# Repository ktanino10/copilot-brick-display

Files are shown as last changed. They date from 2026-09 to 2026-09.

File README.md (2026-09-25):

# Copilot Brick Display — public template

**[3案を回して見る・ダウンロード](https://ktanino10.github.io/copilot-brick-display/?rev=5.0-legible-plaques)**
 · **[作り方](docs/build.ja.md)** · **[Fork → Issue → AI → PRで文字を変える](docs/customize.ja.md)**

**個人向けB（本人公開許可済み）：**
[説明・作り方](https://ktanino10.github.io/copilot-brick-gift-b/) ／
[3D工程](https://ktanino10.github.io/copilot-brick-gift-b/guide/index.html) ／
[写真記録](https://ktanino10.github.io/copilot-brick-gift-b/docs/BUILD-LOG.html)。
別サイトへの案内です。この汎用版の `USER` 表記・匿名化写真・印刷データはそのままです。

**別PCで印刷する方へ：[色別ファイルの選び方と、黒→白の手動色替え](https://ktanino10.github.io/copilot-brick-display/guide.html?guide=separate-color-2026-09-19#print-another-pc)**
— A/B/Cを1案だけ選び、最初は試験片から。銘板・右ロゴの白い部分は一体レリーフで、途中の色替えが必要です。

**印刷した部品がどこに入るか分からない方へ：[ファイル → slot → 組立場所の対話3Dガイド](https://ktanino10.github.io/copilot-brick-display/assembly-guide/index.html)**
— 印刷順と組立順は違います。Bの最初は **`B-black-02.3mf` のslot 3 → `B-001`**。
[3D仕分け図・最初の台座アニメと使い方](docs/assembly.ja.md) ／ [Bのオフライン版](site/assembly-guide/B-offline.zip)。

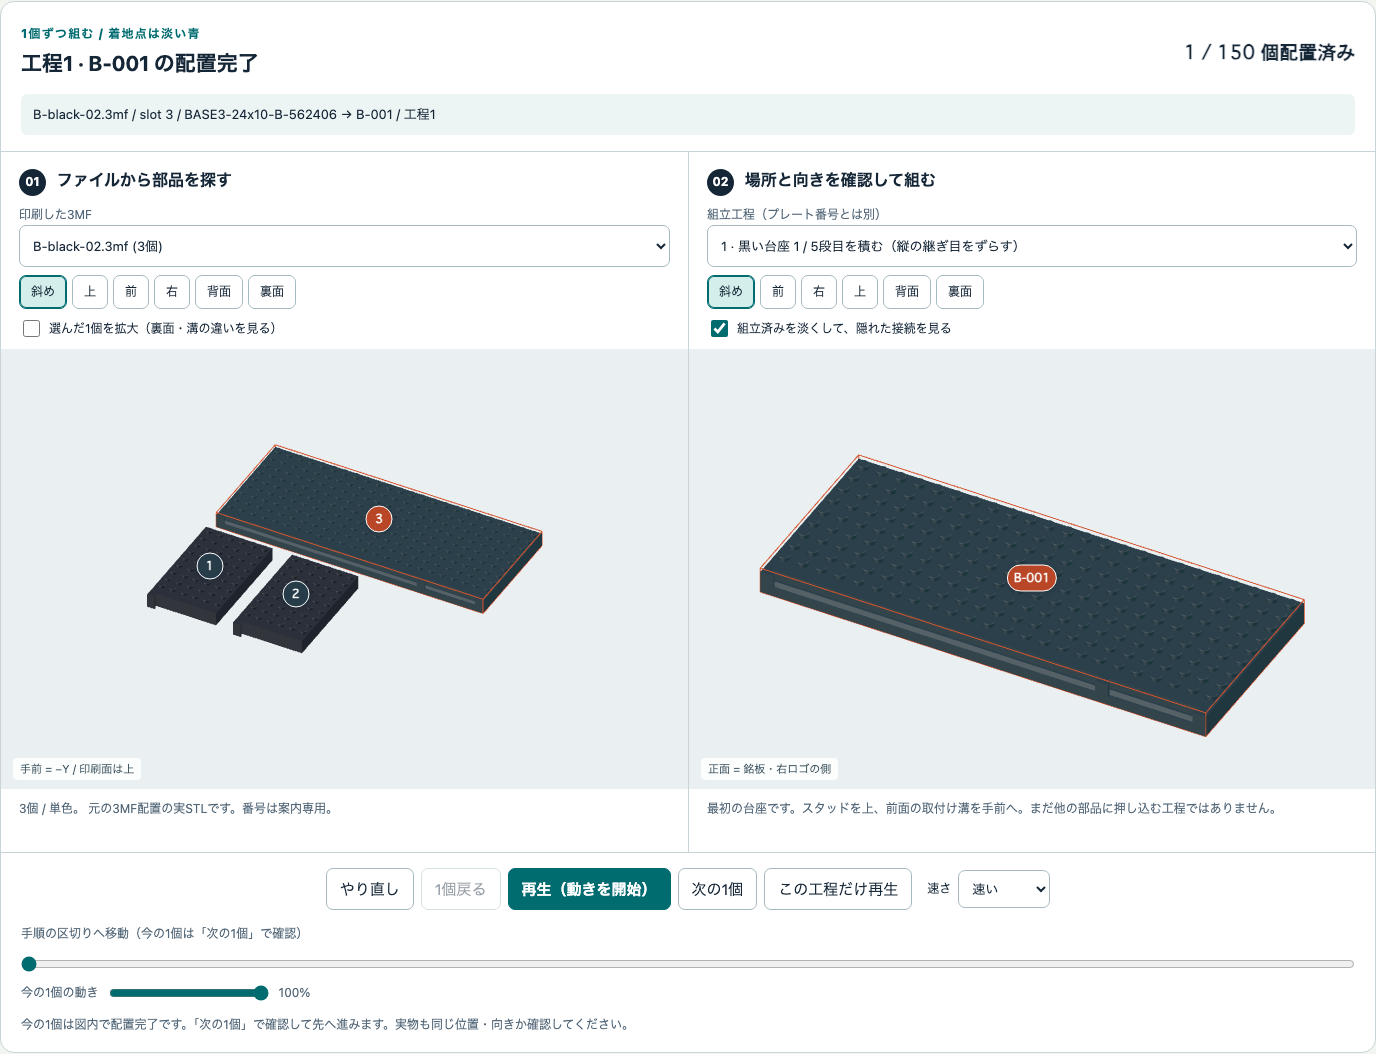
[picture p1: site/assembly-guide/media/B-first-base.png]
Bの印刷プレート内slot 3と最初の組立B-001を結ぶ実STL表示


**[実物の制作記録：個人向けBが完成しました（2026-09-25）](docs/build-log.ja.md#build-2026-09-25)**

本人の「これで完成ですね」という報告と、ゴーグル上枠・紫頭頂まで揃った完成写真を追加しました。
[9/23の台座](docs/build-log.ja.md#build-2026-09-23)・[9/24の顔下部](docs/build-log.ja.md#build-2026-09-24)からの記録も残しています。
写真の紫・黄は実制作例の配色です。設計配色は変えず、測定・版照合の範囲は制作ログに分けて記載しています。
[企画 → 設計 → 3Dプリント → 超音波洗浄 → アッセンブリーの制作フロー](docs/build-log.ja.md#flow-planning)と、
[印刷・超音波洗浄の2本の動画をページ内で見る](https://ktanino10.github.io/copilot-brick-display/build-log.html#printing-video)導線も用意しました（YouTube欄はオンライン限定）。

公開リビジョンは **`5.0-legible-plaques`**。黒い台座5段、大きい2行、正面右のロゴ、
無接着で交換できる前面部品を持つ非公式の卓上オブジェです。
公開の銘板は実際のCAD形状として次の仮表示を使います。実在の個人プロフィールではありません。

> Same icon, New adventures<br>
> github.com/USER

**[文字を印刷しやすくした改訂内容・実CAD比較](docs/lettering.ja.md)**：
2行目を全案10 mm、白文字を1.2 mm高へ。孔・開口・字間を広げ、背面の取付けと本体68種類は維持しました。
`USER`は実プロフィールへのリンクではない短い仮表記です。まず[文字の小試験片](site/downloads/lettering-coupons.zip)を選んだ案で印刷してください。

個人値はgitignore対象のローカルJSONへ分離できます。公開してよい値を使うforkでは、
Issue・PR・native・画像・動画・Actions artifact・Pagesにも表示されることを確認して、
明示的な公開承認モードを選びます。secretへ入れるだけでは生成物も秘密になる、とは扱いません。

## 同じ8 mmピッチ、3つの配置

| 案 | 完成寸法 W×D×H / mm | 組込部品数 | 特徴 |
| --- | --- | ---: | --- |
| A MINI RELIEF | 143.8 × 64.2 × 187.4 | 91 | 浅い顔、14段＋黒台座5段 |
| B DESK CLASSIC | 191.8 × 80.2 × 238.6 | 150 | 標準型、19段＋黒台座5段 |
| C DISPLAY SCULPT | 239.8 × 112.2 × 286.6 | 228 | 厚い側面、24段＋黒台座5段、最下段2分割 |

寸法は台座と最上部スタッド込み、部品数は銘板・ロゴ・3個のキーパー込み、試験片は別です。
文字以外の68種類のSTL、各案の配置・幅・高さ・接続寸法を維持しています。文字が0.4 mm厚くなった分だけ完成奥行きが増えています。
完成Cが256 mmより高くても、分割した各印刷部品はP1Sの公称造形体積内に収まります。
STLの一律拡大・縮小はしません。AMS・電子部品・接着剤・追加購入金具は不要です。

| 案 | FreeCAD | STEP | 印刷セット | 寸法・組立図 | Blender | 実組立動画 |
| --- | --- | --- | --- | --- | --- | --- |
| A | [FCStd](site/downloads/A/A.FCStd) | [STEP](site/downloads/A/A.step) | [ZIP](site/downloads/A/print-kit.zip) | [PDF](site/downloads/A/drawings.pdf) | [blend](site/downloads/A/A.blend) | [MP4](site/media/A-assembly.mp4) |
| B | [FCStd](site/downloads/B/B.FCStd) | [STEP](site/downloads/B/B.step) | [ZIP](site/downloads/B/print-kit.zip) | [PDF](site/downloads/B/drawings.pdf) | [blend](site/downloads/B/B.blend) | [MP4](site/media/B-assembly.mp4) |
| C | [FCStd](site/downloads/C/C.FCStd) | [STEP](site/downloads/C/C.step) | [ZIP](site/downloads/C/print-kit.zip) | [PDF](site/downloads/C/drawings.pdf) | [blend](site/downloads/C/C.blend) | [MP4](site/media/C-assembly.mp4) |

文字とロゴは独立した実レリーフです。黒から白へ、銘板は2.4 mm、ロゴは2.8 mm層後に手動色替えします。
キーパーを上へ6 mm、手前へ32 mm以上外して脇に置き、そのモジュールを45 mm以上上抜きして交換します。
3D分解100%は下側を下へ、上側を上へ広げ、段間は18.2 mm以上。表示用移動で、物理シミュレーションではありません。

## 作る前に

- [7個だけ、段階を分けて試す](docs/trial.ja.md) — 別試験の「扱いにくい・穴が塞がる」という失敗観察を反映。形状を変えず代表部品を少量選択。
- [初心者向けの作り方](docs/build.ja.md) — 条件照合、レイヤープレビュー、男女coupon、仕分け、組立・交換・停止条件。
- [設計の根拠](docs/design.md)／[再生成](docs/rebuild.md)／[公開・privateの文字変更](docs/customize.ja.md)。
- [公開テンプレートの検査記録](site/downloads/validation.json) — native、mesh、描画、配布物とprivate出力経路の検査を区別。

**実物の嵌合・keeper保持・PLA強度・耐久性・転倒は未試験です。**
個人向けBの[制作過程と完成報告](docs/build-log.ja.md#build-2026-09-25)は写真付きで記録し、測定による物理試験とは区別しています。
0.4 mm本体／0.2 mm文字は未実機検証のbaselineです。まず試験片を刷り、閉塞・つかみにくさ・着座不良があれば全数印刷を止めます。
無理押し・打撃・穴を一個ずつ削ることを完成キットの前提にしません。成人向けの屋内装飾品で、玩具安全認証はありません。

## プライバシーと権利

個人向けの旧配布と関連する到達可能な公開履歴を清掃し、元データはprivateに保管しています。
未選択の個別バリエーションは公開配布していません。
**GitHub側の旧SHAオブジェクトや外部キャッシュまで完全消去できたとは主張しません。**
[清掃範囲・残存限界・再混入防止](docs/privacy.md)を参照してください。

GitHub・LEGO・Bambu Labの公認商品ではありません。包括ライセンスは未設定です。
フォント・Three.js等の[noticeと権利条件](docs/licensing.md)を確認してください。

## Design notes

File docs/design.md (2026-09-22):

# Revision 3 / Five-course base and independent front modules

Current normal-model revision: **`5.0-legible-plaques`**.

**Manufacturing guidance update `trial-2026-09-19`: no geometry change.**
A [separate public 4 mm trial report](https://github.com/ktanino10/octoprints-brick-kit-downloads/blob/be956ae14d2aac1601a4a2a87f2e49675a36979e/feedback/2026-09-19/README.md)
describes handling difficulty and plastic-obstructed holes. Its actual sliced input/settings and
root cause were not established. This is failure evidence for another design, not a physical
pass for A/B/C or a reason to import its clearance values, media, geometry or license.
Our normal 8 mm stud/tube blocks, shallow keeper sockets and reserved-front-row base/keyway
parts still need layer-preview and real handling checks.
[The staged seven-piece selection](trial.ja.md) adds only unchanged current STL and small BOMs,
reuses existing fit coupons, and stops bulk printing on obstruction, poor grip or failed seating.
The existing 0.4/0.2 mm recommendations remain untested baselines.

The five-course layout is retained, but public message geometry now uses explicit placeholders.
No historical personal preview is republished as evidence for the generic text.
The non-text shape and placement contract is recorded in
[public-template-invariants.json](../design/public-template-invariants.json).
It is not a physical fit, strength or production qualification.

## One geometric source

`design/parameters.json` and `scripts/design.py` define pitch, courses, unique part IDs,
colors/finishes, quantities, placements and numbered steps. `design/catalog.json` is generated
and populated with actual FreeCAD measurements. `scripts/freecad_geometry.py` owns the unchanged
brick family; `scripts/front_nameplate.py` owns the new front interfaces and reliefs.

Actual FreeCAD BREP → FCStd / STEP / mm STL → the same meshes in Blender and the WebGL viewer.
TechDraw projections and planar sections are used for manufacturing drawings. Numbered plan
views are explicitly placement diagrams from the same catalogue. No raster-only or texture-only
lettering/logo substitutes for the delivered solid geometry.

Unchanged face/crest parts keep their original STL hashes and move only **+38.4 mm in Z**.
The source/cache recipes and B preview parts are reused instead of recalculating unchanged solids.
The five-course base is visible throughout the assembly sequence, so affected scenes, drawings
and movie frames are genuinely regenerated from the revised placements.

The unselected individual variant is preserved privately and is not distributed or regenerated.
Normal A/B/C use **`BASE-FRONT-NP3`**. Private historical interfaces and personal inputs are not
fetched from withdrawn revisions to rebuild this public template.

## Nominal references versus design choices

The LEGO-filed patent [WO2019106129A1](https://patents.google.com/patent/WO2019106129A1/en)
describes an approximate 32×16×9.6 mm four-by-two brick and approximate 4.8 mm knobs.
It does not specify this project's FDM tolerances. Museum and community references in
[sources.json](../design/sources.json) support the 8 mm grid / 3.2 mm plate convention
but disagree about some measured stud dimensions.

Our adjustable candidates remain: 1.8 mm stud height, 0.2 mm total body gap, default female
radial clearance +0.04 mm, usual roof 1.6 mm, thin-plate roof 1.0 mm, internal tube bore
3.2 mm and roof ribs 1.2 mm. Internal bores are not a claimed commercial accessory interface.

| Feature | Constraint / default |
| --- | --- |
| Body sides | `0.1 .. 8*n−0.1`; stud centers `4+8*i` |
| Inside-wall coordinate | `4−2.4−c = 1.56 mm`; physical outer wall 1.46 mm |
| Multi-row tube outside radius | `8/sqrt(2)−2.4−c = 3.216854 mm` |
| One-row post radius | `4−2.4−c = 1.56 mm` |
| Tube radial wall | 1.616854 mm |
| Grid ribs | 1.2 mm at nominal row/column boundaries; reference stud clearance ≥1.0 mm |
| Orthogonal roof span | ≤6.8 mm between ribs; tube bores 3.2 mm |
| Thin plate headroom | `3.2−1.0−1.8 = 0.4 mm` |

An ideal reference stud has nominal positive clearance at the default setting. This does not
prove frictional clutch. Independent male-diameter and female-clearance coupons must be printed
and tested with actual commercial and printed mates. PLA is not ABS; do not force, lever or hammer.

## Real five-course bases

| Model | Actual W×D×H, mm | Installed parts | Base blocks / courses | Unchanged face courses |
| --- | --- | --- | --- | --- |
| A | 143.8 × 64.2 × 187.4 | 91 | 15 / 5 | 14 |
| B | 191.8 × 80.2 × 238.6 | 150 | 19 / 5 | 19 |
| C | 239.8 × 112.2 × 286.6 | 228 | 24 / 5 | 24 |

The base body is **48 mm = 5×9.6 mm**, with independent, printable, separable blocks—not one
large solid box with drawn seams. Upper courses alternate six-stud runs and half-offset
three/six-stud runs. C retains two 15×14-stud bottom halves; subsequent courses span their seam.
Each block spans its designed depth, so front and rear are not unrelated thin skins.

The first front 8 mm row is deliberately reserved for the two vertical channels:
its top studs are removed and its underside is reinforced rather than a commercial socket.
Rows starting at Y=12 mm keep the fixed grid. The lowest face parts start at Z=48 mm behind
the front interfaces. Neither the face nor the block pitch is scaled.

C's assembled height exceeding the printer's 256 mm nominal volume is not a printing violation:
only individual parts are printed. The largest B footprint plus 6 mm external brim is
203.8×91.8 mm; each C bottom half plus brim is 131.8×123.8 mm. Actual plate exclusions,
toolpaths, warping and first layers still require a slicer and real print check.

## Two-line message and right-hand logo

The exact text is:

> Same icon, New adventures<br>
> github.com/USER

There is no handle line on the normal models. The standalone raised cyan sign and its old dock
are removed from A/B/C. The current message and logo are black-backed front inserts with white
relief, entirely inside the five-course base at **Z=4..44 mm**.

| Model | Message backing W×H | Main / URL actual cap height | Logo disc / backing width |
| --- | --- | --- | --- |
| A | 102×40 mm | 10 / 10 mm | 28 / 32 mm |
| B | 142×40 mm | 12 / 10 mm | 36 / 40 mm |
| C | 182×40 mm | 14.5 / 10 mm | 40 / 48 mm |

Barlow Condensed Bold is used for the main line, preserving its X scale and declared ink height;
Black is enlarged uniformly to10mm for the shorter URL placeholder. Existing kerning is preserved
when adequate, otherwise additional spacing is inserted. Inner counters and the e's right opening
are enlarged without inflating the entire outline. `USER` is an explicit placeholder, not a profile link.
In B the actual ink widths are132.1301 and77.4228mm within134mm; the carrier remains142×40mm.
See [the measured typography change](lettering.ja.md) and `validation/lettering.json` for
central-band counter chords, actual BRep gaps, approximate open-pocket escape diameters,
straight positive strokes and persistent material-neck indicators. A uses explicitly lower
main-line gap/counter targets to fit without thinning or shortening its text.
These are not physical-print measurements or guarantees for every mathematical curve terminal.

The mark is vectorized from the user-provided black-circle/white silhouette image. Only the
derived normalized outline coordinates and solid relief are published, not the input raster
or its private path. A black carrier supports the black circular pad and all white relief,
including the tail and ears. This is an unofficial personal model, not an endorsed product.

Print both modules rear-face-down. The message carrier is 2.4 mm thick with 1.2 mm raised text.
The logo adds a 0.4 mm black disc before its 0.8 mm white relief. Manual black-to-white changes
occur after **2.4 mm** for text and **2.8 mm** for the logo. These are separate print plates;
do not mix other black blocks into a plate that will change to white. AMS is not required.
The extra0.4mm of text projects forward toY=-0.30, increasing only the assembled depth by0.4mm.
The original68 non-text masters, carrier geometry, installation poses, width and height are unchanged.

## Positive geometry and removal

Each module has a wider rear face and a front face narrowed by 2 mm per X side.
The default receiver side allowance is 0.2 mm; small C15/C20/C25 receiver coupons are provided.
The back-to-front transition is 2.4 mm deep, with a 0.8 mm initial flat back and 1.2 mm vertical
edge relief. The printable widening slope is no steeper than 45° to vertical.

The matching dovetail channels run vertically through the five aligned courses. Shaped bottom
seats stop downward motion. Their side geometry blocks frontward and lateral pulling;
**two message keepers and one separate logo keeper** block upward escape. Keepers engage the
second stud row. Their physical clutch is a calibration requirement, not an assumed certified force.

For replacement, lift the relevant keeper(s) approximately 6 mm, move them at least 32 mm forward and set them aside,
then slide that module straight up at least 45 mm before taking it forward. The other front
module can remain installed. Face parts are behind this path, with nominal Y clearance.
Never lift the entire object by a module, keeper, head or goggles.

Digital checks test final solids, blocked translations, released vertical samples, and the
staged viewer route. They do not prove arbitrary forced motion, elastic deformation, wear,
human grip strength, clutch force or printed durability.

## Strong vertical exploded view

0% is exactly the completed catalogue pose. The initial slider phases first lift the keepers,
move them forward, then lift and move both front modules clear. The forward distance is computed
as at least the keeper's 16 mm nominal depth plus the module's 14 mm forward travel plus a 2 mm
display clearance: 32 mm. The requested minimum `keeper_forward_mm` cannot override that safety envelope. The remaining range separates
courses around a central reference: lower courses move down and upper courses move up.

At 100%, each neighboring body/base course receives 20 mm relative display displacement.
The resulting clear gap, including 1.8 mm studs, is at least **18.2 mm**. All five base courses
participate. Small front modules are displayed below the base only after the safe initial
clearance route. This is explanatory movement, not an instruction to pull the whole model apart
simultaneously or a physical simulation.

Cached local bounds are rotated once and translated per update; no full-vertex scan or new
geometry is created every frame. Camera target, orthographic frustum and clipping use visible
exploded bounds while preserving the current view direction. Actual desktop/mobile 0/50/100%
screenshots, gap checks, return-to-zero, selection and assembly-control checks are release gates.

## Review and physical boundary

One mechanical owner integrates the change; the same separate mechanical reviewer reviews a
fixed changed snapshot and its final presentations. Native reopen, STEP/STL consistency,
watertight meshes, contact/retention geometry, body hashes, BOM/steps, actual Blender scenes,
video decode and public download hashes are recorded separately.

The material centroid is a uniform solid-CAD proxy, not sliced mass or a measured tipping load.
The increased height requires a fresh real-world stability check on a low, flat, safe surface.
Physical fit, printed-thread or stud wear, PLA strength, clutch, heat resistance, print time/mass,
tip resistance and toy safety remain **unverified**. Print the calibration pieces first.

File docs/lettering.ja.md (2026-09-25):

# 銘板の印刷しやすさ — 5.0改訂と小試験片

**公開版の2行は `Same icon, New adventures` / `github.com/USER` です。**
`USER`は短い仮表記であり、実在の人やプロフィールへのリンクではありません。
長い仮文字列を無理に細く収めるのでなく、短い公開例にすることをユーザーが選択しました。
個人向け入力の文言をこの仮表記へ変更する仕組みではありません。

0.2 mmノズルでの試作から「文字が小さい・孔や字間が狭い」というフィードバックを受けた設計候補です。
**この改訂を実機印刷して合格した証拠はまだありません。**
09/23には個人向けBで本人の改善感と台座・前面部品の写真報告が届き、[制作記録](build-log.ja.md)へ追加しました。
09/24の[顔下部を積む途中写真](build-log.ja.md#build-2026-09-24)に続き、09/25は[個人向けBの完成報告と全体写真](build-log.ja.md#build-2026-09-25)を追記しました。写真の実制作色は設計配色と区別しています。
現物に使ったファイル・設定の版は未照合なので、この公開版の実物合格とは扱いません。
糸引きや上面の荒れの原因を写真だけで温度・flow等へ断定していません。
未加工の原写真は載せず、許可された制作記録用の識別情報除去済み画像だけを別ページで示します。

## 変えたもの・変えないもの

主文はBarlow Condensed **Bold**、下段は**Black**です。主文の文字高はA10 / B12 / C14.5 mmを維持し、
URLは全案10 mmへ均等拡大しました。元のkerningを保ち、不足する字間だけを追加します。
閉じた孔の内側と`e`の右出口を広げ、白い文字の高さを0.8→**1.2 mm**にしました。
全行の横圧縮、文字の切捨て、3行化はしていません。

黒い支持体は**2.4 mmのまま**、銘板全厚は**3.6 mm**。各案の裏面・キー溝取付け・顔・台座・右ロゴ・68非文字STLは不変更です。
文字が0.4 mm前へ出た分、完成奥行きはA64.2 / B80.2 / C112.2 mmになりました。
幅・高さ・全配置・組込個数91 / 150 / 228は維持しています。右ロゴの白レリーフは0.8 mmのままです。

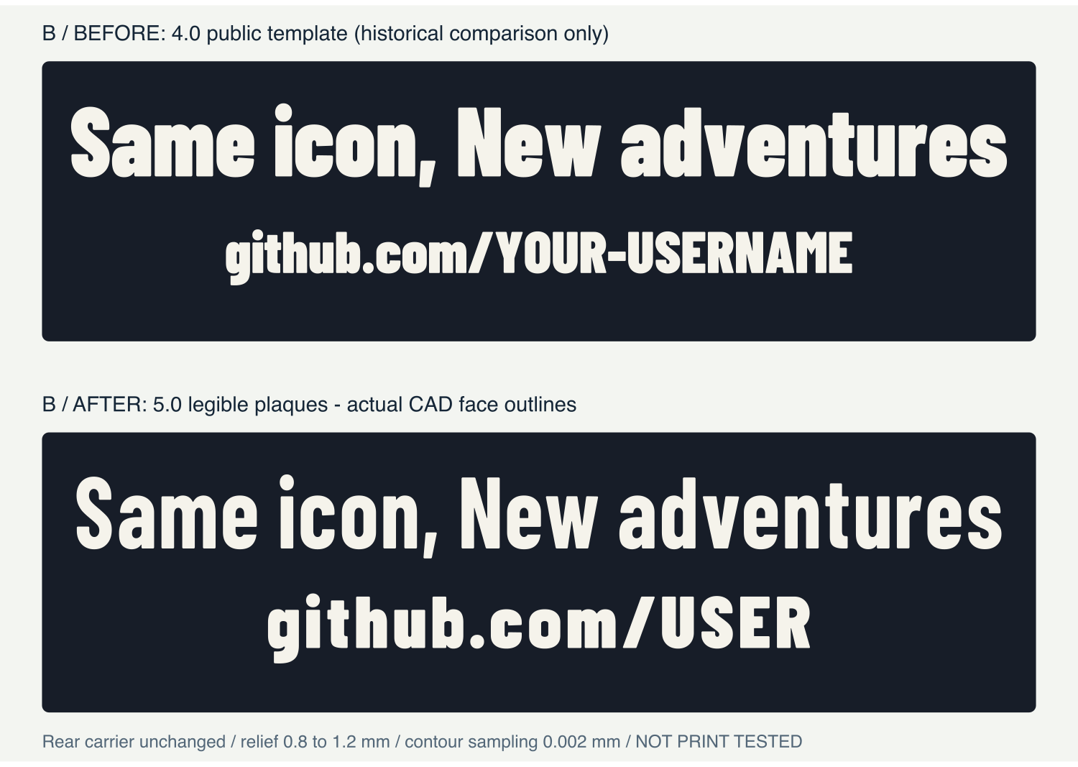
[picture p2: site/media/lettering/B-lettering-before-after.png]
Bの旧4.0と新5.0の実CAD比較。旧データは比較用で、現在の印刷用ではありません


上図は保存済みCADの実面輪郭から作成しています。旧4.0の長い仮表示は**歴史的な比較用**で、印刷用データではありません。
元の旧版はGitの版履歴で区別し、現在のダウンロードには新旧の銘板を混在させません。

## 文字列ごとの実測

| 案・行 | 実文字高 | 実インク幅 / 上限 | 最小字間 | 平行な正の直線幅 | 持続的な材料neck指標 |
| --- | ---: | ---: | ---: | ---: | ---: |
| A 主文 | 10 mm | 93.638 / 94 mm | 0.796 mm | 1.196 mm | 0.85 mm |
| B 主文 | 12 mm | 132.130 / 134 mm | 1.048 mm | 1.261 mm | 1.09 mm |
| C 主文 | 14.5 mm | 167.331 / 174 mm | 1.048 mm | 1.524 mm | 1.34 mm |
| 全案 URL | 10 mm | 77.423 / 各案上限 | 1.048 mm | 1.689 mm | 1.17 mm |

Aの主文は狭い102 mm支持体に収めるため、孔の中央帯目標0.90 mm、`e`出口0.95 mm、字間0.80 mmを明示的に使用します。
B/C主文と全案のURLは孔1.02 mm、`e`出口1.10 mm、字間1.05 mmの目標です。
**A主文を全字1 mm以上と称していません。** 小型の幅を守った選択で、Aの文字試験片を別に確認します。

測定定義はそれぞれ別です。

- **閉counter**：孔の高さ・幅の中央25–75%帯に、それぞれ101本置いた横・縦chordの最小値。
  最大内接円の直径とは異なり、鋭い三角孔の全先端幅を保証しません。
- **c/eの開口**：0.01 mm格子で内側から外へ抜ける経路を測る近似。誤差は約±0.03 mm。
- **字間**：最終BRepの隣接する字形間の実距離。0.002 mm輪郭samplingによる計画値とは最大0.006 mm差を許容し、表は実値です。
- **正の材料**：平行直線の幅と、侵食した時に0.05 mm²以上の2領域へ分裂する最初の幅（半径0.005 mm刻み）を別々に報告。
  全ての曲線先端やスライサーの線幅を保証する値ではありません。

孔を広げても材料が細くなる文字は停止対象です。長い別handleや大文字を入れても、上の結果を引き継げるとは限りません。
生成器は文字列・幅・字間・正の材料を再検査し、未成立を無音で縮小・修復しません。
機械可読の測定は[lettering.json](../site/downloads/lettering.json)で確認できます。

## 本体銘板より先に、選んだ案の文字だけ試す

**[文字試験片ZIP](../site/downloads/lettering-coupons.zip)** を展開し、
選んだA/B/Cに対応する **`GLYPH-A` / `GLYPH-B` / `GLYPH-C` を1個だけ**使います。
STLと3MFは代替ファイルです。同時に読み込まないでください。
上段`aeod`、下段`gbo./R`を、実銘板の字形から**拡大縮小なし**で取り出し、同じ字間目標で並べ直しています。
大きな台座全体を印刷せず、孔・`e`・dot/slash・下段の大小文字を先に確認できます。
この平らな試験片には取付け機構はなく、完成BOMや150個の組立には入りません。

1. 3MFは形状・配置だけの **NOT_SLICED**。実P1S・実際の装着ノズル・PLA・プレートを選びます。mm・100%・平らな黒支持体を下。
2. 実レイヤープレビューで、孔が埋まらないか、細線のpath欠落、隣字間の橋、dot/slashの形を確認します。
3. 黒支持体2.4 mmが終わり、**最初の白い経路を出す前**へPauseを追加します。初層・可変層高で層番号が変わるので固定番号は指定しません。
   白は1.2 mm。標準P1Sの交換・排出・再開操作に従い、未検証G-codeは使いません。
4. 冷めたら孔・出口・字間が開いているか、欠け・白化・反り・糸・上面荒れを確認し、ノギスとスライス画像・条件を記録します。
5. 閉塞、線の脱落、割れがあれば銘板の全数印刷を停止。0.2 mmで解決済みとはみなしません。
   原因不明のまま穴径・XY補正・flow・温度を一括変更せず、現物と経路を照合して一条件ずつ見直します。

実設定入りBambu Studioプロジェクトは未受領です。必要な診断情報は**実際に使った設定入り`.3mf`**であり、
個人情報を含むなら公開IssueやPagesへ置かず、非公開で扱ってください。
文字試験片が成功しても、既存FIT/NP3-FIT、keeper保持、完成品の強度・転倒は別の未検証事項です。

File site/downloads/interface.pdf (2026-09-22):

BRICK PORTRAIT / PUBLIC TEMPLATE / 5-COURSE BASE / DIGITAL PROTOTYPE

# INTERFACE / SECTION & CLEARANCE

Project design candidates, NOT a proprietary tolerance standard. Geometry from FreeCAD planar sections.

SECTION: Y = 4.00 / TWO 2x2 BRICKS

JOINT SECTION: Z = 10.50

Actual wall, tube, rib + mating stud outlines

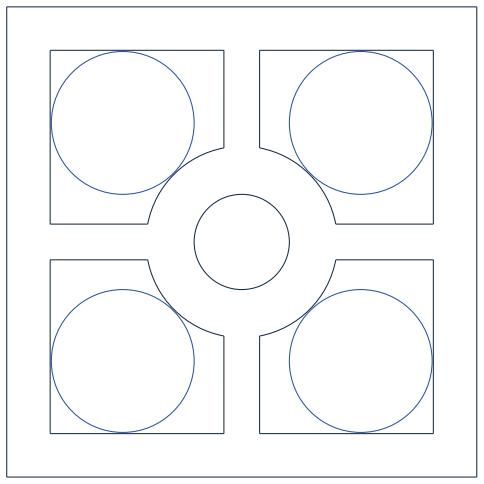
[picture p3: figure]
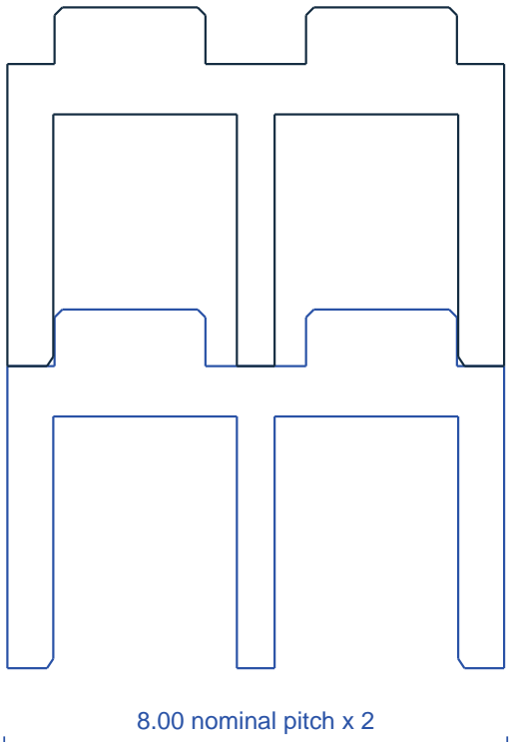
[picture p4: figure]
8.00 nominal pitch x 2

Blue: lower brick / black: upper socket

Reference stud dia 4.80; candidate height 1.80 Radial clearance c=+0.04 (default; untested)

Inside wall offset 1.56 / wall thickness 1.46

Tube OD 6.433708 / ID 3.20; grid rib 1.20

Tip lead-in 0.25 / female lead-in 0.20 x 0.30

Roof 1.60; thin plate roof 1.00

Thin plate / keeper: nominal headroom 0.40

No forced fit. Tune male and female separately.

UNITS mm | Fixed 8 mm pitch | Physical fit / strength / stability NOT tested | Do not scale STL. Calibrate male + female coupons first.

BRICK PORTRAIT / PUBLIC TEMPLATE / 5-COURSE BASE / DIGITAL PROTOTYPE

# NP3 / BASE-FRONT CAPTURE & REMOVAL

Actual BREP sections; precise dimensions apply to the nominal model, not guaranteed printed fit.

B / HORIZONTAL SECTION Z=24 / FRONT 8mm BAND

B message: 142.00

B logo carrier: 40.00

VERTICAL SECTION X=40

48.00

Blue: installed modules; black: actual receiver / keepers

Carrier thickness2.40 / rear flat0.80 / edge relief1.20

Rear width -> front width: 2.00 inset on each X side

Default side clearance0.20; coupon candidates0.15/0.20/0.25

Text frontY=-0.30 / logo frontY=0.10; +0.40mm depth

Both front modules fit in Z=4.00..44.00, inside48mm base

3 separate up-stops: text2 / logo1; stud-grid mounting

Remove: up-stops up6, forward>=32; module up45

Thread / glue / magnet / purchased fastener not required

Physical clutch, retention, flatness and stability NOT tested

UNITS mm | Fixed 8 mm pitch | Physical fit / strength / stability NOT tested | Do not scale STL. Calibrate male + female coupons first.

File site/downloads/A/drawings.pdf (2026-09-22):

### BRICK PORTRAIT / PUBLIC TEMPLATE / 5-COURSE BASE / DIGITAL PROTOTYPE

# A / MINI RELIEF

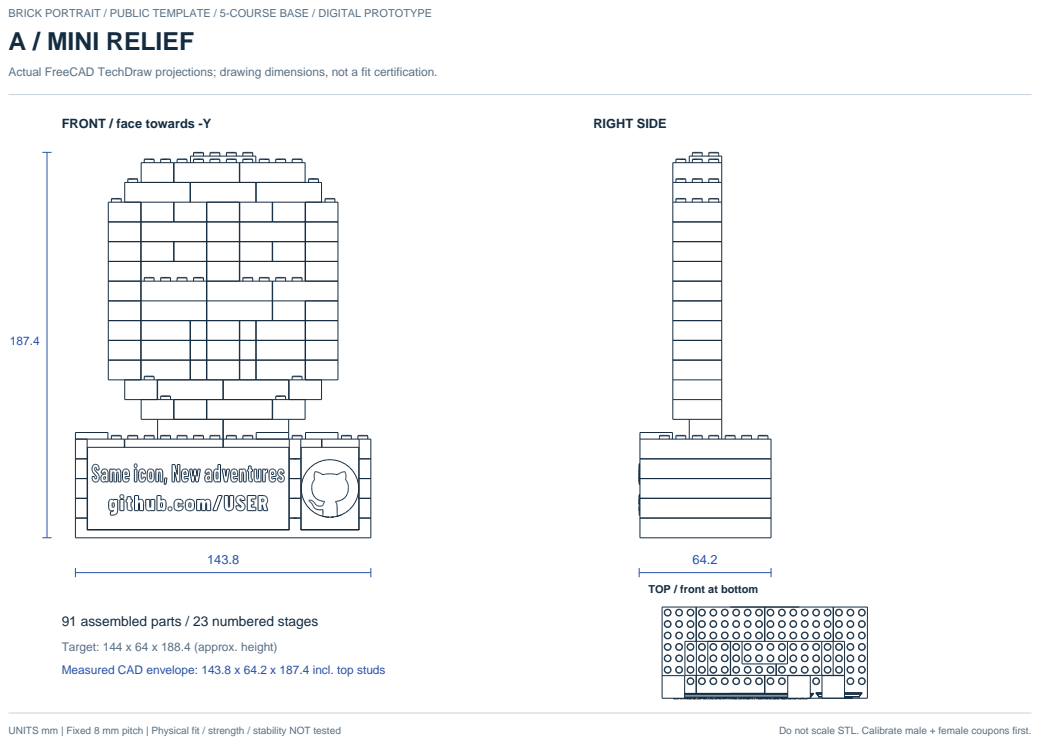
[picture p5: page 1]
RIGHT SIDE; UNITS mm | Fixed 8 mm pitch | Physical fit / strength / stability NOT tested; Do not scale STL. Calibrate male + female coupons first.

Actual FreeCAD TechDraw projections; drawing dimensions, not a fit certification.

FRONT / face towards -Y

TOP / front at bottom

91 assembled parts / 23 numbered stages

Target: 144 x 64 x 188.4 (approx. height)
Measured CAD envelope: 143.8 x 64.2 x 187.4 incl. top studs

# A / EXPLODED ASSEMBLY

CAD-derived exploded view; displacement is illustrative, dimensions are not changed.

# EXPLODED FRONT

Actual solids, displaced only for this view.

Exact WebGL 100% offsets, centered up/down.

Do not measure assembly height here.

Use overview for final outside dimensions.

Insert parts downward in numbered order.

Front modules release before spreading.

Stud engagement != verified physical clutch.

## TEXT / flat printing view

## RIGHT LOGO / supported relief

# INTERFACE / SECTION & CLEARANCE

Project design candidates, NOT a proprietary tolerance standard. Geometry from FreeCAD planar sections.

## SECTION: Y = 4.00 / TWO 2x2 BRICKS

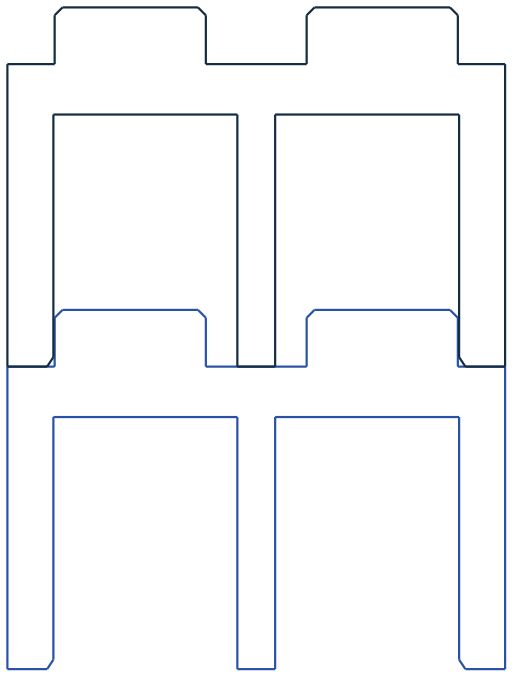
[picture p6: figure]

## 8.00 nominal pitch x 2

## JOINT SECTION: Z = 10.50

### Actual wall, tube, rib + mating stud outlines


### Blue: lower brick / black: upper socket

### Reference stud dia 4.80; candidate height 1.80

### Radial clearance c=+0.04 (default; untested)

### Inside wall offset 1.56 / wall thickness 1.46

### Tube OD 6.433708 / ID 3.20; grid rib 1.20

### Tip lead-in 0.25 / female lead-in 0.20 x 0.30

### Roof 1.60; thin plate roof 1.00

### Thin plate / keeper: nominal headroom 0.40

No forced fit. Tune male and female separately.

# NP3 / BASE-FRONT CAPTURE & REMOVAL

Actual BREP sections; precise dimensions apply to the nominal model, not guaranteed printed fit.

## B / HORIZONTAL SECTION Z=24 / FRONT 8mm BAND

## B message: 142.00

## B logo carrier: 40.00

## VERTICAL SECTION X=40

48.00

## Blue: installed modules; black: actual receiver / keepers

## Carrier thickness2.40 / rear flat0.80 / edge relief1.20

## Rear width -> front width: 2.00 inset on each X side

## Default side clearance0.20; coupon candidates0.15/0.20/0.25

## Text frontY=-0.30 / logo frontY=0.10; +0.40mm depth

## Both front modules fit in Z=4.00..44.00, inside48mm base

## 3 separate up-stops: text2 / logo1; stud-grid mounting

## Remove: up-stops up6, forward>=32; module up45

## Thread / glue / magnet / purchased fastener not required

## Physical clutch, retention, flatness and stability NOT tested

# A / COLOR BOM / 1

One STL geometry may be printed in several colors. Use the quantities for this model only.

PART ID | COLOR | QTY | PRINT FILE
BASE3-03x08-T-48de52 | black | 2 | parts/BASE3-03x08-T-48de52.stl
BASE3-03x08-T-80e081 | black | 2 | parts/BASE3-03x08-T-80e081.stl
BASE3-06x08-T-7532db | black | 2 | parts/BASE3-06x08-T-7532db.stl
BASE3-06x08-T-7f51dc | black | 2 | parts/BASE3-06x08-T-7f51dc.stl
BASE3-06x08-T-9cb610 | black | 4 | parts/BASE3-06x08-T-9cb610.stl
BASE3-06x08-T-b8aa05 | black | 2 | parts/BASE3-06x08-T-b8aa05.stl
BASE3-18x08-B-a4853c | black | 1 | parts/BASE3-18x08-B-a4853c.stl
BR-01x02-H096 | green | 6 | parts/BR-01x02-H096.stl
BR-02x02-H096 | black | 13 | parts/BR-02x02-H096.stl
BR-02x03-H096 | cyan | 14 | parts/BR-02x03-H096.stl
BR-02x03-H096 | magenta | 12 | parts/BR-02x03-H096.stl
BR-03x02-H096 | black | 6 | parts/BR-03x02-H096.stl
BR-04x02-H032 | magenta | 1 | parts/BR-04x02-H032.stl
BR-04x02-H096 | black | 9 | parts/BR-04x02-H096.stl
BR-04x02-H096 | magenta | 2 | parts/BR-04x02-H096.stl
BR-04x03-H096 | cyan | 8 | parts/BR-04x03-H096.stl
NP3-KEEPER | black | 3 | parts/NP3-KEEPER.stl
NP3-LOGO-A | black | 1 | parts/NP3-LOGO-A.stl
NP3-TEXT-A | black | 1 | parts/NP3-TEXT-A.stl

TEXT: black -> white at 2.4mm; LOGO: black -> white at 2.8mm. Separate plates.

Assembly: 91 pieces, including 2 front modules + 3 keepers. Coupons separate.

# A / STEP 01 OF 23

Placement diagram from canonical part bounds. IDs match native CAD, BOM, viewer and animation.

## PLAN VIEW / front at bottom / NEW parts in color

001

## nominal 144 / grid 8.00

## FRONT (-Y) / new parts enter from above (+Z)

# ADD 1 PART(S)

### A-001 BLACK

BASE3-18x08-B-a4853c @ 0,0,0

# A / STEP 02 OF 23

Placement diagram from canonical part bounds. IDs match native CAD, BOM, viewer and animation.

## PLAN VIEW / front at bottom / NEW parts in color

002 | 003 | 004

## nominal 144 / grid 8.00

## FRONT (-Y) / new parts enter from above (+Z)

# ADD 3 PART(S)

### A-002 BLACK

BASE3-06x08-T-b8aa05 @ 0,0,9.6

### A-003 BLACK

BASE3-06x08-T-9cb610 @ 48,0,9.6

### A-004 BLACK

BASE3-06x08-T-7f51dc @ 96,0,9.6

# A / STEP 03 OF 23

Placement diagram from canonical part bounds. IDs match native CAD, BOM, viewer and animation.

## PLAN VIEW / front at bottom / NEW parts in color

005 | 006 | 007 | 008

## nominal 144 / grid 8.00

## FRONT (-Y) / new parts enter from above (+Z)

# ADD 4 PART(S)

### A-005 BLACK

BASE3-03x08-T-48de52 @ 0,0,19.2

### A-006 BLACK

BASE3-06x08-T-9cb610 @ 24,0,19.2

### A-007 BLACK

BASE3-06x08-T-7532db @ 72,0,19.2

### A-008 BLACK

BASE3-03x08-T-80e081 @ 120,0,19.2

# A / STEP 04 OF 23

Placement diagram from canonical part bounds. IDs match native CAD, BOM, viewer and animation.

## PLAN VIEW / front at bottom / NEW parts in color

009 | 010 | 011

## nominal 144 / grid 8.00

## FRONT (-Y) / new parts enter from above (+Z)

# ADD 3 PART(S)

### A-009 BLACK

BASE3-06x08-T-b8aa05 @ 0,0,28.8

### A-010 BLACK

BASE3-06x08-T-9cb610 @ 48,0,28.8

### A-011 BLACK

BASE3-06x08-T-7f51dc @ 96,0,28.8

# A / STEP 05 OF 23

Placement diagram from canonical part bounds. IDs match native CAD, BOM, viewer and animation.

## PLAN VIEW / front at bottom / NEW parts in color

012 | 013 | 014 | 015

## nominal 144 / grid 8.00

## FRONT (-Y) / new parts enter from above (+Z)

# ADD 4 PART(S)

### A-012 BLACK

BASE3-03x08-T-48de52 @ 0,0,38.4

### A-013 BLACK

BASE3-06x08-T-9cb610 @ 24,0,38.4

### A-014 BLACK

BASE3-06x08-T-7532db @ 72,0,38.4

### A-015 BLACK

BASE3-03x08-T-80e081 @ 120,0,38.4

# A / STEP 06 OF 23

Placement diagram from canonical part bounds. IDs match native CAD, BOM, viewer and animation.

## PLAN VIEW / front at bottom / NEW parts in color

016 017

## nominal 144 / grid 8.00

## FRONT (-Y) / new parts enter from above (+Z)

# ADD 2 PART(S)

### A-016 BLACK

NP3-TEXT-A @ 4,3.3,4

### A-017 BLACK

NP3-LOGO-A @ 108,3.7,4

# A / STEP 07 OF 23

Placement diagram from canonical part bounds. IDs match native CAD, BOM, viewer and animation.

## PLAN VIEW / front at bottom / NEW parts in color

018 | 019 | 020

## nominal 144 / grid 8.00

## FRONT (-Y) / new parts enter from above (+Z)

# ADD 3 PART(S)

### A-018 BLACK

NP3-KEEPER @ 0,0,48

### A-019 BLACK

NP3-KEEPER @ 88,0,48

### A-020 BLACK

NP3-KEEPER @ 112,0,48

# A / STEP 08 OF 23

Placement diagram from canonical part bounds. IDs match native CAD, BOM, viewer and animation.

## PLAN VIEW / front at bottom / NEW parts in color

021 022

## nominal 144 / grid 8.00

## FRONT (-Y) / new parts enter from above (+Z)

# ADD 2 PART(S)

### A-021 MAGENTA

BR-04x02-H096 @ 40,24,48

### A-022 MAGENTA

BR-04x02-H096 @ 72,24,48

# A / STEP 09 OF 23

Placement diagram from canonical part bounds. IDs match native CAD, BOM, viewer and animation.

## PLAN VIEW / front at bottom / NEW parts in color

023 | 026

024 025

## nominal 144 / grid 8.00

## FRONT (-Y) / new parts enter from above (+Z)

# ADD 4 PART(S)

### A-023 MAGENTA

BR-02x03-H096 @ 32,16,57.6

### A-024 BLACK

BR-02x02-H096 @ 48,24,57.6

### A-025 BLACK

BR-04x02-H096 @ 64,24,57.6

### A-026 MAGENTA

BR-02x03-H096 @ 96,16,57.6

# A / STEP 10 OF 23

Placement diagram from canonical part bounds. IDs match native CAD, BOM, viewer and animation.

## PLAN VIEW / front at bottom / NEW parts in color

027 | 030

028 029

## nominal 144 / grid 8.00

## FRONT (-Y) / new parts enter from above (+Z)

# ADD 4 PART(S)

### A-027 MAGENTA

BR-02x03-H096 @ 24,16,67.2

### A-028 BLACK

BR-04x02-H096 @ 40,24,67.2

### A-029 BLACK

BR-04x02-H096 @ 72,24,67.2

### A-030 MAGENTA

BR-02x03-H096 @ 104,16,67.2

# A / STEP 11 OF 23

Placement diagram from canonical part bounds. IDs match native CAD, BOM, viewer and animation.

## PLAN VIEW / front at bottom / NEW parts in color

031 | 037
032 | 033 | 034 | 035 | 036

## nominal 144 / grid 8.00

## FRONT (-Y) / new parts enter from above (+Z)

# ADD 7 PART(S)

### A-031 MAGENTA

BR-02x03-H096 @ 16,16,76.8

### A-032 BLACK

BR-03x02-H096 @ 32,24,76.8

### A-033 GREEN

BR-01x02-H096 @ 56,24,76.8

### A-034 BLACK

BR-02x02-H096 @ 64,24,76.8

### A-035 GREEN

BR-01x02-H096 @ 80,24,76.8

### A-036 BLACK

BR-03x02-H096 @ 88,24,76.8

### A-037 MAGENTA

BR-02x03-H096 @ 112,16,76.8

# A / STEP 12 OF 23

Placement diagram from canonical part bounds. IDs match native CAD, BOM, viewer and animation.

## PLAN VIEW / front at bottom / NEW parts in color

038 | 044
039 | 040 | 041 | 042 | 043

## nominal 144 / grid 8.00

## FRONT (-Y) / new parts enter from above (+Z)

# ADD 7 PART(S)

### A-038 MAGENTA

BR-02x03-H096 @ 16,16,86.4

### A-039 BLACK

BR-03x02-H096 @ 32,24,86.4

### A-040 GREEN

BR-01x02-H096 @ 56,24,86.4

### A-041 BLACK

BR-02x02-H096 @ 64,24,86.4

### A-042 GREEN

BR-01x02-H096 @ 80,24,86.4

### A-043 BLACK

BR-03x02-H096 @ 88,24,86.4

### A-044 MAGENTA

BR-02x03-H096 @ 112,16,86.4

# A / STEP 13 OF 23

Placement diagram from canonical part bounds. IDs match native CAD, BOM, viewer and animation.

## PLAN VIEW / front at bottom / NEW parts in color

045 | 051
046 | 047 | 048 | 049 | 050

## nominal 144 / grid 8.00

## FRONT (-Y) / new parts enter from above (+Z)

# ADD 7 PART(S)

### A-045 MAGENTA

BR-02x03-H096 @ 16,16,96

### A-046 BLACK

BR-03x02-H096 @ 32,24,96

### A-047 GREEN

BR-01x02-H096 @ 56,24,96

### A-048 BLACK

BR-02x02-H096 @ 64,24,96

### A-049 GREEN

BR-01x02-H096 @ 80,24,96

### A-050 BLACK

BR-03x02-H096 @ 88,24,96

### A-051 MAGENTA

BR-02x03-H096 @ 112,16,96

# A / STEP 14 OF 23

Placement diagram from canonical part bounds. IDs match native CAD, BOM, viewer and animation.

## PLAN VIEW / front at bottom / NEW parts in color

052 | 056
053 | 054 | 055

## nominal 144 / grid 8.00

## FRONT (-Y) / new parts enter from above (+Z)

# ADD 5 PART(S)

### A-052 MAGENTA

BR-02x03-H096 @ 16,16,105.6

### A-053 BLACK

BR-04x02-H096 @ 32,24,105.6

### A-054 BLACK

BR-04x02-H096 @ 64,24,105.6

### A-055 BLACK

BR-02x02-H096 @ 96,24,105.6

### A-056 MAGENTA

BR-02x03-H096 @ 112,16,105.6

# A / STEP 15 OF 23

Placement diagram from canonical part bounds. IDs match native CAD, BOM, viewer and animation.

## PLAN VIEW / front at bottom / NEW parts in color

057 | 058 | 059 | 060

## nominal 144 / grid 8.00

## FRONT (-Y) / new parts enter from above (+Z)

# ADD 4 PART(S)

### A-057 CYAN

BR-02x03-H096 @ 16,16,115.2

### A-058 CYAN

BR-04x03-H096 @ 32,16,115.2

### A-059 CYAN

BR-04x03-H096 @ 64,16,115.2

### A-060 CYAN

BR-04x03-H096 @ 96,16,115.2

# A / STEP 16 OF 23

Placement diagram from canonical part bounds. IDs match native CAD, BOM, viewer and animation.

## PLAN VIEW / front at bottom / NEW parts in color

061 | 063 | 065
062 | 064

## nominal 144 / grid 8.00

## FRONT (-Y) / new parts enter from above (+Z)

# ADD 5 PART(S)

### A-061 CYAN

BR-02x03-H096 @ 16,16,124.8

### A-062 BLACK

BR-04x02-H096 @ 32,24,124.8

### A-063 CYAN

BR-02x03-H096 @ 64,16,124.8

### A-064 BLACK

BR-04x02-H096 @ 80,24,124.8

### A-065 CYAN

BR-02x03-H096 @ 112,16,124.8

# A / STEP 17 OF 23

Placement diagram from canonical part bounds. IDs match native CAD, BOM, viewer and animation.

## PLAN VIEW / front at bottom / NEW parts in color

066 | 069 | 072
067 068 | 070 071

## nominal 144 / grid 8.00

## FRONT (-Y) / new parts enter from above (+Z)

# ADD 7 PART(S)

### A-066 CYAN

BR-02x03-H096 @ 16,16,134.4

### A-067 BLACK

BR-02x02-H096 @ 32,24,134.4

### A-068 BLACK

BR-02x02-H096 @ 48,24,134.4

### A-069 CYAN

BR-02x03-H096 @ 64,16,134.4

### A-070 BLACK

BR-02x02-H096 @ 80,24,134.4

### A-071 BLACK

BR-02x02-H096 @ 96,24,134.4

### A-072 CYAN

BR-02x03-H096 @ 112,16,134.4

# A / STEP 18 OF 23

Placement diagram from canonical part bounds. IDs match native CAD, BOM, viewer and animation.

## PLAN VIEW / front at bottom / NEW parts in color

073 | 075 | 077
074 | 076

## nominal 144 / grid 8.00

## FRONT (-Y) / new parts enter from above (+Z)

# ADD 5 PART(S)

### A-073 CYAN

BR-02x03-H096 @ 16,16,144

### A-074 BLACK

BR-04x02-H096 @ 32,24,144

### A-075 CYAN

BR-02x03-H096 @ 64,16,144

### A-076 BLACK

BR-04x02-H096 @ 80,24,144

### A-077 CYAN

BR-02x03-H096 @ 112,16,144

# A / STEP 19 OF 23

Placement diagram from canonical part bounds. IDs match native CAD, BOM, viewer and animation.

## PLAN VIEW / front at bottom / NEW parts in color

078 | 081 | 084
079 080 | 082 083

## nominal 144 / grid 8.00

## FRONT (-Y) / new parts enter from above (+Z)

# ADD 7 PART(S)

### A-078 CYAN

BR-02x03-H096 @ 16,16,153.6

### A-079 BLACK

BR-02x02-H096 @ 32,24,153.6

### A-080 BLACK

BR-02x02-H096 @ 48,24,153.6

### A-081 CYAN

BR-02x03-H096 @ 64,16,153.6

### A-082 BLACK

BR-02x02-H096 @ 80,24,153.6

### A-083 BLACK

BR-02x02-H096 @ 96,24,153.6

### A-084 CYAN

BR-02x03-H096 @ 112,16,153.6

# A / STEP 20 OF 23

Placement diagram from canonical part bounds. IDs match native CAD, BOM, viewer and animation.

## PLAN VIEW / front at bottom / NEW parts in color

085 | 086 | 087

## nominal 144 / grid 8.00

## FRONT (-Y) / new parts enter from above (+Z)

# ADD 3 PART(S)

### A-085 CYAN

BR-04x03-H096 @ 24,16,163.2

### A-086 CYAN

BR-04x03-H096 @ 56,16,163.2

### A-087 CYAN

BR-04x03-H096 @ 88,16,163.2

# A / STEP 21 OF 23

Placement diagram from canonical part bounds. IDs match native CAD, BOM, viewer and animation.

## PLAN VIEW / front at bottom / NEW parts in color

088 | 089 | 090

## nominal 144 / grid 8.00

## FRONT (-Y) / new parts enter from above (+Z)

# ADD 3 PART(S)

### A-088 CYAN

BR-02x03-H096 @ 32,16,172.8

### A-089 CYAN

BR-04x03-H096 @ 48,16,172.8

### A-090 CYAN

BR-04x03-H096 @ 80,16,172.8

# A / STEP 22 OF 23

Placement diagram from canonical part bounds. IDs match native CAD, BOM, viewer and animation.

## PLAN VIEW / front at bottom / NEW parts in color

091

## nominal 144 / grid 8.00

## FRONT (-Y) / new parts enter from above (+Z)

# ADD 1 PART(S)

### A-091 MAGENTA

BR-04x02-H032 @ 56,24,182.4

# A / STEP 23 OF 23

Placement diagram from canonical part bounds. IDs match native CAD, BOM, viewer and animation.

## PLAN VIEW / front at bottom / NEW parts in color

## nominal 144 / grid 8.00

## FRONT (-Y) / new parts enter from above (+Z)

# ADD 0 PART(S)

# BASE3-03x08-T-48de52

Three orthographic views + underside from the actual solid. Exterior heights include studs / text.

## FRONT

23.80

11.40

## SIDE

63.80

TOP / PRINT ORIENTATION | BOTTOM / REAL CAVITIES

Kind: front_base

STL: BASE3-03x08-T-48de52.stl

STL units: mm / scale 100%

Grid: 3 x 8 @ 8.00

Body height: 9.60

Stud: dia 4.80 x 1.80 high

Tip lead-in: 0.25 high / radial

Female radial c: +0.04

Outer wall: 1.46

Tube bore: 3.20 (not accessory fit)

Roof ribs: 1.20; bridge gap <=6.80

Front row reserved (no stud/socket)

NP3 dovetail side allowance: 0.20

See front-interface.svg for sections

# BASE3-03x08-T-80e081

Three orthographic views + underside from the actual solid. Exterior heights include studs / text.

## FRONT

23.80

11.40

## SIDE

63.80

TOP / PRINT ORIENTATION | BOTTOM / REAL CAVITIES

Kind: front_base

STL: BASE3-03x08-T-80e081.stl

STL units: mm / scale 100%

Grid: 3 x 8 @ 8.00

Body height: 9.60

Stud: dia 4.80 x 1.80 high

Tip lead-in: 0.25 high / radial

Female radial c: +0.04

Outer wall: 1.46

Tube bore: 3.20 (not accessory fit)

Roof ribs: 1.20; bridge gap <=6.80

Front row reserved (no stud/socket)

NP3 dovetail side allowance: 0.20

See front-interface.svg for sections

# BASE3-06x08-T-7532db

Three orthographic views + underside from the actual solid. Exterior heights include studs / text.

## FRONT

47.80

11.40

## SIDE

63.80

TOP / PRINT ORIENTATION | BOTTOM / REAL CAVITIES

Kind: front_base

STL: BASE3-06x08-T-7532db.stl

STL units: mm / scale 100%

Grid: 6 x 8 @ 8.00

Body height: 9.60

Stud: dia 4.80 x 1.80 high

Tip lead-in: 0.25 high / radial

Female radial c: +0.04

Outer wall: 1.46

Tube bore: 3.20 (not accessory fit)

Roof ribs: 1.20; bridge gap <=6.80

Front row reserved (no stud/socket)

NP3 dovetail side allowance: 0.20

See front-interface.svg for sections

# BASE3-06x08-T-7f51dc

Three orthographic views + underside from the actual solid. Exterior heights include studs / text.

## FRONT

47.80

11.40

## SIDE

63.80

TOP / PRINT ORIENTATION | BOTTOM / REAL CAVITIES

Kind: front_base

STL: BASE3-06x08-T-7f51dc.stl

STL units: mm / scale 100%

Grid: 6 x 8 @ 8.00

Body height: 9.60

Stud: dia 4.80 x 1.80 high

Tip lead-in: 0.25 high / radial

Female radial c: +0.04

Outer wall: 1.46

Tube bore: 3.20 (not accessory fit)

Roof ribs: 1.20; bridge gap <=6.80

Front row reserved (no stud/socket)

NP3 dovetail side allowance: 0.20

See front-interface.svg for sections

# BASE3-06x08-T-9cb610

Three orthographic views + underside from the actual solid. Exterior heights include studs / text.

## FRONT

47.80

11.40

## SIDE

60.40

TOP / PRINT ORIENTATION | BOTTOM / REAL CAVITIES

Kind: front_base

STL: BASE3-06x08-T-9cb610.stl

STL units: mm / scale 100%

Grid: 6 x 8 @ 8.00

Body height: 9.60

Stud: dia 4.80 x 1.80 high

Tip lead-in: 0.25 high / radial

Female radial c: +0.04

Outer wall: 1.46

Tube bore: 3.20 (not accessory fit)

Roof ribs: 1.20; bridge gap <=6.80

Front row reserved (no stud/socket)

NP3 dovetail side allowance: 0.20

See front-interface.svg for sections

# BASE3-06x08-T-b8aa05

Three orthographic views + underside from the actual solid. Exterior heights include studs / text.

## FRONT

47.80

11.40

## SIDE

63.80

TOP / PRINT ORIENTATION | BOTTOM / REAL CAVITIES

Kind: front_base

STL: BASE3-06x08-T-b8aa05.stl

STL units: mm / scale 100%

Grid: 6 x 8 @ 8.00

Body height: 9.60

Stud: dia 4.80 x 1.80 high

Tip lead-in: 0.25 high / radial

Female radial c: +0.04

Outer wall: 1.46

Tube bore: 3.20 (not accessory fit)

Roof ribs: 1.20; bridge gap <=6.80

Front row reserved (no stud/socket)

NP3 dovetail side allowance: 0.20

See front-interface.svg for sections

# BASE3-18x08-B-a4853c

Three orthographic views + underside from the actual solid. Exterior heights include studs / text.

## FRONT

143.80

11.40

## SIDE

63.80

TOP / PRINT ORIENTATION | BOTTOM / REAL CAVITIES

Kind: front_base

STL: BASE3-18x08-B-a4853c.stl

STL units: mm / scale 100%

Grid: 18 x 8 @ 8.00

Body height: 9.60

Stud: dia 4.80 x 1.80 high

Tip lead-in: 0.25 high / radial

Female radial c: +0.04

Outer wall: 1.46

Tube bore: 3.20 (not accessory fit)

Roof ribs: 1.20; bridge gap <=6.80

Front row reserved (no stud/socket)

NP3 dovetail side allowance: 0.20

See front-interface.svg for sections

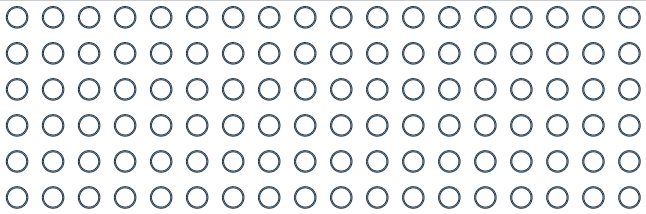
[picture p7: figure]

# BR-01x02-H096

Three orthographic views + underside from the actual solid. Exterior heights include studs / text.

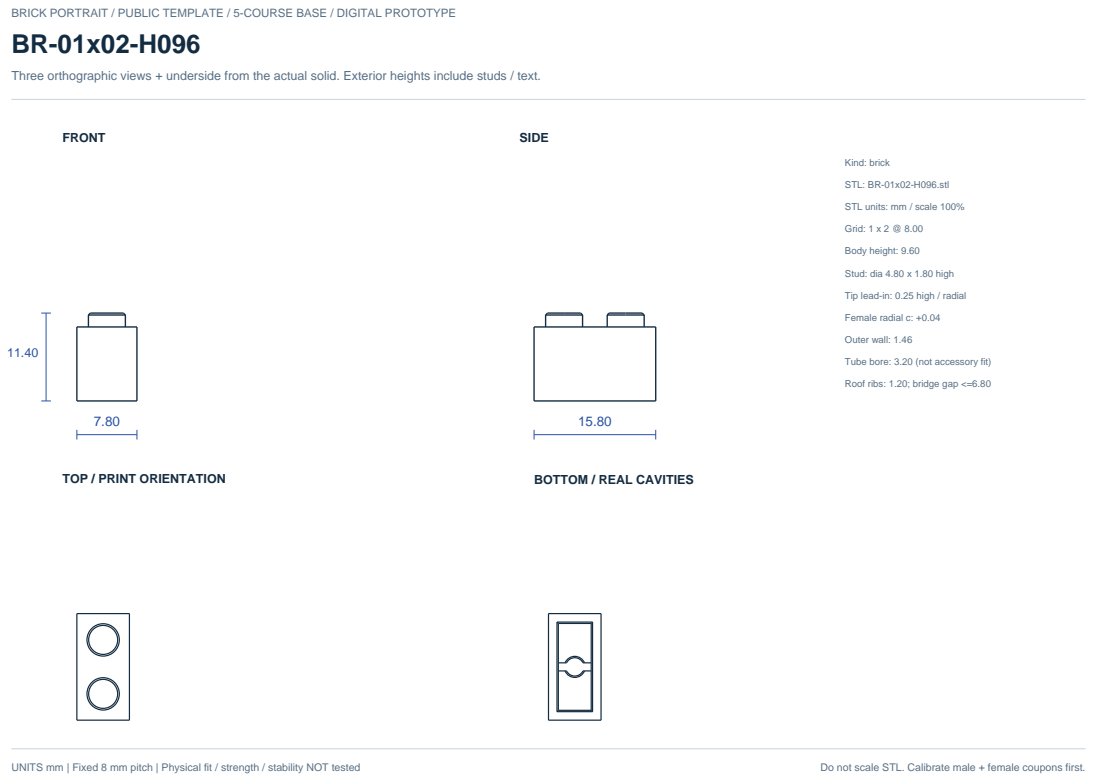
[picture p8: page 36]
FRONT; SIDE; TOP / PRINT ORIENTATION; BOTTOM / REAL CAVITIES; Kind: brick; Grid: 1 x 2 @ 8.00; Body height: 9.60; Female radial c: +0.04; Outer wall: 1.46

STL: BR-01x02-H096.stl

STL units: mm / scale 100%

Stud: dia 4.80 x 1.80 high

Tip lead-in: 0.25 high / radial

Tube bore: 3.20 (not accessory fit)

Roof ribs: 1.20; bridge gap <=6.80

# BR-02x02-H096

Three orthographic views + underside from the actual solid. Exterior heights include studs / text.

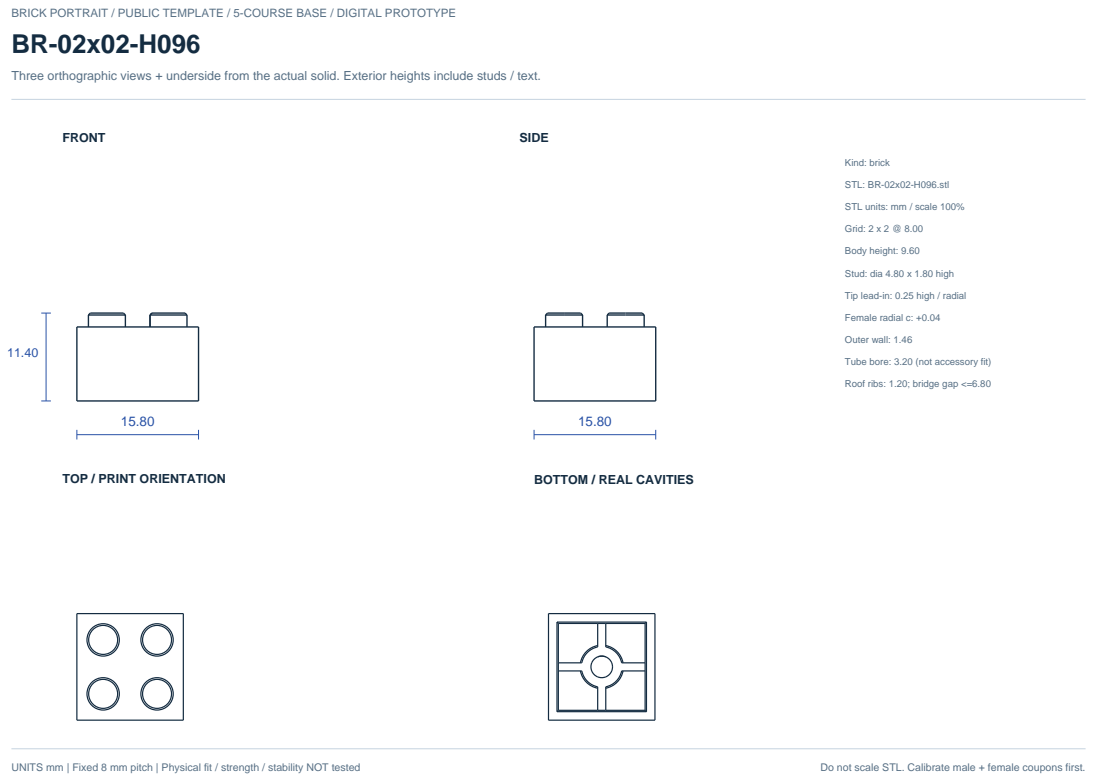
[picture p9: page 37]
FRONT; SIDE; TOP / PRINT ORIENTATION; BOTTOM / REAL CAVITIES; Kind: brick; Grid: 2 x 2 @ 8.00; Body height: 9.60; Female radial c: +0.04; Outer wall: 1.46

STL: BR-02x02-H096.stl

STL units: mm / scale 100%

Stud: dia 4.80 x 1.80 high

Tip lead-in: 0.25 high / radial

Tube bore: 3.20 (not accessory fit)

Roof ribs: 1.20; bridge gap <=6.80

# BR-02x03-H096

Three orthographic views + underside from the actual solid. Exterior heights include studs / text.

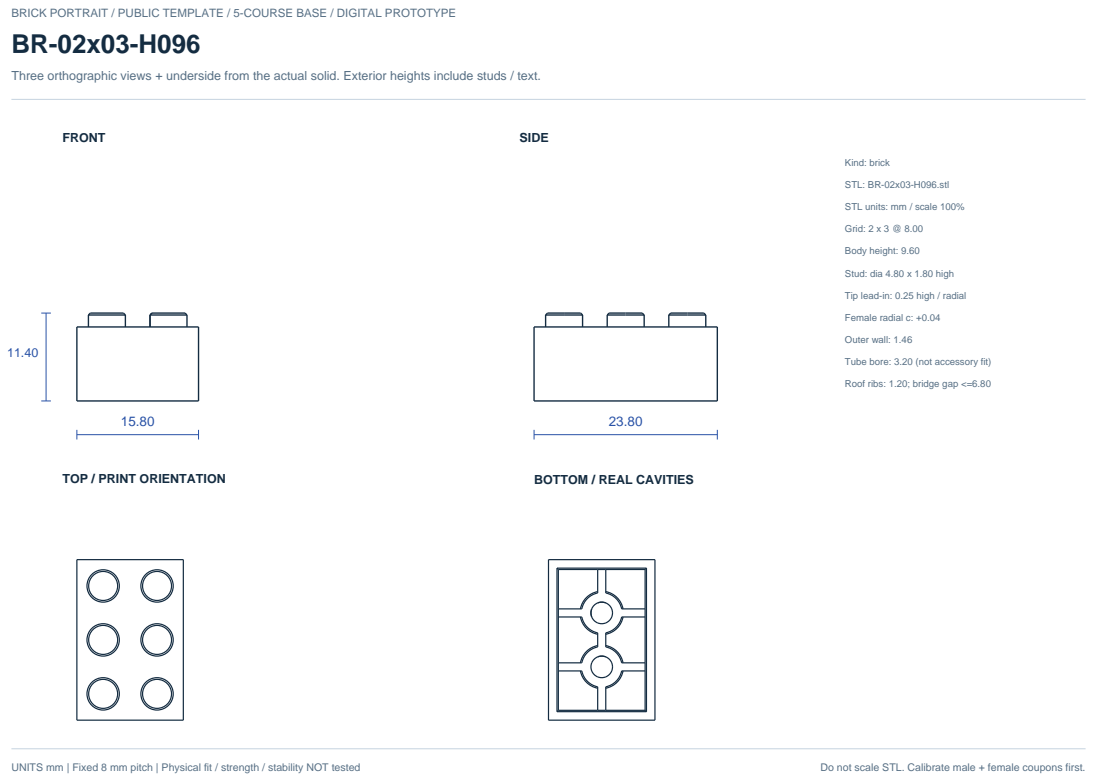
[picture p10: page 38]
FRONT; SIDE; TOP / PRINT ORIENTATION; BOTTOM / REAL CAVITIES; Kind: brick; Grid: 2 x 3 @ 8.00; Body height: 9.60; Female radial c: +0.04; Outer wall: 1.46

STL: BR-02x03-H096.stl

STL units: mm / scale 100%

Stud: dia 4.80 x 1.80 high

Tip lead-in: 0.25 high / radial

Tube bore: 3.20 (not accessory fit)

Roof ribs: 1.20; bridge gap <=6.80

# BR-03x02-H096

Three orthographic views + underside from the actual solid. Exterior heights include studs / text.

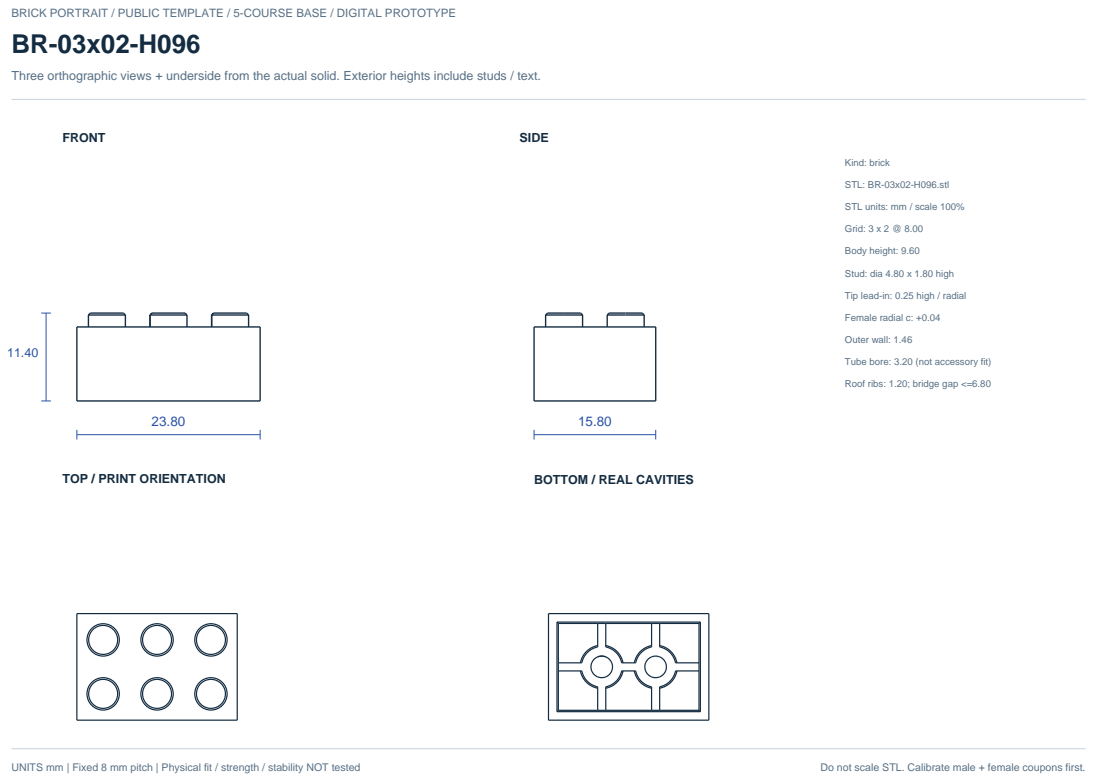
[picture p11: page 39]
FRONT; SIDE; TOP / PRINT ORIENTATION; BOTTOM / REAL CAVITIES; Kind: brick; Grid: 3 x 2 @ 8.00; Body height: 9.60; Female radial c: +0.04; Outer wall: 1.46

STL: BR-03x02-H096.stl

STL units: mm / scale 100%

Stud: dia 4.80 x 1.80 high

Tip lead-in: 0.25 high / radial

Tube bore: 3.20 (not accessory fit)

Roof ribs: 1.20; bridge gap <=6.80

# BR-04x02-H032

Three orthographic views + underside from the actual solid. Exterior heights include studs / text.

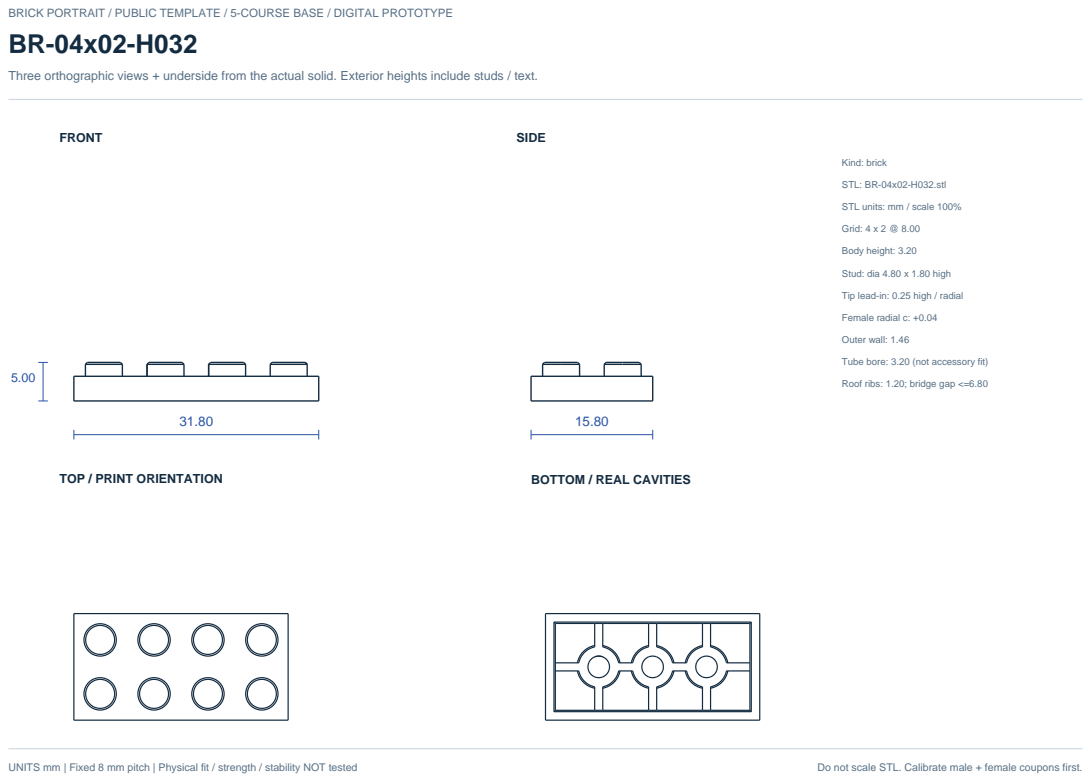
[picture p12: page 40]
FRONT; SIDE; TOP / PRINT ORIENTATION; BOTTOM / REAL CAVITIES; Kind: brick; Grid: 4 x 2 @ 8.00; Body height: 3.20; Female radial c: +0.04; Outer wall: 1.46

STL: BR-04x02-H032.stl

STL units: mm / scale 100%

Stud: dia 4.80 x 1.80 high

Tip lead-in: 0.25 high / radial

Tube bore: 3.20 (not accessory fit)

Roof ribs: 1.20; bridge gap <=6.80

# BR-04x02-H096

Three orthographic views + underside from the actual solid. Exterior heights include studs / text.

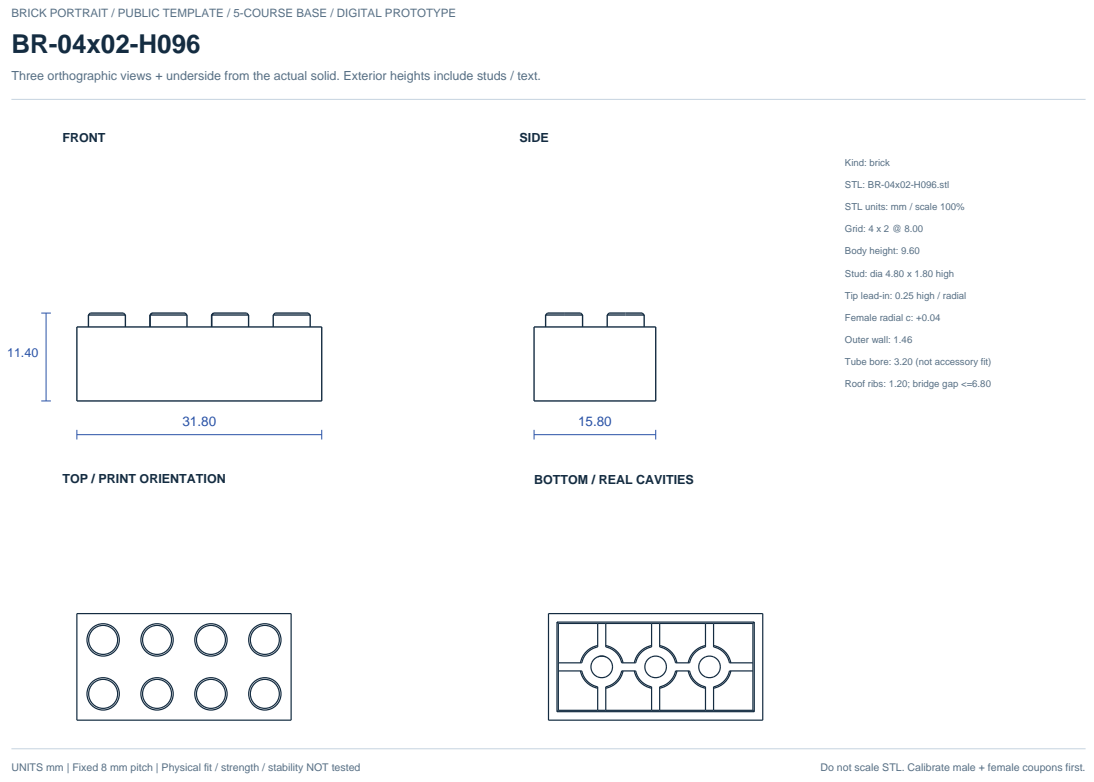
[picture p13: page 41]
FRONT; SIDE; TOP / PRINT ORIENTATION; BOTTOM / REAL CAVITIES; Kind: brick; Grid: 4 x 2 @ 8.00; Body height: 9.60; Female radial c: +0.04; Outer wall: 1.46

STL: BR-04x02-H096.stl

STL units: mm / scale 100%

Stud: dia 4.80 x 1.80 high

Tip lead-in: 0.25 high / radial

Tube bore: 3.20 (not accessory fit)

Roof ribs: 1.20; bridge gap <=6.80

# BR-04x03-H096

Three orthographic views + underside from the actual solid. Exterior heights include studs / text.

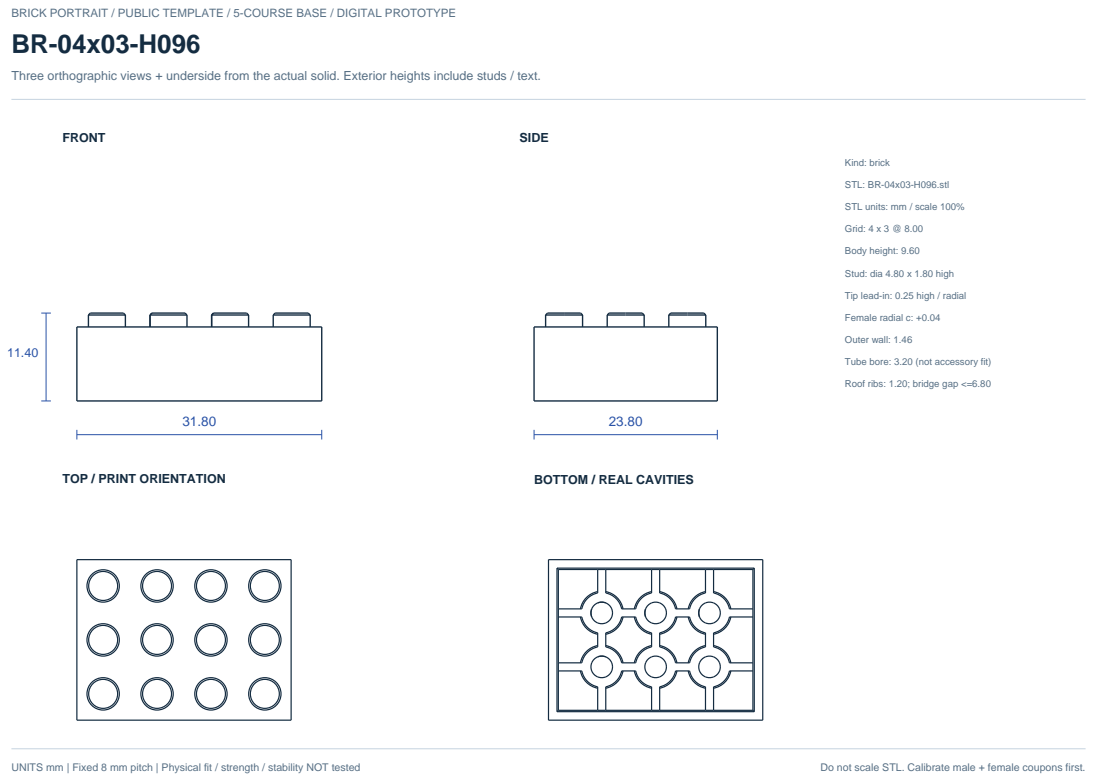
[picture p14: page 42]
FRONT; SIDE; TOP / PRINT ORIENTATION; BOTTOM / REAL CAVITIES; Kind: brick; Grid: 4 x 3 @ 8.00; Body height: 9.60; Female radial c: +0.04; Outer wall: 1.46

STL: BR-04x03-H096.stl

STL units: mm / scale 100%

Stud: dia 4.80 x 1.80 high

Tip lead-in: 0.25 high / radial

Tube bore: 3.20 (not accessory fit)

Roof ribs: 1.20; bridge gap <=6.80

# NP3-KEEPER

Three orthographic views + underside from the actual solid. Exterior heights include studs / text.

## FRONT

15.80

3.20

## SIDE

15.80

TOP / PRINT ORIENTATION | BOTTOM / REAL CAVITIES

Kind: front_keeper

STL: NP3-KEEPER.stl

STL units: mm / scale 100%

Grid: 2 x 1 @ 8.00

Body height: 3.20

Female radial c: +0.04

Outer wall: 1.46

Tube bore: 3.20 (not accessory fit)

Roof ribs: 1.20; bridge gap <=6.80

Socket row at local Y=12.00

Flat front stop covers module top

Lift 6mm, then forward >=32mm and aside

# NP3-LOGO-A

Three orthographic views + underside from the actual solid. Exterior heights include studs / text.

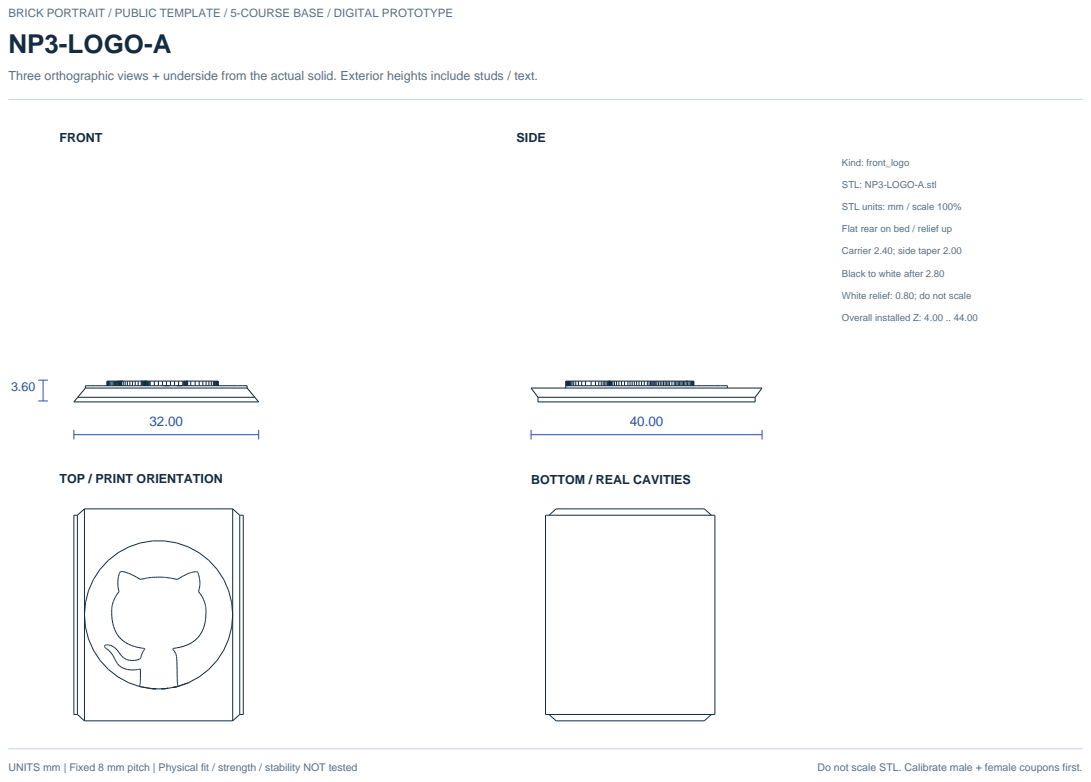
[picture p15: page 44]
FRONT; SIDE; TOP / PRINT ORIENTATION; BOTTOM / REAL CAVITIES; Kind: front_logo; Overall installed Z: 4.00 .. 44.00

STL: NP3-LOGO-A.stl

STL units: mm / scale 100%

Flat rear on bed / relief up

Carrier 2.40; side taper 2.00

Black to white after 2.80

White relief: 0.80; do not scale

# NP3-TEXT-A

Three orthographic views + underside from the actual solid. Exterior heights include studs / text.

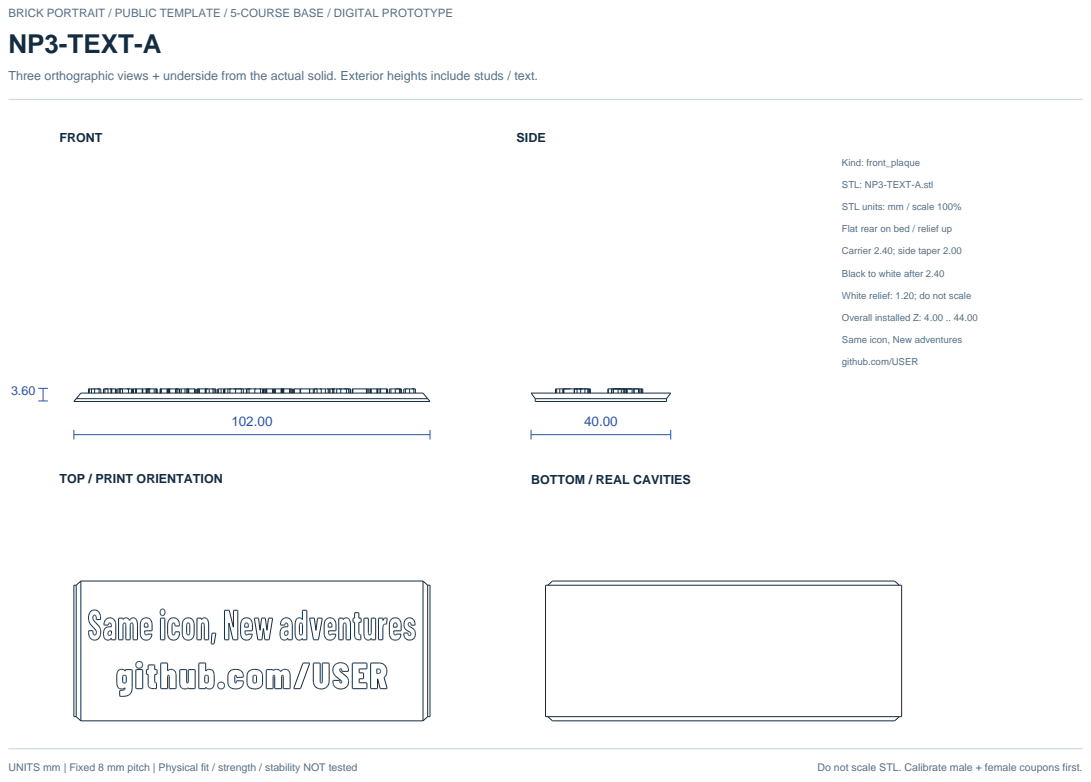
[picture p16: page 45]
FRONT; SIDE; TOP / PRINT ORIENTATION; BOTTOM / REAL CAVITIES; Kind: front_plaque; Overall installed Z: 4.00 .. 44.00

STL: NP3-TEXT-A.stl

STL units: mm / scale 100%

Flat rear on bed / relief up

Carrier 2.40; side taper 2.00

Black to white after 2.40

White relief: 1.20; do not scale

Same icon, New adventures

github.com/USER

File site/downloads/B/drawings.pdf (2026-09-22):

### BRICK PORTRAIT / PUBLIC TEMPLATE / 5-COURSE BASE / DIGITAL PROTOTYPE

# B / DESK CLASSIC

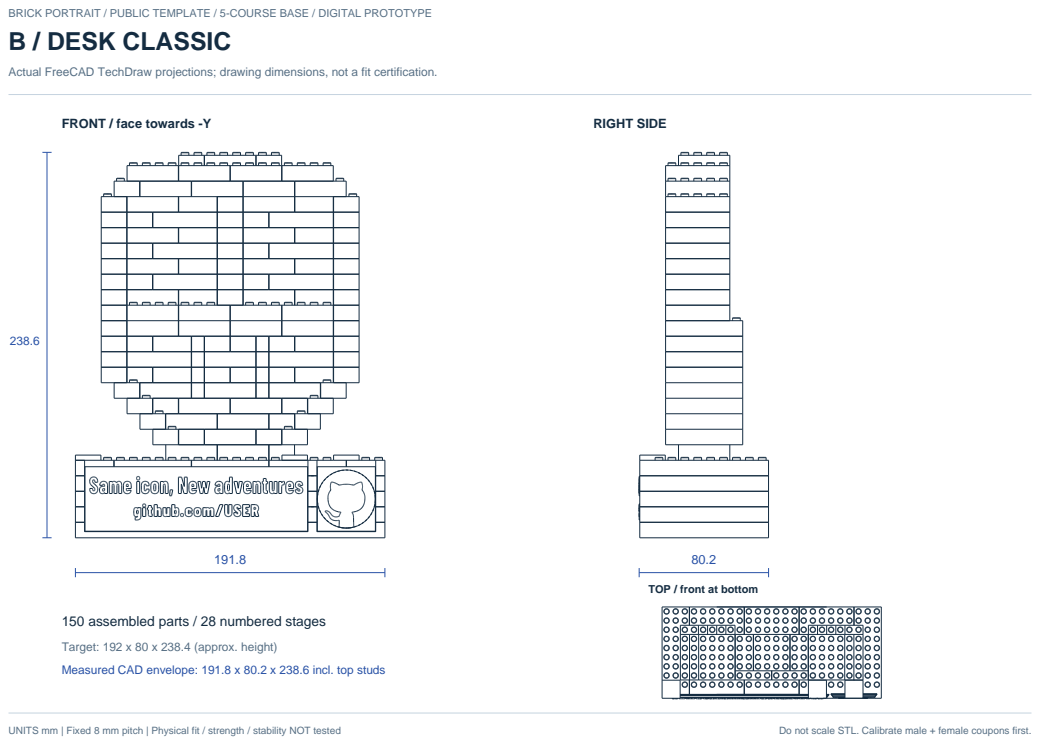
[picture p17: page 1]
RIGHT SIDE; UNITS mm | Fixed 8 mm pitch | Physical fit / strength / stability NOT tested; Do not scale STL. Calibrate male + female coupons first.

Actual FreeCAD TechDraw projections; drawing dimensions, not a fit certification.

FRONT / face towards -Y

TOP / front at bottom

150 assembled parts / 28 numbered stages

Target: 192 x 80 x 238.4 (approx. height)
Measured CAD envelope: 191.8 x 80.2 x 238.6 incl. top studs

# B / EXPLODED ASSEMBLY

CAD-derived exploded view; displacement is illustrative, dimensions are not changed.

# EXPLODED FRONT

Actual solids, displaced only for this view.

Exact WebGL 100% offsets, centered up/down.

Do not measure assembly height here.

Use overview for final outside dimensions.

Insert parts downward in numbered order.

Front modules release before spreading.

Stud engagement != verified physical clutch.

## TEXT / flat printing view

## RIGHT LOGO / supported relief

# INTERFACE / SECTION & CLEARANCE

Project design candidates, NOT a proprietary tolerance standard. Geometry from FreeCAD planar sections.

## SECTION: Y = 4.00 / TWO 2x2 BRICKS


## 8.00 nominal pitch x 2

## JOINT SECTION: Z = 10.50

### Actual wall, tube, rib + mating stud outlines


### Blue: lower brick / black: upper socket

### Reference stud dia 4.80; candidate height 1.80

### Radial clearance c=+0.04 (default; untested)

### Inside wall offset 1.56 / wall thickness 1.46

### Tube OD 6.433708 / ID 3.20; grid rib 1.20

### Tip lead-in 0.25 / female lead-in 0.20 x 0.30

### Roof 1.60; thin plate roof 1.00

### Thin plate / keeper: nominal headroom 0.40

No forced fit. Tune male and female separately.

# NP3 / BASE-FRONT CAPTURE & REMOVAL

Actual BREP sections; precise dimensions apply to the nominal model, not guaranteed printed fit.

## B / HORIZONTAL SECTION Z=24 / FRONT 8mm BAND

## B message: 142.00

## B logo carrier: 40.00

## VERTICAL SECTION X=40

48.00

## Blue: installed modules; black: actual receiver / keepers

## Carrier thickness2.40 / rear flat0.80 / edge relief1.20

## Rear width -> front width: 2.00 inset on each X side

## Default side clearance0.20; coupon candidates0.15/0.20/0.25

## Text frontY=-0.30 / logo frontY=0.10; +0.40mm depth

## Both front modules fit in Z=4.00..44.00, inside48mm base

## 3 separate up-stops: text2 / logo1; stud-grid mounting

## Remove: up-stops up6, forward>=32; module up45

## Thread / glue / magnet / purchased fastener not required

## Physical clutch, retention, flatness and stability NOT tested

# B / COLOR BOM / 1

One STL geometry may be printed in several colors. Use the quantities for this model only.

PART ID | COLOR | QTY | PRINT FILE
BASE3-03x10-T-aa77a9 | black | 2 | parts/BASE3-03x10-T-aa77a9.stl
BASE3-03x10-T-d79875 | black | 2 | parts/BASE3-03x10-T-d79875.stl
BASE3-06x10-T-3f87ac | black | 2 | parts/BASE3-06x10-T-3f87ac.stl
BASE3-06x10-T-6159e6 | black | 2 | parts/BASE3-06x10-T-6159e6.stl
BASE3-06x10-T-6e100f | black | 2 | parts/BASE3-06x10-T-6e100f.stl
BASE3-06x10-T-838259 | black | 6 | parts/BASE3-06x10-T-838259.stl
BASE3-06x10-T-e1945a | black | 2 | parts/BASE3-06x10-T-e1945a.stl
BASE3-24x10-B-562406 | black | 1 | parts/BASE3-24x10-B-562406.stl
BR-01x04-H096 | green | 8 | parts/BR-01x04-H096.stl
BR-02x04-H064 | magenta | 2 | parts/BR-02x04-H064.stl
BR-02x04-H096 | black | 19 | parts/BR-02x04-H096.stl
BR-02x04-H096 | magenta | 1 | parts/BR-02x04-H096.stl
BR-02x05-H096 | cyan | 24 | parts/BR-02x05-H096.stl
BR-02x06-H096 | magenta | 16 | parts/BR-02x06-H096.stl
BR-03x04-H096 | black | 12 | parts/BR-03x04-H096.stl
BR-04x04-H064 | magenta | 1 | parts/BR-04x04-H064.stl
BR-04x04-H096 | black | 21 | parts/BR-04x04-H096.stl
BR-04x04-H096 | magenta | 2 | parts/BR-04x04-H096.stl
BR-04x05-H096 | cyan | 12 | parts/BR-04x05-H096.stl
BR-05x04-H096 | black | 8 | parts/BR-05x04-H096.stl
NP3-KEEPER | black | 3 | parts/NP3-KEEPER.stl
NP3-LOGO-B | black | 1 | parts/NP3-LOGO-B.stl
NP3-TEXT-B | black | 1 | parts/NP3-TEXT-B.stl

TEXT: black -> white at 2.4mm; LOGO: black -> white at 2.8mm. Separate plates.

Assembly: 150 pieces, including 2 front modules + 3 keepers. Coupons separate.

# B / STEP 01 OF 28

Placement diagram from canonical part bounds. IDs match native CAD, BOM, viewer and animation.

## PLAN VIEW / front at bottom / NEW parts in color

001

## nominal 192 / grid 8.00

## FRONT (-Y) / new parts enter from above (+Z)

# ADD 1 PART(S)

### B-001 BLACK

BASE3-24x10-B-562406 @ 0,0,0

# B / STEP 02 OF 28

Placement diagram from canonical part bounds. IDs match native CAD, BOM, viewer and animation.

## PLAN VIEW / front at bottom / NEW parts in color

002 | 003 | 004 | 005

## nominal 192 / grid 8.00

## FRONT (-Y) / new parts enter from above (+Z)

# ADD 4 PART(S)

### B-002 BLACK

BASE3-06x10-T-e1945a @ 0,0,9.6

### B-003 BLACK

BASE3-06x10-T-838259 @ 48,0,9.6

### B-004 BLACK

BASE3-06x10-T-3f87ac @ 96,0,9.6

### B-005 BLACK

BASE3-06x10-T-6e100f @ 144,0,9.6

# B / STEP 03 OF 28

Placement diagram from canonical part bounds. IDs match native CAD, BOM, viewer and animation.

## PLAN VIEW / front at bottom / NEW parts in color

006 | 007 | 008 | 009 | 010

## nominal 192 / grid 8.00

## FRONT (-Y) / new parts enter from above (+Z)

# ADD 5 PART(S)

### B-006 BLACK

BASE3-03x10-T-aa77a9 @ 0,0,19.2

### B-007 BLACK

BASE3-06x10-T-838259 @ 24,0,19.2

### B-008 BLACK

BASE3-06x10-T-838259 @ 72,0,19.2

### B-009 BLACK

BASE3-06x10-T-6159e6 @ 120,0,19.2

### B-010 BLACK

BASE3-03x10-T-d79875 @ 168,0,19.2

# B / STEP 04 OF 28

Placement diagram from canonical part bounds. IDs match native CAD, BOM, viewer and animation.

## PLAN VIEW / front at bottom / NEW parts in color

011 | 012 | 013 | 014

## nominal 192 / grid 8.00

## FRONT (-Y) / new parts enter from above (+Z)

# ADD 4 PART(S)

### B-011 BLACK

BASE3-06x10-T-e1945a @ 0,0,28.8

### B-012 BLACK

BASE3-06x10-T-838259 @ 48,0,28.8

### B-013 BLACK

BASE3-06x10-T-3f87ac @ 96,0,28.8

### B-014 BLACK

BASE3-06x10-T-6e100f @ 144,0,28.8

# B / STEP 05 OF 28

Placement diagram from canonical part bounds. IDs match native CAD, BOM, viewer and animation.

## PLAN VIEW / front at bottom / NEW parts in color

015 | 016 | 017 | 018 | 019

## nominal 192 / grid 8.00

## FRONT (-Y) / new parts enter from above (+Z)

# ADD 5 PART(S)

### B-015 BLACK

BASE3-03x10-T-aa77a9 @ 0,0,38.4

### B-016 BLACK

BASE3-06x10-T-838259 @ 24,0,38.4

### B-017 BLACK

BASE3-06x10-T-838259 @ 72,0,38.4

### B-018 BLACK

BASE3-06x10-T-6159e6 @ 120,0,38.4

### B-019 BLACK

BASE3-03x10-T-d79875 @ 168,0,38.4

# B / STEP 06 OF 28

Placement diagram from canonical part bounds. IDs match native CAD, BOM, viewer and animation.

## PLAN VIEW / front at bottom / NEW parts in color

020 021

## nominal 192 / grid 8.00

## FRONT (-Y) / new parts enter from above (+Z)

# ADD 2 PART(S)

### B-020 BLACK

NP3-TEXT-B @ 4,3.3,4

### B-021 BLACK

NP3-LOGO-B @ 148,3.7,4

# B / STEP 07 OF 28

Placement diagram from canonical part bounds. IDs match native CAD, BOM, viewer and animation.

## PLAN VIEW / front at bottom / NEW parts in color

022 | 023 | 024

## nominal 192 / grid 8.00

## FRONT (-Y) / new parts enter from above (+Z)

# ADD 3 PART(S)

### B-022 BLACK

NP3-KEEPER @ 0,0,48

### B-023 BLACK

NP3-KEEPER @ 128,0,48

### B-024 BLACK

NP3-KEEPER @ 160,0,48

# B / STEP 08 OF 28

Placement diagram from canonical part bounds. IDs match native CAD, BOM, viewer and animation.

## PLAN VIEW / front at bottom / NEW parts in color

025 | 026 | 027

## nominal 192 / grid 8.00

## FRONT (-Y) / new parts enter from above (+Z)

# ADD 3 PART(S)

### B-025 MAGENTA

BR-04x04-H096 @ 56,24,48

### B-026 MAGENTA

BR-04x04-H096 @ 88,24,48

### B-027 MAGENTA

BR-02x04-H096 @ 120,24,48

# B / STEP 09 OF 28

Placement diagram from canonical part bounds. IDs match native CAD, BOM, viewer and animation.

## PLAN VIEW / front at bottom / NEW parts in color

028 | 029 | 030 | 031 | 032

## nominal 192 / grid 8.00

## FRONT (-Y) / new parts enter from above (+Z)

# ADD 5 PART(S)

### B-028 MAGENTA

BR-02x06-H096 @ 48,16,57.6

### B-029 BLACK

BR-02x04-H096 @ 64,24,57.6

### B-030 BLACK

BR-04x04-H096 @ 80,24,57.6

### B-031 BLACK

BR-02x04-H096 @ 112,24,57.6

### B-032 MAGENTA

BR-02x06-H096 @ 128,16,57.6

# B / STEP 10 OF 28

Placement diagram from canonical part bounds. IDs match native CAD, BOM, viewer and animation.

## PLAN VIEW / front at bottom / NEW parts in color

033 | 034 | 035 | 036 | 037

## nominal 192 / grid 8.00

## FRONT (-Y) / new parts enter from above (+Z)

# ADD 5 PART(S)

### B-033 MAGENTA

BR-02x06-H096 @ 40,16,67.2

### B-034 BLACK

BR-04x04-H096 @ 56,24,67.2

### B-035 BLACK

BR-04x04-H096 @ 88,24,67.2

### B-036 BLACK

BR-02x04-H096 @ 120,24,67.2

### B-037 MAGENTA

BR-02x06-H096 @ 136,16,67.2

# B / STEP 11 OF 28

Placement diagram from canonical part bounds. IDs match native CAD, BOM, viewer and animation.

## PLAN VIEW / front at bottom / NEW parts in color

038 | 039 | 040 | 041 | 042 | 043

## nominal 192 / grid 8.00

## FRONT (-Y) / new parts enter from above (+Z)

# ADD 6 PART(S)

### B-038 MAGENTA

BR-02x06-H096 @ 32,16,76.8

### B-039 BLACK

BR-02x04-H096 @ 48,24,76.8

### B-040 BLACK

BR-04x04-H096 @ 64,24,76.8

### B-041 BLACK

BR-04x04-H096 @ 96,24,76.8

### B-042 BLACK

BR-02x04-H096 @ 128,24,76.8

### B-043 MAGENTA

BR-02x06-H096 @ 144,16,76.8

# B / STEP 12 OF 28

Placement diagram from canonical part bounds. IDs match native CAD, BOM, viewer and animation.

## PLAN VIEW / front at bottom / NEW parts in color

044 | 045 | 046 | 047 | 048 | 049 | 050

## nominal 192 / grid 8.00

## FRONT (-Y) / new parts enter from above (+Z)

# ADD 7 PART(S)

### B-044 MAGENTA

BR-02x06-H096 @ 24,16,86.4

### B-045 BLACK

BR-04x04-H096 @ 40,24,86.4

### B-046 GREEN

BR-01x04-H096 @ 72,24,86.4

### B-047 BLACK

BR-04x04-H096 @ 80,24,86.4

### B-048 GREEN

BR-01x04-H096 @ 112,24,86.4

### B-049 BLACK

BR-04x04-H096 @ 120,24,86.4

### B-050 MAGENTA

BR-02x06-H096 @ 152,16,86.4

# B / STEP 13 OF 28

Placement diagram from canonical part bounds. IDs match native CAD, BOM, viewer and animation.

## PLAN VIEW / front at bottom / NEW parts in color

051 | 052 | 053 | 054 | 055 | 056 | 057 | 058 | 059 | 060

## nominal 192 / grid 8.00

## FRONT (-Y) / new parts enter from above (+Z)

# ADD 10 PART(S)

### B-051 MAGENTA

BR-02x06-H096 @ 16,16,96

### B-052 BLACK

BR-02x04-H096 @ 32,24,96

### B-053 BLACK

BR-03x04-H096 @ 48,24,96

### B-054 GREEN

BR-01x04-H096 @ 72,24,96

### B-055 BLACK

BR-02x04-H096 @ 80,24,96

### B-056 BLACK

BR-02x04-H096 @ 96,24,96

### B-057 GREEN

BR-01x04-H096 @ 112,24,96

### B-058 BLACK

BR-02x04-H096 @ 120,24,96

### B-059 BLACK

BR-03x04-H096 @ 136,24,96

### B-060 MAGENTA

BR-02x06-H096 @ 160,16,96

# B / STEP 14 OF 28

Placement diagram from canonical part bounds. IDs match native CAD, BOM, viewer and animation.

## PLAN VIEW / front at bottom / NEW parts in color

061 | 062 | 063 | 064 | 065 | 066 | 067

## nominal 192 / grid 8.00

## FRONT (-Y) / new parts enter from above (+Z)

# ADD 7 PART(S)

### B-061 MAGENTA

BR-02x06-H096 @ 16,16,105.6

### B-062 BLACK

BR-05x04-H096 @ 32,24,105.6

### B-063 GREEN

BR-01x04-H096 @ 72,24,105.6

### B-064 BLACK

BR-04x04-H096 @ 80,24,105.6

### B-065 GREEN

BR-01x04-H096 @ 112,24,105.6

### B-066 BLACK

BR-05x04-H096 @ 120,24,105.6

### B-067 MAGENTA

BR-02x06-H096 @ 160,16,105.6

# B / STEP 15 OF 28

Placement diagram from canonical part bounds. IDs match native CAD, BOM, viewer and animation.

## PLAN VIEW / front at bottom / NEW parts in color

068 | 069 | 070 | 071 | 072 | 073 | 074 | 075 | 076 | 077

## nominal 192 / grid 8.00

## FRONT (-Y) / new parts enter from above (+Z)

# ADD 10 PART(S)

### B-068 MAGENTA

BR-02x06-H096 @ 16,16,115.2

### B-069 BLACK

BR-02x04-H096 @ 32,24,115.2

### B-070 BLACK

BR-03x04-H096 @ 48,24,115.2

### B-071 GREEN

BR-01x04-H096 @ 72,24,115.2

### B-072 BLACK

BR-02x04-H096 @ 80,24,115.2

### B-073 BLACK

BR-02x04-H096 @ 96,24,115.2

### B-074 GREEN

BR-01x04-H096 @ 112,24,115.2

### B-075 BLACK

BR-02x04-H096 @ 120,24,115.2

### B-076 BLACK

BR-03x04-H096 @ 136,24,115.2

### B-077 MAGENTA

BR-02x06-H096 @ 160,16,115.2

# B / STEP 16 OF 28

Placement diagram from canonical part bounds. IDs match native CAD, BOM, viewer and animation.

## PLAN VIEW / front at bottom / NEW parts in color

078 | 079 | 080 | 081 | 082 | 083

## nominal 192 / grid 8.00

## FRONT (-Y) / new parts enter from above (+Z)

# ADD 6 PART(S)

### B-078 MAGENTA

BR-02x06-H096 @ 16,16,124.8

### B-079 BLACK

BR-04x04-H096 @ 32,24,124.8

### B-080 BLACK

BR-04x04-H096 @ 64,24,124.8

### B-081 BLACK

BR-04x04-H096 @ 96,24,124.8

### B-082 BLACK

BR-04x04-H096 @ 128,24,124.8

### B-083 MAGENTA

BR-02x06-H096 @ 160,16,124.8

# B / STEP 17 OF 28

Placement diagram from canonical part bounds. IDs match native CAD, BOM, viewer and animation.

## PLAN VIEW / front at bottom / NEW parts in color

084 | 085 | 086 | 087 | 088 | 089

## nominal 192 / grid 8.00

## FRONT (-Y) / new parts enter from above (+Z)

# ADD 6 PART(S)

### B-084 CYAN

BR-02x05-H096 @ 16,16,134.4

### B-085 CYAN

BR-04x05-H096 @ 32,16,134.4

### B-086 CYAN

BR-04x05-H096 @ 64,16,134.4

### B-087 CYAN

BR-04x05-H096 @ 96,16,134.4

### B-088 CYAN

BR-04x05-H096 @ 128,16,134.4

### B-089 CYAN

BR-02x05-H096 @ 160,16,134.4

# B / STEP 18 OF 28

Placement diagram from canonical part bounds. IDs match native CAD, BOM, viewer and animation.

## PLAN VIEW / front at bottom / NEW parts in color

090 | 093 | 096
091 092 | 094 095

## nominal 192 / grid 8.00

## FRONT (-Y) / new parts enter from above (+Z)

# ADD 7 PART(S)

### B-090 CYAN

BR-02x05-H096 @ 16,16,144

### B-091 BLACK

BR-04x04-H096 @ 32,24,144

### B-092 BLACK

BR-03x04-H096 @ 64,24,144

### B-093 CYAN

BR-02x05-H096 @ 88,16,144

### B-094 BLACK

BR-04x04-H096 @ 104,24,144

### B-095 BLACK

BR-03x04-H096 @ 136,24,144

### B-096 CYAN

BR-02x05-H096 @ 160,16,144

# B / STEP 19 OF 28

Placement diagram from canonical part bounds. IDs match native CAD, BOM, viewer and animation.

## PLAN VIEW / front at bottom / NEW parts in color

097 | 100 | 103
098 099 | 101 102

## nominal 192 / grid 8.00

## FRONT (-Y) / new parts enter from above (+Z)

# ADD 7 PART(S)

### B-097 CYAN

BR-02x05-H096 @ 16,16,153.6

### B-098 BLACK

BR-02x04-H096 @ 32,24,153.6

### B-099 BLACK

BR-05x04-H096 @ 48,24,153.6

### B-100 CYAN

BR-02x05-H096 @ 88,16,153.6

### B-101 BLACK

BR-02x04-H096 @ 104,24,153.6

### B-102 BLACK

BR-05x04-H096 @ 120,24,153.6

### B-103 CYAN

BR-02x05-H096 @ 160,16,153.6

# B / STEP 20 OF 28

Placement diagram from canonical part bounds. IDs match native CAD, BOM, viewer and animation.

## PLAN VIEW / front at bottom / NEW parts in color

104 | 107 | 110
105 106 | 108 109

## nominal 192 / grid 8.00

## FRONT (-Y) / new parts enter from above (+Z)

# ADD 7 PART(S)

### B-104 CYAN

BR-02x05-H096 @ 16,16,163.2

### B-105 BLACK

BR-04x04-H096 @ 32,24,163.2

### B-106 BLACK

BR-03x04-H096 @ 64,24,163.2

### B-107 CYAN

BR-02x05-H096 @ 88,16,163.2

### B-108 BLACK

BR-04x04-H096 @ 104,24,163.2

### B-109 BLACK

BR-03x04-H096 @ 136,24,163.2

### B-110 CYAN

BR-02x05-H096 @ 160,16,163.2

# B / STEP 21 OF 28

Placement diagram from canonical part bounds. IDs match native CAD, BOM, viewer and animation.

## PLAN VIEW / front at bottom / NEW parts in color

111 | 114 | 117
112 113 | 115 116

## nominal 192 / grid 8.00

## FRONT (-Y) / new parts enter from above (+Z)

# ADD 7 PART(S)

### B-111 CYAN

BR-02x05-H096 @ 16,16,172.8

### B-112 BLACK

BR-02x04-H096 @ 32,24,172.8

### B-113 BLACK

BR-05x04-H096 @ 48,24,172.8

### B-114 CYAN

BR-02x05-H096 @ 88,16,172.8

### B-115 BLACK

BR-02x04-H096 @ 104,24,172.8

### B-116 BLACK

BR-05x04-H096 @ 120,24,172.8

### B-117 CYAN

BR-02x05-H096 @ 160,16,172.8

# B / STEP 22 OF 28

Placement diagram from canonical part bounds. IDs match native CAD, BOM, viewer and animation.

## PLAN VIEW / front at bottom / NEW parts in color

118 | 121 | 124
119 120 | 122 123

## nominal 192 / grid 8.00

## FRONT (-Y) / new parts enter from above (+Z)

# ADD 7 PART(S)

### B-118 CYAN

BR-02x05-H096 @ 16,16,182.4

### B-119 BLACK

BR-04x04-H096 @ 32,24,182.4

### B-120 BLACK

BR-03x04-H096 @ 64,24,182.4

### B-121 CYAN

BR-02x05-H096 @ 88,16,182.4

### B-122 BLACK

BR-04x04-H096 @ 104,24,182.4

### B-123 BLACK

BR-03x04-H096 @ 136,24,182.4

### B-124 CYAN

BR-02x05-H096 @ 160,16,182.4

# B / STEP 23 OF 28

Placement diagram from canonical part bounds. IDs match native CAD, BOM, viewer and animation.

## PLAN VIEW / front at bottom / NEW parts in color

125 | 128 | 131
126 127 | 129 130

## nominal 192 / grid 8.00

## FRONT (-Y) / new parts enter from above (+Z)

# ADD 7 PART(S)

### B-125 CYAN

BR-02x05-H096 @ 16,16,192

### B-126 BLACK

BR-02x04-H096 @ 32,24,192

### B-127 BLACK

BR-05x04-H096 @ 48,24,192

### B-128 CYAN

BR-02x05-H096 @ 88,16,192

### B-129 BLACK

BR-02x04-H096 @ 104,24,192

### B-130 BLACK

BR-05x04-H096 @ 120,24,192

### B-131 CYAN

BR-02x05-H096 @ 160,16,192

# B / STEP 24 OF 28

Placement diagram from canonical part bounds. IDs match native CAD, BOM, viewer and animation.

## PLAN VIEW / front at bottom / NEW parts in color

132 | 135 | 138
133 134 | 136 137

## nominal 192 / grid 8.00

## FRONT (-Y) / new parts enter from above (+Z)

# ADD 7 PART(S)

### B-132 CYAN

BR-02x05-H096 @ 16,16,201.6

### B-133 BLACK

BR-04x04-H096 @ 32,24,201.6

### B-134 BLACK

BR-03x04-H096 @ 64,24,201.6

### B-135 CYAN

BR-02x05-H096 @ 88,16,201.6

### B-136 BLACK

BR-04x04-H096 @ 104,24,201.6

### B-137 BLACK

BR-03x04-H096 @ 136,24,201.6

### B-138 CYAN

BR-02x05-H096 @ 160,16,201.6

# B / STEP 25 OF 28

Placement diagram from canonical part bounds. IDs match native CAD, BOM, viewer and animation.

## PLAN VIEW / front at bottom / NEW parts in color

139 | 140 | 141 | 142 | 143

## nominal 192 / grid 8.00

## FRONT (-Y) / new parts enter from above (+Z)

# ADD 5 PART(S)

### B-139 CYAN

BR-02x05-H096 @ 24,16,211.2

### B-140 CYAN

BR-04x05-H096 @ 40,16,211.2

### B-141 CYAN

BR-04x05-H096 @ 72,16,211.2

### B-142 CYAN

BR-04x05-H096 @ 104,16,211.2

### B-143 CYAN

BR-04x05-H096 @ 136,16,211.2

# B / STEP 26 OF 28

Placement diagram from canonical part bounds. IDs match native CAD, BOM, viewer and animation.

## PLAN VIEW / front at bottom / NEW parts in color

144 | 145 | 146 | 147

## nominal 192 / grid 8.00

## FRONT (-Y) / new parts enter from above (+Z)

# ADD 4 PART(S)

### B-144 CYAN

BR-04x05-H096 @ 32,16,220.8

### B-145 CYAN

BR-04x05-H096 @ 64,16,220.8

### B-146 CYAN

BR-04x05-H096 @ 96,16,220.8

### B-147 CYAN

BR-04x05-H096 @ 128,16,220.8

# B / STEP 27 OF 28

Placement diagram from canonical part bounds. IDs match native CAD, BOM, viewer and animation.

## PLAN VIEW / front at bottom / NEW parts in color

148 | 149 | 150

## nominal 192 / grid 8.00

## FRONT (-Y) / new parts enter from above (+Z)

# ADD 3 PART(S)

### B-148 MAGENTA

BR-02x04-H064 @ 64,24,230.4

### B-149 MAGENTA

BR-04x04-H064 @ 80,24,230.4

### B-150 MAGENTA

BR-02x04-H064 @ 112,24,230.4

# B / STEP 28 OF 28

Placement diagram from canonical part bounds. IDs match native CAD, BOM, viewer and animation.

## PLAN VIEW / front at bottom / NEW parts in color

## nominal 192 / grid 8.00

## FRONT (-Y) / new parts enter from above (+Z)

# ADD 0 PART(S)

# BASE3-03x10-T-aa77a9

Three orthographic views + underside from the actual solid. Exterior heights include studs / text.

## FRONT

23.80

11.40

## SIDE

79.80

TOP / PRINT ORIENTATION | BOTTOM / REAL CAVITIES

Kind: front_base

STL: BASE3-03x10-T-aa77a9.stl

STL units: mm / scale 100%

Grid: 3 x 10 @ 8.00

Body height: 9.60

Stud: dia 4.80 x 1.80 high

Tip lead-in: 0.25 high / radial

Female radial c: +0.04

Outer wall: 1.46

Tube bore: 3.20 (not accessory fit)

Roof ribs: 1.20; bridge gap <=6.80

Front row reserved (no stud/socket)

NP3 dovetail side allowance: 0.20

See front-interface.svg for sections

# BASE3-03x10-T-d79875

Three orthographic views + underside from the actual solid. Exterior heights include studs / text.

## FRONT

23.80

11.40

## SIDE

79.80

TOP / PRINT ORIENTATION | BOTTOM / REAL CAVITIES

Kind: front_base

STL: BASE3-03x10-T-d79875.stl

STL units: mm / scale 100%

Grid: 3 x 10 @ 8.00

Body height: 9.60

Stud: dia 4.80 x 1.80 high

Tip lead-in: 0.25 high / radial

Female radial c: +0.04

Outer wall: 1.46

Tube bore: 3.20 (not accessory fit)

Roof ribs: 1.20; bridge gap <=6.80

Front row reserved (no stud/socket)

NP3 dovetail side allowance: 0.20

See front-interface.svg for sections

# BASE3-06x10-T-3f87ac

Three orthographic views + underside from the actual solid. Exterior heights include studs / text.

## FRONT

47.80

11.40

## SIDE

76.40

TOP / PRINT ORIENTATION | BOTTOM / REAL CAVITIES

Kind: front_base

STL: BASE3-06x10-T-3f87ac.stl

STL units: mm / scale 100%

Grid: 6 x 10 @ 8.00

Body height: 9.60

Stud: dia 4.80 x 1.80 high

Tip lead-in: 0.25 high / radial

Female radial c: +0.04

Outer wall: 1.46

Tube bore: 3.20 (not accessory fit)

Roof ribs: 1.20; bridge gap <=6.80

Front row reserved (no stud/socket)

NP3 dovetail side allowance: 0.20

See front-interface.svg for sections

# BASE3-06x10-T-6159e6

Three orthographic views + underside from the actual solid. Exterior heights include studs / text.

## FRONT

47.80

11.40

## SIDE

79.80

TOP / PRINT ORIENTATION | BOTTOM / REAL CAVITIES

Kind: front_base

STL: BASE3-06x10-T-6159e6.stl

STL units: mm / scale 100%

Grid: 6 x 10 @ 8.00

Body height: 9.60

Stud: dia 4.80 x 1.80 high

Tip lead-in: 0.25 high / radial

Female radial c: +0.04

Outer wall: 1.46

Tube bore: 3.20 (not accessory fit)

Roof ribs: 1.20; bridge gap <=6.80

Front row reserved (no stud/socket)

NP3 dovetail side allowance: 0.20

See front-interface.svg for sections

# BASE3-06x10-T-6e100f

Three orthographic views + underside from the actual solid. Exterior heights include studs / text.

## FRONT

47.80

11.40

## SIDE

79.80

TOP / PRINT ORIENTATION | BOTTOM / REAL CAVITIES

Kind: front_base

STL: BASE3-06x10-T-6e100f.stl

STL units: mm / scale 100%

Grid: 6 x 10 @ 8.00

Body height: 9.60

Stud: dia 4.80 x 1.80 high

Tip lead-in: 0.25 high / radial

Female radial c: +0.04

Outer wall: 1.46

Tube bore: 3.20 (not accessory fit)

Roof ribs: 1.20; bridge gap <=6.80

Front row reserved (no stud/socket)

NP3 dovetail side allowance: 0.20

See front-interface.svg for sections

# BASE3-06x10-T-838259

Three orthographic views + underside from the actual solid. Exterior heights include studs / text.

## FRONT

47.80

11.40

## SIDE

76.40

TOP / PRINT ORIENTATION | BOTTOM / REAL CAVITIES

Kind: front_base

STL: BASE3-06x10-T-838259.stl

STL units: mm / scale 100%

Grid: 6 x 10 @ 8.00

Body height: 9.60

Stud: dia 4.80 x 1.80 high

Tip lead-in: 0.25 high / radial

Female radial c: +0.04

Outer wall: 1.46

Tube bore: 3.20 (not accessory fit)

Roof ribs: 1.20; bridge gap <=6.80

Front row reserved (no stud/socket)

NP3 dovetail side allowance: 0.20

See front-interface.svg for sections

# BASE3-06x10-T-e1945a

Three orthographic views + underside from the actual solid. Exterior heights include studs / text.

## FRONT

47.80

11.40

## SIDE

79.80

TOP / PRINT ORIENTATION | BOTTOM / REAL CAVITIES

Kind: front_base

STL: BASE3-06x10-T-e1945a.stl

STL units: mm / scale 100%

Grid: 6 x 10 @ 8.00

Body height: 9.60

Stud: dia 4.80 x 1.80 high

Tip lead-in: 0.25 high / radial

Female radial c: +0.04

Outer wall: 1.46

Tube bore: 3.20 (not accessory fit)

Roof ribs: 1.20; bridge gap <=6.80

Front row reserved (no stud/socket)

NP3 dovetail side allowance: 0.20

See front-interface.svg for sections

# BASE3-24x10-B-562406

Three orthographic views + underside from the actual solid. Exterior heights include studs / text.

## FRONT

191.80

11.40

## SIDE

79.80

TOP / PRINT ORIENTATION | BOTTOM / REAL CAVITIES

Kind: front_base

STL: BASE3-24x10-B-562406.stl

STL units: mm / scale 100%

Grid: 24 x 10 @ 8.00

Body height: 9.60

Stud: dia 4.80 x 1.80 high

Tip lead-in: 0.25 high / radial

Female radial c: +0.04

Outer wall: 1.46

Tube bore: 3.20 (not accessory fit)

Roof ribs: 1.20; bridge gap <=6.80

Front row reserved (no stud/socket)

NP3 dovetail side allowance: 0.20

See front-interface.svg for sections

# BR-01x04-H096

Three orthographic views + underside from the actual solid. Exterior heights include studs / text.

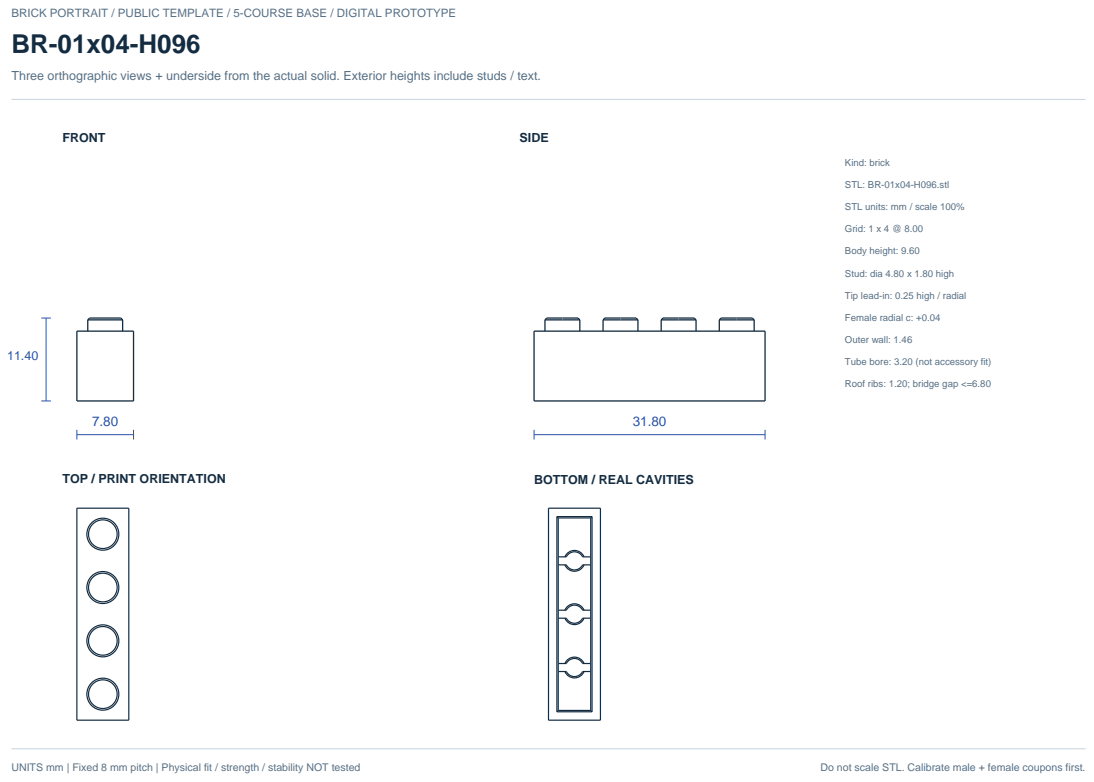
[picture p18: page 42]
FRONT; SIDE; TOP / PRINT ORIENTATION; BOTTOM / REAL CAVITIES; Kind: brick; Grid: 1 x 4 @ 8.00; Body height: 9.60; Female radial c: +0.04; Outer wall: 1.46

STL: BR-01x04-H096.stl

STL units: mm / scale 100%

Stud: dia 4.80 x 1.80 high

Tip lead-in: 0.25 high / radial

Tube bore: 3.20 (not accessory fit)

Roof ribs: 1.20; bridge gap <=6.80

# BR-02x04-H064

Three orthographic views + underside from the actual solid. Exterior heights include studs / text.

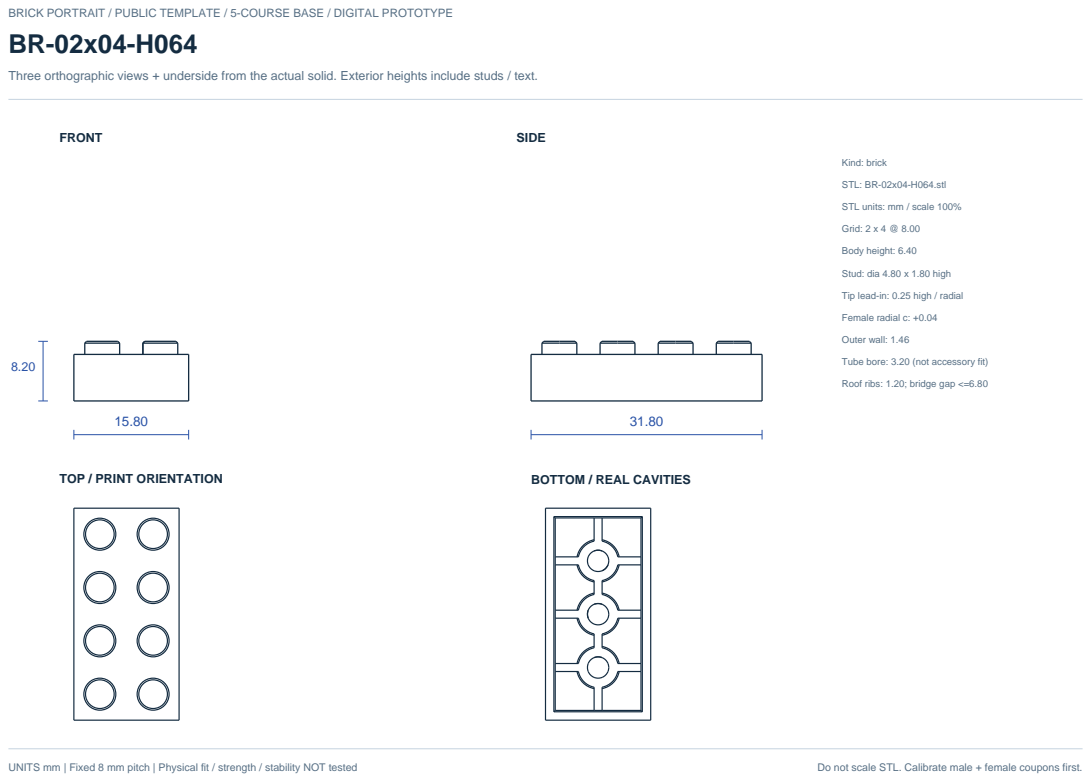
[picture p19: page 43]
FRONT; SIDE; TOP / PRINT ORIENTATION; BOTTOM / REAL CAVITIES; Kind: brick; Grid: 2 x 4 @ 8.00; Body height: 6.40; Female radial c: +0.04; Outer wall: 1.46

STL: BR-02x04-H064.stl

STL units: mm / scale 100%

Stud: dia 4.80 x 1.80 high

Tip lead-in: 0.25 high / radial

Tube bore: 3.20 (not accessory fit)

Roof ribs: 1.20; bridge gap <=6.80

# BR-02x04-H096

Three orthographic views + underside from the actual solid. Exterior heights include studs / text.

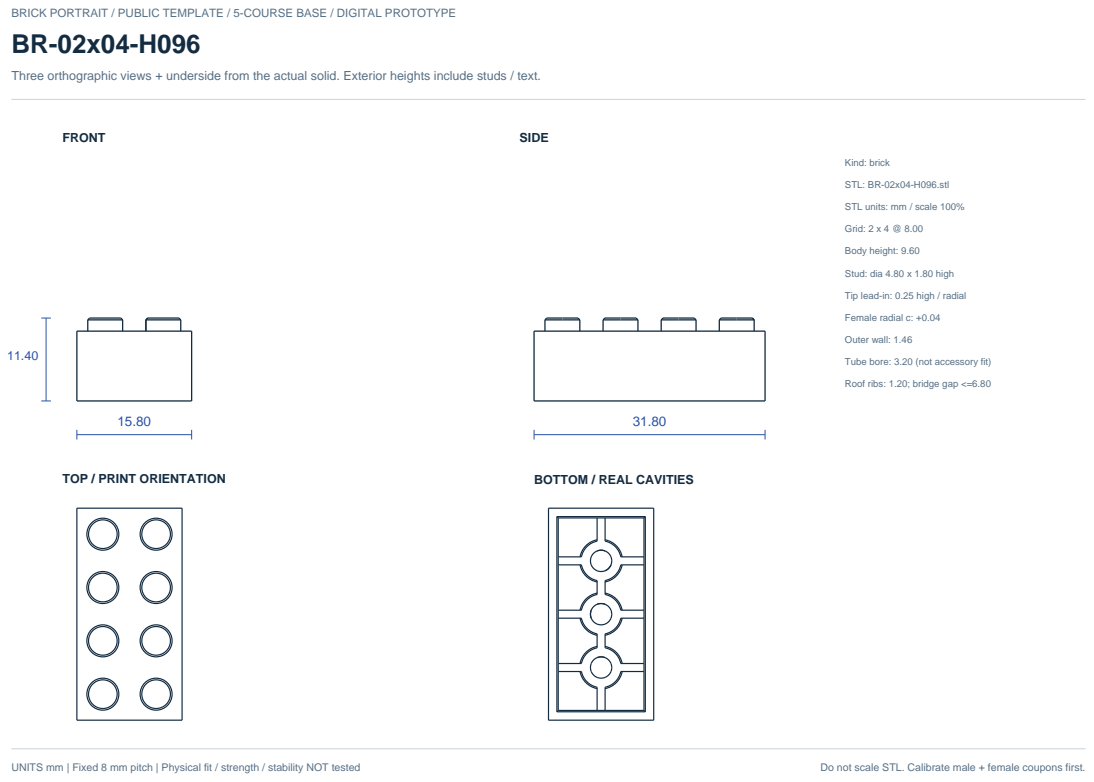
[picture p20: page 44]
FRONT; SIDE; TOP / PRINT ORIENTATION; BOTTOM / REAL CAVITIES; Kind: brick; Grid: 2 x 4 @ 8.00; Body height: 9.60; Female radial c: +0.04; Outer wall: 1.46

STL: BR-02x04-H096.stl

STL units: mm / scale 100%

Stud: dia 4.80 x 1.80 high

Tip lead-in: 0.25 high / radial

Tube bore: 3.20 (not accessory fit)

Roof ribs: 1.20; bridge gap <=6.80

# BR-02x05-H096

Three orthographic views + underside from the actual solid. Exterior heights include studs / text.

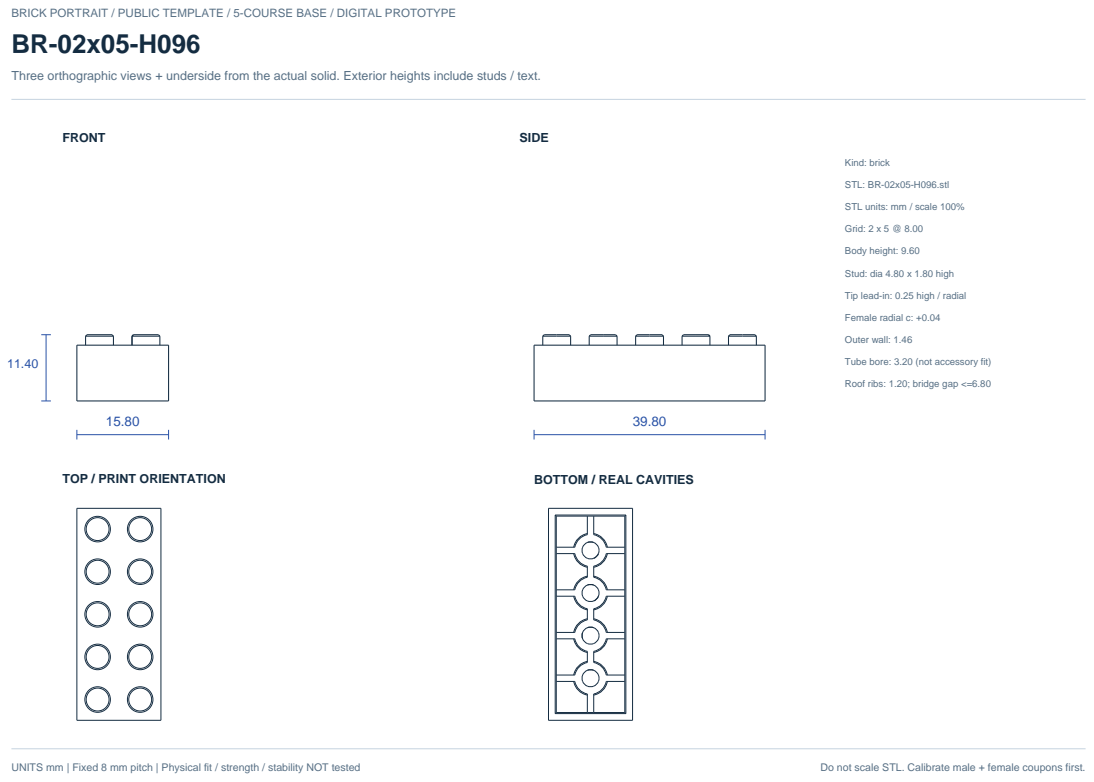
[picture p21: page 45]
FRONT; SIDE; TOP / PRINT ORIENTATION; BOTTOM / REAL CAVITIES; Kind: brick; Grid: 2 x 5 @ 8.00; Body height: 9.60; Female radial c: +0.04; Outer wall: 1.46

STL: BR-02x05-H096.stl

STL units: mm / scale 100%

Stud: dia 4.80 x 1.80 high

Tip lead-in: 0.25 high / radial

Tube bore: 3.20 (not accessory fit)

Roof ribs: 1.20; bridge gap <=6.80

# BR-02x06-H096

Three orthographic views + underside from the actual solid. Exterior heights include studs / text.

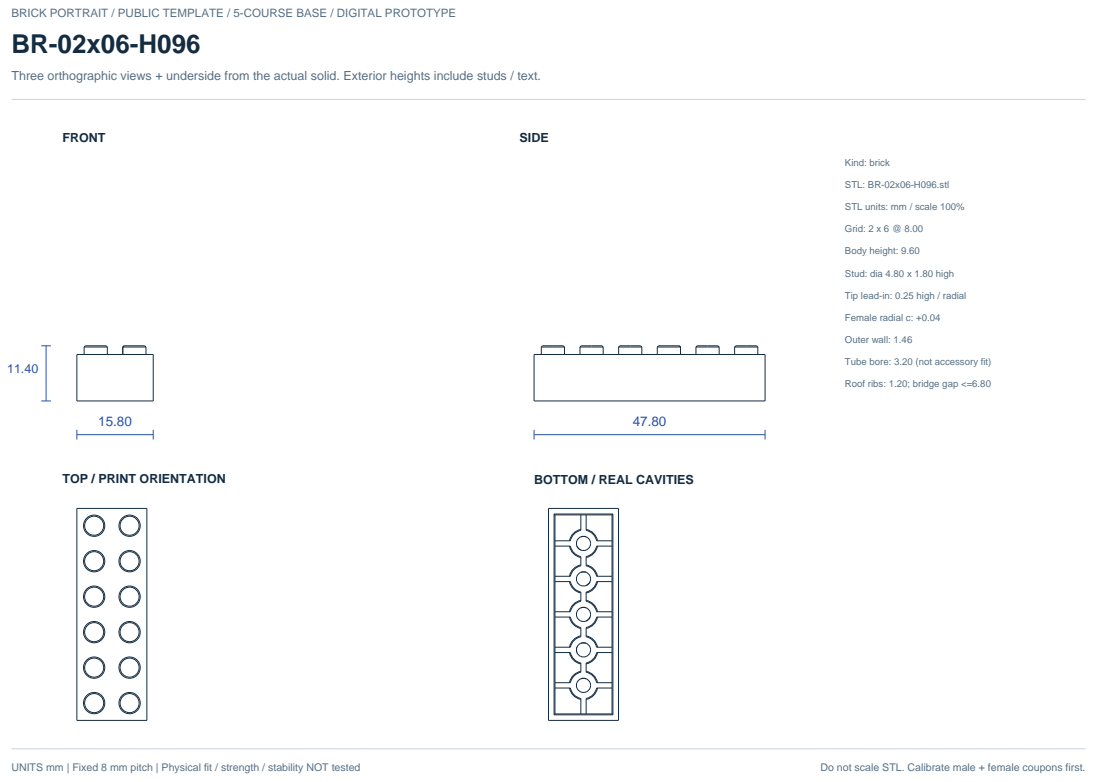
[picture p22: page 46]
FRONT; SIDE; TOP / PRINT ORIENTATION; BOTTOM / REAL CAVITIES; Kind: brick; Grid: 2 x 6 @ 8.00; Body height: 9.60; Female radial c: +0.04; Outer wall: 1.46

STL: BR-02x06-H096.stl

STL units: mm / scale 100%

Stud: dia 4.80 x 1.80 high

Tip lead-in: 0.25 high / radial

Tube bore: 3.20 (not accessory fit)

Roof ribs: 1.20; bridge gap <=6.80

# BR-03x04-H096

Three orthographic views + underside from the actual solid. Exterior heights include studs / text.

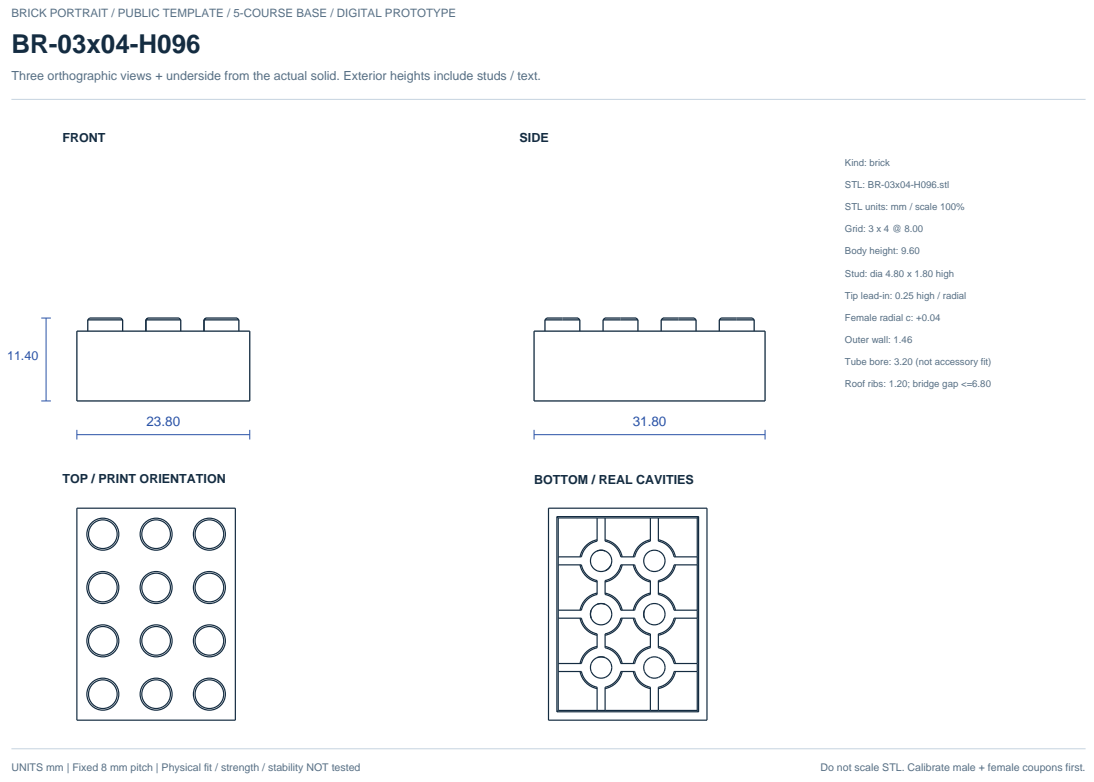
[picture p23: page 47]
FRONT; SIDE; TOP / PRINT ORIENTATION; BOTTOM / REAL CAVITIES; Kind: brick; Grid: 3 x 4 @ 8.00; Body height: 9.60; Female radial c: +0.04; Outer wall: 1.46

STL: BR-03x04-H096.stl

STL units: mm / scale 100%

Stud: dia 4.80 x 1.80 high

Tip lead-in: 0.25 high / radial

Tube bore: 3.20 (not accessory fit)

Roof ribs: 1.20; bridge gap <=6.80

# BR-04x04-H064

Three orthographic views + underside from the actual solid. Exterior heights include studs / text.

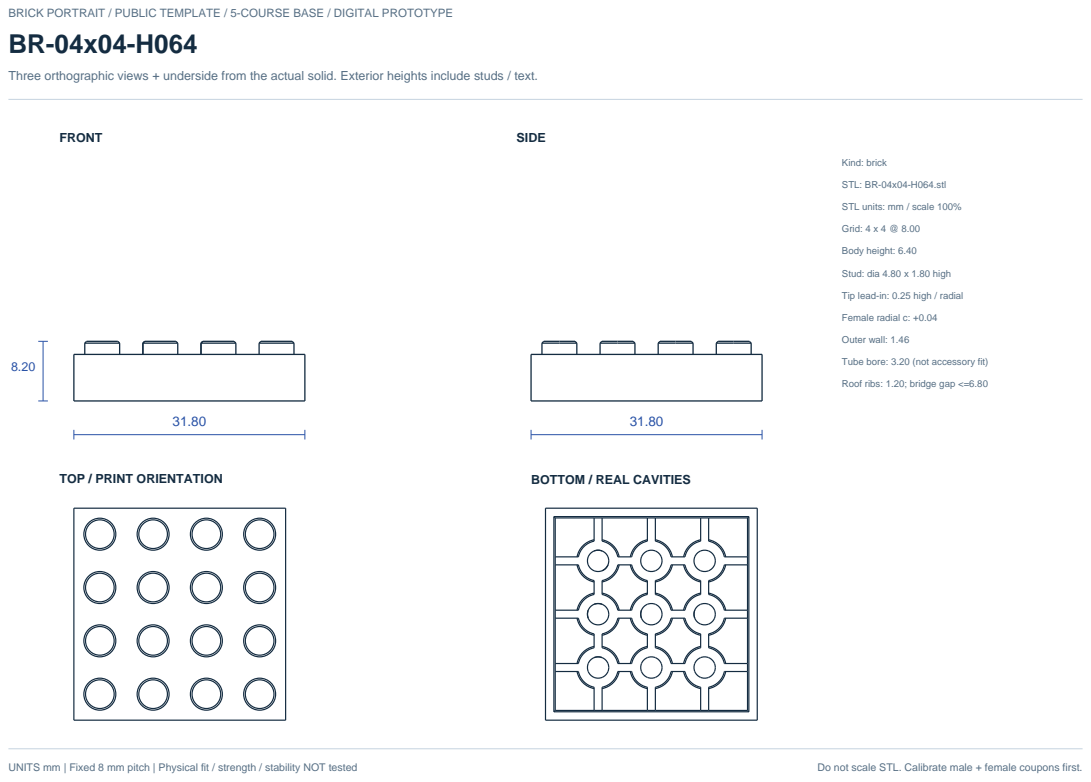
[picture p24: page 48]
FRONT; SIDE; TOP / PRINT ORIENTATION; BOTTOM / REAL CAVITIES; Kind: brick; Grid: 4 x 4 @ 8.00; Body height: 6.40; Female radial c: +0.04; Outer wall: 1.46

STL: BR-04x04-H064.stl

STL units: mm / scale 100%

Stud: dia 4.80 x 1.80 high

Tip lead-in: 0.25 high / radial

Tube bore: 3.20 (not accessory fit)

Roof ribs: 1.20; bridge gap <=6.80

# BR-04x04-H096

Three orthographic views + underside from the actual solid. Exterior heights include studs / text.

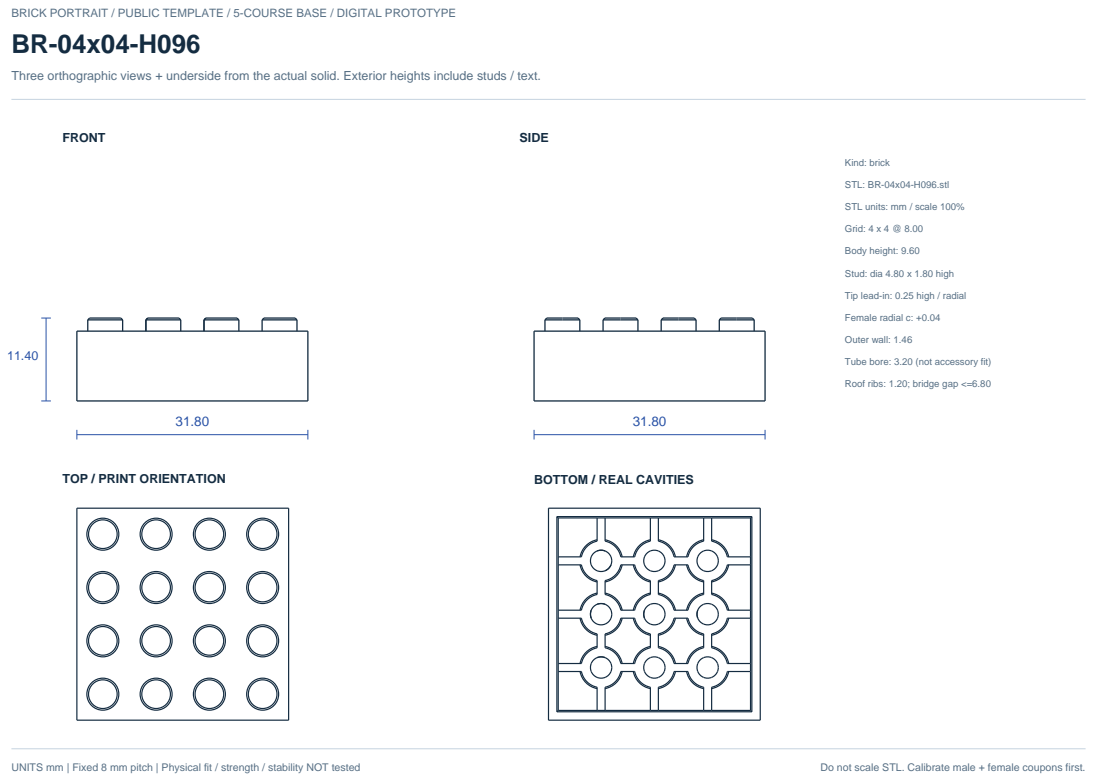
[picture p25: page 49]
FRONT; SIDE; TOP / PRINT ORIENTATION; BOTTOM / REAL CAVITIES; Kind: brick; Grid: 4 x 4 @ 8.00; Body height: 9.60; Female radial c: +0.04; Outer wall: 1.46

STL: BR-04x04-H096.stl

STL units: mm / scale 100%

Stud: dia 4.80 x 1.80 high

Tip lead-in: 0.25 high / radial

Tube bore: 3.20 (not accessory fit)

Roof ribs: 1.20; bridge gap <=6.80

# BR-04x05-H096

Three orthographic views + underside from the actual solid. Exterior heights include studs / text.

FRONT; SIDE; TOP / PRINT ORIENTATION; BOTTOM / REAL CAVITIES; Kind: brick; Grid: 4 x 5 @ 8.00; Body height: 9.60; Female radial c: +0.04; Outer wall: 1.46

STL: BR-04x05-H096.stl

STL units: mm / scale 100%

Stud: dia 4.80 x 1.80 high

Tip lead-in: 0.25 high / radial

Tube bore: 3.20 (not accessory fit)

Roof ribs: 1.20; bridge gap <=6.80

# BR-05x04-H096

Three orthographic views + underside from the actual solid. Exterior heights include studs / text.

FRONT; SIDE; TOP / PRINT ORIENTATION; BOTTOM / REAL CAVITIES; Kind: brick; Grid: 5 x 4 @ 8.00; Body height: 9.60; Female radial c: +0.04; Outer wall: 1.46

STL: BR-05x04-H096.stl

STL units: mm / scale 100%

Stud: dia 4.80 x 1.80 high

Tip lead-in: 0.25 high / radial

Tube bore: 3.20 (not accessory fit)

Roof ribs: 1.20; bridge gap <=6.80

# NP3-KEEPER

Three orthographic views + underside from the actual solid. Exterior heights include studs / text.

## FRONT

15.80

3.20

## SIDE

15.80

TOP / PRINT ORIENTATION | BOTTOM / REAL CAVITIES

Kind: front_keeper

STL: NP3-KEEPER.stl

STL units: mm / scale 100%

Grid: 2 x 1 @ 8.00

Body height: 3.20

Female radial c: +0.04

Outer wall: 1.46

Tube bore: 3.20 (not accessory fit)

Roof ribs: 1.20; bridge gap <=6.80

Socket row at local Y=12.00

Flat front stop covers module top

Lift 6mm, then forward >=32mm and aside

# NP3-LOGO-B

Three orthographic views + underside from the actual solid. Exterior heights include studs / text.

FRONT; SIDE; TOP / PRINT ORIENTATION; BOTTOM / REAL CAVITIES; Kind: front_logo; Overall installed Z: 4.00 .. 44.00

STL: NP3-LOGO-B.stl

STL units: mm / scale 100%

Flat rear on bed / relief up

Carrier 2.40; side taper 2.00

Black to white after 2.80

White relief: 0.80; do not scale

# NP3-TEXT-B

Three orthographic views + underside from the actual solid. Exterior heights include studs / text.

FRONT; SIDE; TOP / PRINT ORIENTATION; BOTTOM / REAL CAVITIES; Kind: front_plaque; Overall installed Z: 4.00 .. 44.00

STL: NP3-TEXT-B.stl

STL units: mm / scale 100%

Flat rear on bed / relief up

Carrier 2.40; side taper 2.00

Black to white after 2.40

White relief: 1.20; do not scale

Same icon, New adventures

github.com/USER

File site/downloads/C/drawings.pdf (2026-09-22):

### BRICK PORTRAIT / PUBLIC TEMPLATE / 5-COURSE BASE / DIGITAL PROTOTYPE

# C / DISPLAY SCULPT

RIGHT SIDE; UNITS mm | Fixed 8 mm pitch | Physical fit / strength / stability NOT tested; Do not scale STL. Calibrate male + female coupons first.

Actual FreeCAD TechDraw projections; drawing dimensions, not a fit certification.

FRONT / face towards -Y

TOP / front at bottom

228 assembled parts / 33 numbered stages

Target: 240 x 112 x 288.4 (approx. height)
Measured CAD envelope: 239.8 x 112.2 x 286.6 incl. top studs

# C / EXPLODED ASSEMBLY

CAD-derived exploded view; displacement is illustrative, dimensions are not changed.

# EXPLODED FRONT

Actual solids, displaced only for this view.

Exact WebGL 100% offsets, centered up/down.

Do not measure assembly height here.

Use overview for final outside dimensions.

Insert parts downward in numbered order.

Front modules release before spreading.

Stud engagement != verified physical clutch.

## TEXT / flat printing view

## RIGHT LOGO / supported relief

# INTERFACE / SECTION & CLEARANCE

Project design candidates, NOT a proprietary tolerance standard. Geometry from FreeCAD planar sections.

## SECTION: Y = 4.00 / TWO 2x2 BRICKS


## 8.00 nominal pitch x 2

## JOINT SECTION: Z = 10.50

### Actual wall, tube, rib + mating stud outlines


### Blue: lower brick / black: upper socket

### Reference stud dia 4.80; candidate height 1.80

### Radial clearance c=+0.04 (default; untested)

### Inside wall offset 1.56 / wall thickness 1.46

### Tube OD 6.433708 / ID 3.20; grid rib 1.20

### Tip lead-in 0.25 / female lead-in 0.20 x 0.30

### Roof 1.60; thin plate roof 1.00

### Thin plate / keeper: nominal headroom 0.40

No forced fit. Tune male and female separately.

# NP3 / BASE-FRONT CAPTURE & REMOVAL

Actual BREP sections; precise dimensions apply to the nominal model, not guaranteed printed fit.

## B / HORIZONTAL SECTION Z=24 / FRONT 8mm BAND

## B message: 142.00

## B logo carrier: 40.00

## VERTICAL SECTION X=40

48.00

## Blue: installed modules; black: actual receiver / keepers

## Carrier thickness2.40 / rear flat0.80 / edge relief1.20

## Rear width -> front width: 2.00 inset on each X side

## Default side clearance0.20; coupon candidates0.15/0.20/0.25

## Text frontY=-0.30 / logo frontY=0.10; +0.40mm depth

## Both front modules fit in Z=4.00..44.00, inside48mm base

## 3 separate up-stops: text2 / logo1; stud-grid mounting

## Remove: up-stops up6, forward>=32; module up45

## Thread / glue / magnet / purchased fastener not required

## Physical clutch, retention, flatness and stability NOT tested

# C / COLOR BOM / 1

One STL geometry may be printed in several colors. Use the quantities for this model only.

PART ID | COLOR | QTY | PRINT FILE
BASE3-03x14-T-08700f | black | 2 | parts/BASE3-03x14-T-08700f.stl
BASE3-03x14-T-d96cba | black | 2 | parts/BASE3-03x14-T-d96cba.stl
BASE3-06x14-T-26e6b0 | black | 2 | parts/BASE3-06x14-T-26e6b0.stl
BASE3-06x14-T-5258a8 | black | 2 | parts/BASE3-06x14-T-5258a8.stl
BASE3-06x14-T-72d551 | black | 2 | parts/BASE3-06x14-T-72d551.stl
BASE3-06x14-T-afd244 | black | 2 | parts/BASE3-06x14-T-afd244.stl
BASE3-06x14-T-f6d8b7 | black | 10 | parts/BASE3-06x14-T-f6d8b7.stl
BASE3-15x14-B-2f9fc1 | black | 1 | parts/BASE3-15x14-B-2f9fc1.stl
BASE3-15x14-B-65597c | black | 1 | parts/BASE3-15x14-B-65597c.stl
BR-01x06-H096 | green | 10 | parts/BR-01x06-H096.stl
BR-02x06-H064 | magenta | 1 | parts/BR-02x06-H064.stl
BR-02x06-H096 | black | 36 | parts/BR-02x06-H096.stl
BR-02x07-H096 | magenta | 1 | parts/BR-02x07-H096.stl
BR-02x08-H096 | cyan | 29 | parts/BR-02x08-H096.stl
BR-02x10-H096 | magenta | 22 | parts/BR-02x10-H096.stl
BR-03x06-H096 | black | 6 | parts/BR-03x06-H096.stl
BR-04x06-H064 | magenta | 2 | parts/BR-04x06-H064.stl
BR-04x06-H096 | black | 68 | parts/BR-04x06-H096.stl
BR-04x07-H096 | magenta | 3 | parts/BR-04x07-H096.stl
BR-04x08-H096 | cyan | 17 | parts/BR-04x08-H096.stl
BR-05x06-H096 | black | 4 | parts/BR-05x06-H096.stl
NP3-KEEPER | black | 3 | parts/NP3-KEEPER.stl
NP3-LOGO-C | black | 1 | parts/NP3-LOGO-C.stl
NP3-TEXT-C | black | 1 | parts/NP3-TEXT-C.stl

TEXT: black -> white at 2.4mm; LOGO: black -> white at 2.8mm. Separate plates.

Assembly: 228 pieces, including 2 front modules + 3 keepers. Coupons separate.

# C / STEP 01 OF 33

Placement diagram from canonical part bounds. IDs match native CAD, BOM, viewer and animation.

## PLAN VIEW / front at bottom / NEW parts in color

001 002

## nominal 240 / grid 8.00

## FRONT (-Y) / new parts enter from above (+Z)

# ADD 2 PART(S)

### C-001 BLACK

BASE3-15x14-B-2f9fc1 @ 0,0,0

### C-002 BLACK

BASE3-15x14-B-65597c @ 120,0,0

Arrange two halves side-by-side. Next course spans the center seam.

# C / STEP 02 OF 33

Placement diagram from canonical part bounds. IDs match native CAD, BOM, viewer and animation.

## PLAN VIEW / front at bottom / NEW parts in color

003 | 004 | 005 | 006 | 007

## nominal 240 / grid 8.00

## FRONT (-Y) / new parts enter from above (+Z)

# ADD 5 PART(S)

### C-003 BLACK

BASE3-06x14-T-72d551 @ 0,0,9.6

### C-004 BLACK

BASE3-06x14-T-f6d8b7 @ 48,0,9.6

### C-005 BLACK

BASE3-06x14-T-f6d8b7 @ 96,0,9.6

### C-006 BLACK

BASE3-06x14-T-afd244 @ 144,0,9.6

### C-007 BLACK

BASE3-06x14-T-26e6b0 @ 192,0,9.6

# C / STEP 03 OF 33

Placement diagram from canonical part bounds. IDs match native CAD, BOM, viewer and animation.

## PLAN VIEW / front at bottom / NEW parts in color

008 | 009 | 010 | 011 | 012 | 013

## nominal 240 / grid 8.00

## FRONT (-Y) / new parts enter from above (+Z)

# ADD 6 PART(S)

### C-008 BLACK

BASE3-03x14-T-08700f @ 0,0,19.2

### C-009 BLACK

BASE3-06x14-T-f6d8b7 @ 24,0,19.2

### C-010 BLACK

BASE3-06x14-T-f6d8b7 @ 72,0,19.2

### C-011 BLACK

BASE3-06x14-T-f6d8b7 @ 120,0,19.2

### C-012 BLACK

BASE3-06x14-T-5258a8 @ 168,0,19.2

### C-013 BLACK

BASE3-03x14-T-d96cba @ 216,0,19.2

# C / STEP 04 OF 33

Placement diagram from canonical part bounds. IDs match native CAD, BOM, viewer and animation.

## PLAN VIEW / front at bottom / NEW parts in color

014 | 015 | 016 | 017 | 018

## nominal 240 / grid 8.00

## FRONT (-Y) / new parts enter from above (+Z)

# ADD 5 PART(S)

### C-014 BLACK

BASE3-06x14-T-72d551 @ 0,0,28.8

### C-015 BLACK

BASE3-06x14-T-f6d8b7 @ 48,0,28.8

### C-016 BLACK

BASE3-06x14-T-f6d8b7 @ 96,0,28.8

### C-017 BLACK

BASE3-06x14-T-afd244 @ 144,0,28.8

### C-018 BLACK

BASE3-06x14-T-26e6b0 @ 192,0,28.8

# C / STEP 05 OF 33

Placement diagram from canonical part bounds. IDs match native CAD, BOM, viewer and animation.

## PLAN VIEW / front at bottom / NEW parts in color

019 | 020 | 021 | 022 | 023 | 024

## nominal 240 / grid 8.00

## FRONT (-Y) / new parts enter from above (+Z)

# ADD 6 PART(S)

### C-019 BLACK

BASE3-03x14-T-08700f @ 0,0,38.4

### C-020 BLACK

BASE3-06x14-T-f6d8b7 @ 24,0,38.4

### C-021 BLACK

BASE3-06x14-T-f6d8b7 @ 72,0,38.4

### C-022 BLACK

BASE3-06x14-T-f6d8b7 @ 120,0,38.4

### C-023 BLACK

BASE3-06x14-T-5258a8 @ 168,0,38.4

### C-024 BLACK

BASE3-03x14-T-d96cba @ 216,0,38.4

# C / STEP 06 OF 33

Placement diagram from canonical part bounds. IDs match native CAD, BOM, viewer and animation.

## PLAN VIEW / front at bottom / NEW parts in color

025 026

## nominal 240 / grid 8.00

## FRONT (-Y) / new parts enter from above (+Z)

# ADD 2 PART(S)

### C-025 BLACK

NP3-TEXT-C @ 4,3.3,4

### C-026 BLACK

NP3-LOGO-C @ 188,3.7,4

# C / STEP 07 OF 33

Placement diagram from canonical part bounds. IDs match native CAD, BOM, viewer and animation.

## PLAN VIEW / front at bottom / NEW parts in color

027 | 028 | 029

## nominal 240 / grid 8.00

## FRONT (-Y) / new parts enter from above (+Z)

# ADD 3 PART(S)

### C-027 BLACK

NP3-KEEPER @ 0,0,48

### C-028 BLACK

NP3-KEEPER @ 168,0,48

### C-029 BLACK

NP3-KEEPER @ 200,0,48

# C / STEP 08 OF 33

Placement diagram from canonical part bounds. IDs match native CAD, BOM, viewer and animation.

## PLAN VIEW / front at bottom / NEW parts in color

030 | 031 | 032 | 033

## nominal 240 / grid 8.00

## FRONT (-Y) / new parts enter from above (+Z)

# ADD 4 PART(S)

### C-030 MAGENTA

BR-04x07-H096 @ 64,32,48

### C-031 MAGENTA

BR-04x07-H096 @ 96,32,48

### C-032 MAGENTA

BR-04x07-H096 @ 128,32,48

### C-033 MAGENTA

BR-02x07-H096 @ 160,32,48

# C / STEP 09 OF 33

Placement diagram from canonical part bounds. IDs match native CAD, BOM, viewer and animation.

## PLAN VIEW / front at bottom / NEW parts in color

034

035 | 036 | 037 | 038
039

## nominal 240 / grid 8.00

## FRONT (-Y) / new parts enter from above (+Z)

# ADD 6 PART(S)

### C-034 MAGENTA

BR-02x10-H096 @ 56,16,57.6

### C-035 BLACK

BR-02x06-H096 @ 72,40,57.6

### C-036 BLACK

BR-04x06-H096 @ 88,40,57.6

### C-037 BLACK

BR-04x06-H096 @ 120,40,57.6

### C-038 BLACK

BR-02x06-H096 @ 152,40,57.6

### C-039 MAGENTA

BR-02x10-H096 @ 168,16,57.6

# C / STEP 10 OF 33

Placement diagram from canonical part bounds. IDs match native CAD, BOM, viewer and animation.

## PLAN VIEW / front at bottom / NEW parts in color

040

041 | 042 | 043 | 044
045

## nominal 240 / grid 8.00

## FRONT (-Y) / new parts enter from above (+Z)

# ADD 6 PART(S)

### C-040 MAGENTA

BR-02x10-H096 @ 48,16,67.2

### C-041 BLACK

BR-04x06-H096 @ 64,40,67.2

### C-042 BLACK

BR-04x06-H096 @ 96,40,67.2

### C-043 BLACK

BR-04x06-H096 @ 128,40,67.2

### C-044 BLACK

BR-02x06-H096 @ 160,40,67.2

### C-045 MAGENTA

BR-02x10-H096 @ 176,16,67.2

# C / STEP 11 OF 33

Placement diagram from canonical part bounds. IDs match native CAD, BOM, viewer and animation.

## PLAN VIEW / front at bottom / NEW parts in color

046

047 | 048 | 049 | 050 | 051
052

## nominal 240 / grid 8.00

## FRONT (-Y) / new parts enter from above (+Z)

# ADD 7 PART(S)

### C-046 MAGENTA

BR-02x10-H096 @ 40,16,76.8

### C-047 BLACK

BR-02x06-H096 @ 56,40,76.8

### C-048 BLACK

BR-04x06-H096 @ 72,40,76.8

### C-049 BLACK

BR-04x06-H096 @ 104,40,76.8

### C-050 BLACK

BR-04x06-H096 @ 136,40,76.8

### C-051 BLACK

BR-02x06-H096 @ 168,40,76.8

### C-052 MAGENTA

BR-02x10-H096 @ 184,16,76.8

# C / STEP 12 OF 33

Placement diagram from canonical part bounds. IDs match native CAD, BOM, viewer and animation.

## PLAN VIEW / front at bottom / NEW parts in color

053

054 | 055 | 056 | 057 | 058
059

## nominal 240 / grid 8.00

## FRONT (-Y) / new parts enter from above (+Z)

# ADD 7 PART(S)

### C-053 MAGENTA

BR-02x10-H096 @ 32,16,86.4

### C-054 BLACK

BR-04x06-H096 @ 48,40,86.4

### C-055 BLACK

BR-04x06-H096 @ 80,40,86.4

### C-056 BLACK

BR-04x06-H096 @ 112,40,86.4

### C-057 BLACK

BR-04x06-H096 @ 144,40,86.4

### C-058 BLACK

BR-02x06-H096 @ 176,40,86.4

### C-059 MAGENTA

BR-02x10-H096 @ 192,16,86.4

# C / STEP 13 OF 33

Placement diagram from canonical part bounds. IDs match native CAD, BOM, viewer and animation.

## PLAN VIEW / front at bottom / NEW parts in color

060

061 | 062 | 063 | 064 | 065 | 066
067

## nominal 240 / grid 8.00

## FRONT (-Y) / new parts enter from above (+Z)

# ADD 8 PART(S)

### C-060 MAGENTA

BR-02x10-H096 @ 24,16,96

### C-061 BLACK

BR-02x06-H096 @ 40,40,96

### C-062 BLACK

BR-04x06-H096 @ 56,40,96

### C-063 BLACK

BR-04x06-H096 @ 88,40,96

### C-064 BLACK

BR-04x06-H096 @ 120,40,96

### C-065 BLACK

BR-04x06-H096 @ 152,40,96

### C-066 BLACK

BR-02x06-H096 @ 184,40,96

### C-067 MAGENTA

BR-02x10-H096 @ 200,16,96

# C / STEP 14 OF 33

Placement diagram from canonical part bounds. IDs match native CAD, BOM, viewer and animation.

## PLAN VIEW / front at bottom / NEW parts in color

068

069 | 070 | 071 | 072 | 073 | 074 | 075 | 076
077

## nominal 240 / grid 8.00

## FRONT (-Y) / new parts enter from above (+Z)

# ADD 10 PART(S)

### C-068 MAGENTA

BR-02x10-H096 @ 16,16,105.6

### C-069 BLACK

BR-04x06-H096 @ 32,40,105.6

### C-070 BLACK

BR-03x06-H096 @ 64,40,105.6

### C-071 GREEN

BR-01x06-H096 @ 88,40,105.6

### C-072 BLACK

BR-04x06-H096 @ 96,40,105.6

### C-073 BLACK

BR-02x06-H096 @ 128,40,105.6

### C-074 GREEN

BR-01x06-H096 @ 144,40,105.6

### C-075 BLACK

BR-04x06-H096 @ 152,40,105.6

### C-076 BLACK

BR-03x06-H096 @ 184,40,105.6

### C-077 MAGENTA

BR-02x10-H096 @ 208,16,105.6

# C / STEP 15 OF 33

Placement diagram from canonical part bounds. IDs match native CAD, BOM, viewer and animation.

## PLAN VIEW / front at bottom / NEW parts in color

078

079 | 080 | 081 | 082 | 083 | 084 | 085 | 086
087

## nominal 240 / grid 8.00

## FRONT (-Y) / new parts enter from above (+Z)

# ADD 10 PART(S)

### C-078 MAGENTA

BR-02x10-H096 @ 16,16,115.2

### C-079 BLACK

BR-02x06-H096 @ 32,40,115.2

### C-080 BLACK

BR-05x06-H096 @ 48,40,115.2

### C-081 GREEN

BR-01x06-H096 @ 88,40,115.2

### C-082 BLACK

BR-02x06-H096 @ 96,40,115.2

### C-083 BLACK

BR-04x06-H096 @ 112,40,115.2

### C-084 GREEN

BR-01x06-H096 @ 144,40,115.2

### C-085 BLACK

BR-02x06-H096 @ 152,40,115.2

### C-086 BLACK

BR-05x06-H096 @ 168,40,115.2

### C-087 MAGENTA

BR-02x10-H096 @ 208,16,115.2

# C / STEP 16 OF 33

Placement diagram from canonical part bounds. IDs match native CAD, BOM, viewer and animation.

## PLAN VIEW / front at bottom / NEW parts in color

088

089 | 090 | 091 | 092 | 093 | 094 | 095 | 096
097

## nominal 240 / grid 8.00

## FRONT (-Y) / new parts enter from above (+Z)

# ADD 10 PART(S)

### C-088 MAGENTA

BR-02x10-H096 @ 16,16,124.8

### C-089 BLACK

BR-04x06-H096 @ 32,40,124.8

### C-090 BLACK

BR-03x06-H096 @ 64,40,124.8

### C-091 GREEN

BR-01x06-H096 @ 88,40,124.8

### C-092 BLACK

BR-04x06-H096 @ 96,40,124.8

### C-093 BLACK

BR-02x06-H096 @ 128,40,124.8

### C-094 GREEN

BR-01x06-H096 @ 144,40,124.8

### C-095 BLACK

BR-04x06-H096 @ 152,40,124.8

### C-096 BLACK

BR-03x06-H096 @ 184,40,124.8

### C-097 MAGENTA

BR-02x10-H096 @ 208,16,124.8

# C / STEP 17 OF 33

Placement diagram from canonical part bounds. IDs match native CAD, BOM, viewer and animation.

## PLAN VIEW / front at bottom / NEW parts in color

098

099 | 100 | 101 | 102 | 103 | 104 | 105 | 106
107

## nominal 240 / grid 8.00

## FRONT (-Y) / new parts enter from above (+Z)

# ADD 10 PART(S)

### C-098 MAGENTA

BR-02x10-H096 @ 16,16,134.4

### C-099 BLACK

BR-02x06-H096 @ 32,40,134.4

### C-100 BLACK

BR-05x06-H096 @ 48,40,134.4

### C-101 GREEN

BR-01x06-H096 @ 88,40,134.4

### C-102 BLACK

BR-02x06-H096 @ 96,40,134.4

### C-103 BLACK

BR-04x06-H096 @ 112,40,134.4

### C-104 GREEN

BR-01x06-H096 @ 144,40,134.4

### C-105 BLACK

BR-02x06-H096 @ 152,40,134.4

### C-106 BLACK

BR-05x06-H096 @ 168,40,134.4

### C-107 MAGENTA

BR-02x10-H096 @ 208,16,134.4

# C / STEP 18 OF 33

Placement diagram from canonical part bounds. IDs match native CAD, BOM, viewer and animation.

## PLAN VIEW / front at bottom / NEW parts in color

108

109 | 110 | 111 | 112 | 113 | 114 | 115 | 116
117

## nominal 240 / grid 8.00

## FRONT (-Y) / new parts enter from above (+Z)

# ADD 10 PART(S)

### C-108 MAGENTA

BR-02x10-H096 @ 16,16,144

### C-109 BLACK

BR-04x06-H096 @ 32,40,144

### C-110 BLACK

BR-03x06-H096 @ 64,40,144

### C-111 GREEN

BR-01x06-H096 @ 88,40,144

### C-112 BLACK

BR-04x06-H096 @ 96,40,144

### C-113 BLACK

BR-02x06-H096 @ 128,40,144

### C-114 GREEN

BR-01x06-H096 @ 144,40,144

### C-115 BLACK

BR-04x06-H096 @ 152,40,144

### C-116 BLACK

BR-03x06-H096 @ 184,40,144

### C-117 MAGENTA

BR-02x10-H096 @ 208,16,144

# C / STEP 19 OF 33

Placement diagram from canonical part bounds. IDs match native CAD, BOM, viewer and animation.

## PLAN VIEW / front at bottom / NEW parts in color

118

119 | 120 | 121 | 122 | 123 | 124
125

## nominal 240 / grid 8.00

## FRONT (-Y) / new parts enter from above (+Z)

# ADD 8 PART(S)

### C-118 MAGENTA

BR-02x10-H096 @ 16,16,153.6

### C-119 BLACK

BR-02x06-H096 @ 32,40,153.6

### C-120 BLACK

BR-04x06-H096 @ 48,40,153.6

### C-121 BLACK

BR-04x06-H096 @ 80,40,153.6

### C-122 BLACK

BR-04x06-H096 @ 112,40,153.6

### C-123 BLACK

BR-04x06-H096 @ 144,40,153.6

### C-124 BLACK

BR-04x06-H096 @ 176,40,153.6

### C-125 MAGENTA

BR-02x10-H096 @ 208,16,153.6

# C / STEP 20 OF 33

Placement diagram from canonical part bounds. IDs match native CAD, BOM, viewer and animation.

## PLAN VIEW / front at bottom / NEW parts in color

126 | 127 | 128 | 129 | 130 | 131 | 132

## nominal 240 / grid 8.00

## FRONT (-Y) / new parts enter from above (+Z)

# ADD 7 PART(S)

### C-126 CYAN

BR-04x08-H096 @ 16,24,163.2

### C-127 CYAN

BR-04x08-H096 @ 48,24,163.2

### C-128 CYAN

BR-04x08-H096 @ 80,24,163.2

### C-129 CYAN

BR-04x08-H096 @ 112,24,163.2

### C-130 CYAN

BR-04x08-H096 @ 144,24,163.2

### C-131 CYAN

BR-04x08-H096 @ 176,24,163.2

### C-132 CYAN

BR-02x08-H096 @ 208,24,163.2

# C / STEP 21 OF 33

Placement diagram from canonical part bounds. IDs match native CAD, BOM, viewer and animation.

## PLAN VIEW / front at bottom / NEW parts in color

133

134 | 135 | 136
137
138 | 139 | 140
141

## nominal 240 / grid 8.00

## FRONT (-Y) / new parts enter from above (+Z)

# ADD 9 PART(S)

### C-133 CYAN

BR-02x08-H096 @ 16,24,172.8

### C-134 BLACK

BR-02x06-H096 @ 32,40,172.8

### C-135 BLACK

BR-04x06-H096 @ 48,40,172.8

### C-136 BLACK

BR-04x06-H096 @ 80,40,172.8

### C-137 CYAN

BR-02x08-H096 @ 112,24,172.8

### C-138 BLACK

BR-02x06-H096 @ 128,40,172.8

### C-139 BLACK

BR-04x06-H096 @ 144,40,172.8

### C-140 BLACK

BR-04x06-H096 @ 176,40,172.8

### C-141 CYAN

BR-02x08-H096 @ 208,24,172.8

# C / STEP 22 OF 33

Placement diagram from canonical part bounds. IDs match native CAD, BOM, viewer and animation.

## PLAN VIEW / front at bottom / NEW parts in color

142

143 | 144 | 145
146
147 | 148 | 149
150

## nominal 240 / grid 8.00

## FRONT (-Y) / new parts enter from above (+Z)

# ADD 9 PART(S)

### C-142 CYAN

BR-02x08-H096 @ 16,24,182.4

### C-143 BLACK

BR-04x06-H096 @ 32,40,182.4

### C-144 BLACK

BR-04x06-H096 @ 64,40,182.4

### C-145 BLACK

BR-02x06-H096 @ 96,40,182.4

### C-146 CYAN

BR-02x08-H096 @ 112,24,182.4

### C-147 BLACK

BR-04x06-H096 @ 128,40,182.4

### C-148 BLACK

BR-04x06-H096 @ 160,40,182.4

### C-149 BLACK

BR-02x06-H096 @ 192,40,182.4

### C-150 CYAN

BR-02x08-H096 @ 208,24,182.4

# C / STEP 23 OF 33

Placement diagram from canonical part bounds. IDs match native CAD, BOM, viewer and animation.

## PLAN VIEW / front at bottom / NEW parts in color

151

152 | 153 | 154
155
156 | 157 | 158
159

## nominal 240 / grid 8.00

## FRONT (-Y) / new parts enter from above (+Z)

# ADD 9 PART(S)

### C-151 CYAN

BR-02x08-H096 @ 16,24,192

### C-152 BLACK

BR-02x06-H096 @ 32,40,192

### C-153 BLACK

BR-04x06-H096 @ 48,40,192

### C-154 BLACK

BR-04x06-H096 @ 80,40,192

### C-155 CYAN

BR-02x08-H096 @ 112,24,192

### C-156 BLACK

BR-02x06-H096 @ 128,40,192

### C-157 BLACK

BR-04x06-H096 @ 144,40,192

### C-158 BLACK

BR-04x06-H096 @ 176,40,192

### C-159 CYAN

BR-02x08-H096 @ 208,24,192

# C / STEP 24 OF 33

Placement diagram from canonical part bounds. IDs match native CAD, BOM, viewer and animation.

## PLAN VIEW / front at bottom / NEW parts in color

160

161 | 162 | 163
164
165 | 166 | 167
168

## nominal 240 / grid 8.00

## FRONT (-Y) / new parts enter from above (+Z)

# ADD 9 PART(S)

### C-160 CYAN

BR-02x08-H096 @ 16,24,201.6

### C-161 BLACK

BR-04x06-H096 @ 32,40,201.6

### C-162 BLACK

BR-04x06-H096 @ 64,40,201.6

### C-163 BLACK

BR-02x06-H096 @ 96,40,201.6

### C-164 CYAN

BR-02x08-H096 @ 112,24,201.6

### C-165 BLACK

BR-04x06-H096 @ 128,40,201.6

### C-166 BLACK

BR-04x06-H096 @ 160,40,201.6

### C-167 BLACK

BR-02x06-H096 @ 192,40,201.6

### C-168 CYAN

BR-02x08-H096 @ 208,24,201.6

# C / STEP 25 OF 33

Placement diagram from canonical part bounds. IDs match native CAD, BOM, viewer and animation.

## PLAN VIEW / front at bottom / NEW parts in color

169

170 | 171 | 172
173
174 | 175 | 176
177

## nominal 240 / grid 8.00

## FRONT (-Y) / new parts enter from above (+Z)

# ADD 9 PART(S)

### C-169 CYAN

BR-02x08-H096 @ 16,24,211.2

### C-170 BLACK

BR-02x06-H096 @ 32,40,211.2

### C-171 BLACK

BR-04x06-H096 @ 48,40,211.2

### C-172 BLACK

BR-04x06-H096 @ 80,40,211.2

### C-173 CYAN

BR-02x08-H096 @ 112,24,211.2

### C-174 BLACK

BR-02x06-H096 @ 128,40,211.2

### C-175 BLACK

BR-04x06-H096 @ 144,40,211.2

### C-176 BLACK

BR-04x06-H096 @ 176,40,211.2

### C-177 CYAN

BR-02x08-H096 @ 208,24,211.2

# C / STEP 26 OF 33

Placement diagram from canonical part bounds. IDs match native CAD, BOM, viewer and animation.

## PLAN VIEW / front at bottom / NEW parts in color

178

179 | 180 | 181
182
183 | 184 | 185
186

## nominal 240 / grid 8.00

## FRONT (-Y) / new parts enter from above (+Z)

# ADD 9 PART(S)

### C-178 CYAN

BR-02x08-H096 @ 16,24,220.8

### C-179 BLACK

BR-04x06-H096 @ 32,40,220.8

### C-180 BLACK

BR-04x06-H096 @ 64,40,220.8

### C-181 BLACK

BR-02x06-H096 @ 96,40,220.8

### C-182 CYAN

BR-02x08-H096 @ 112,24,220.8

### C-183 BLACK

BR-04x06-H096 @ 128,40,220.8

### C-184 BLACK

BR-04x06-H096 @ 160,40,220.8

### C-185 BLACK

BR-02x06-H096 @ 192,40,220.8

### C-186 CYAN

BR-02x08-H096 @ 208,24,220.8

# C / STEP 27 OF 33

Placement diagram from canonical part bounds. IDs match native CAD, BOM, viewer and animation.

## PLAN VIEW / front at bottom / NEW parts in color

187

188 | 189 | 190
191
192 | 193 | 194
195

## nominal 240 / grid 8.00

## FRONT (-Y) / new parts enter from above (+Z)

# ADD 9 PART(S)

### C-187 CYAN

BR-02x08-H096 @ 16,24,230.4

### C-188 BLACK

BR-02x06-H096 @ 32,40,230.4

### C-189 BLACK

BR-04x06-H096 @ 48,40,230.4

### C-190 BLACK

BR-04x06-H096 @ 80,40,230.4

### C-191 CYAN

BR-02x08-H096 @ 112,24,230.4

### C-192 BLACK

BR-02x06-H096 @ 128,40,230.4

### C-193 BLACK

BR-04x06-H096 @ 144,40,230.4

### C-194 BLACK

BR-04x06-H096 @ 176,40,230.4

### C-195 CYAN

BR-02x08-H096 @ 208,24,230.4

# C / STEP 28 OF 33

Placement diagram from canonical part bounds. IDs match native CAD, BOM, viewer and animation.

## PLAN VIEW / front at bottom / NEW parts in color

196

197 | 198 | 199
200
201 | 202 | 203
204

## nominal 240 / grid 8.00

## FRONT (-Y) / new parts enter from above (+Z)

# ADD 9 PART(S)

### C-196 CYAN

BR-02x08-H096 @ 16,24,240

### C-197 BLACK

BR-04x06-H096 @ 32,40,240

### C-198 BLACK

BR-04x06-H096 @ 64,40,240

### C-199 BLACK

BR-02x06-H096 @ 96,40,240

### C-200 CYAN

BR-02x08-H096 @ 112,24,240

### C-201 BLACK

BR-04x06-H096 @ 128,40,240

### C-202 BLACK

BR-04x06-H096 @ 160,40,240

### C-203 BLACK

BR-02x06-H096 @ 192,40,240

### C-204 CYAN

BR-02x08-H096 @ 208,24,240

# C / STEP 29 OF 33

Placement diagram from canonical part bounds. IDs match native CAD, BOM, viewer and animation.

## PLAN VIEW / front at bottom / NEW parts in color

205

206 | 207 | 208
209
210 | 211 | 212
213

## nominal 240 / grid 8.00

## FRONT (-Y) / new parts enter from above (+Z)

# ADD 9 PART(S)

### C-205 CYAN

BR-02x08-H096 @ 16,24,249.6

### C-206 BLACK

BR-02x06-H096 @ 32,40,249.6

### C-207 BLACK

BR-04x06-H096 @ 48,40,249.6

### C-208 BLACK

BR-04x06-H096 @ 80,40,249.6

### C-209 CYAN

BR-02x08-H096 @ 112,24,249.6

### C-210 BLACK

BR-02x06-H096 @ 128,40,249.6

### C-211 BLACK

BR-04x06-H096 @ 144,40,249.6

### C-212 BLACK

BR-04x06-H096 @ 176,40,249.6

### C-213 CYAN

BR-02x08-H096 @ 208,24,249.6

# C / STEP 30 OF 33

Placement diagram from canonical part bounds. IDs match native CAD, BOM, viewer and animation.

## PLAN VIEW / front at bottom / NEW parts in color

214 | 215 | 216 | 217 | 218 | 219

## nominal 240 / grid 8.00

## FRONT (-Y) / new parts enter from above (+Z)

# ADD 6 PART(S)

### C-214 CYAN

BR-04x08-H096 @ 24,24,259.2

### C-215 CYAN

BR-04x08-H096 @ 56,24,259.2

### C-216 CYAN

BR-04x08-H096 @ 88,24,259.2

### C-217 CYAN

BR-04x08-H096 @ 120,24,259.2

### C-218 CYAN

BR-04x08-H096 @ 152,24,259.2

### C-219 CYAN

BR-04x08-H096 @ 184,24,259.2

# C / STEP 31 OF 33

Placement diagram from canonical part bounds. IDs match native CAD, BOM, viewer and animation.

## PLAN VIEW / front at bottom / NEW parts in color

220 | 221 | 222 | 223 | 224 | 225

## nominal 240 / grid 8.00

## FRONT (-Y) / new parts enter from above (+Z)

# ADD 6 PART(S)

### C-220 CYAN

BR-02x08-H096 @ 32,24,268.8

### C-221 CYAN

BR-04x08-H096 @ 48,24,268.8

### C-222 CYAN

BR-04x08-H096 @ 80,24,268.8

### C-223 CYAN

BR-04x08-H096 @ 112,24,268.8

### C-224 CYAN

BR-04x08-H096 @ 144,24,268.8

### C-225 CYAN

BR-04x08-H096 @ 176,24,268.8

# C / STEP 32 OF 33

Placement diagram from canonical part bounds. IDs match native CAD, BOM, viewer and animation.

## PLAN VIEW / front at bottom / NEW parts in color

226 | 227 | 228

## nominal 240 / grid 8.00

## FRONT (-Y) / new parts enter from above (+Z)

# ADD 3 PART(S)

### C-226 MAGENTA

BR-04x06-H064 @ 80,40,278.4

### C-227 MAGENTA

BR-04x06-H064 @ 112,40,278.4

### C-228 MAGENTA

BR-02x06-H064 @ 144,40,278.4

# C / STEP 33 OF 33

Placement diagram from canonical part bounds. IDs match native CAD, BOM, viewer and animation.

## PLAN VIEW / front at bottom / NEW parts in color

## nominal 240 / grid 8.00

## FRONT (-Y) / new parts enter from above (+Z)

# ADD 0 PART(S)

# BASE3-03x14-T-08700f

Three orthographic views + underside from the actual solid. Exterior heights include studs / text.

## FRONT

23.80

11.40

## SIDE

111.80

TOP / PRINT ORIENTATION | BOTTOM / REAL CAVITIES

Kind: front_base

STL: BASE3-03x14-T-08700f.stl

STL units: mm / scale 100%

Grid: 3 x 14 @ 8.00

Body height: 9.60

Stud: dia 4.80 x 1.80 high

Tip lead-in: 0.25 high / radial

Female radial c: +0.04

Outer wall: 1.46

Tube bore: 3.20 (not accessory fit)

Roof ribs: 1.20; bridge gap <=6.80

Front row reserved (no stud/socket)

NP3 dovetail side allowance: 0.20

See front-interface.svg for sections

# BASE3-03x14-T-d96cba

Three orthographic views + underside from the actual solid. Exterior heights include studs / text.

## FRONT

23.80

11.40

## SIDE

111.80

TOP / PRINT ORIENTATION | BOTTOM / REAL CAVITIES

Kind: front_base

STL: BASE3-03x14-T-d96cba.stl

STL units: mm / scale 100%

Grid: 3 x 14 @ 8.00

Body height: 9.60

Stud: dia 4.80 x 1.80 high

Tip lead-in: 0.25 high / radial

Female radial c: +0.04

Outer wall: 1.46

Tube bore: 3.20 (not accessory fit)

Roof ribs: 1.20; bridge gap <=6.80

Front row reserved (no stud/socket)

NP3 dovetail side allowance: 0.20

See front-interface.svg for sections

# BASE3-06x14-T-26e6b0

Three orthographic views + underside from the actual solid. Exterior heights include studs / text.

## FRONT

47.80

11.40

## SIDE

111.80

TOP / PRINT ORIENTATION | BOTTOM / REAL CAVITIES

Kind: front_base

STL: BASE3-06x14-T-26e6b0.stl

STL units: mm / scale 100%

Grid: 6 x 14 @ 8.00

Body height: 9.60

Stud: dia 4.80 x 1.80 high

Tip lead-in: 0.25 high / radial

Female radial c: +0.04

Outer wall: 1.46

Tube bore: 3.20 (not accessory fit)

Roof ribs: 1.20; bridge gap <=6.80

Front row reserved (no stud/socket)

NP3 dovetail side allowance: 0.20

See front-interface.svg for sections

# BASE3-06x14-T-5258a8

Three orthographic views + underside from the actual solid. Exterior heights include studs / text.

## FRONT

47.80

11.40

## SIDE

111.80

TOP / PRINT ORIENTATION | BOTTOM / REAL CAVITIES

Kind: front_base

STL: BASE3-06x14-T-5258a8.stl

STL units: mm / scale 100%

Grid: 6 x 14 @ 8.00

Body height: 9.60

Stud: dia 4.80 x 1.80 high

Tip lead-in: 0.25 high / radial

Female radial c: +0.04

Outer wall: 1.46

Tube bore: 3.20 (not accessory fit)

Roof ribs: 1.20; bridge gap <=6.80

Front row reserved (no stud/socket)

NP3 dovetail side allowance: 0.20

See front-interface.svg for sections

# BASE3-06x14-T-72d551

Three orthographic views + underside from the actual solid. Exterior heights include studs / text.

## FRONT

47.80

11.40

## SIDE

111.80

TOP / PRINT ORIENTATION | BOTTOM / REAL CAVITIES

Kind: front_base

STL: BASE3-06x14-T-72d551.stl

STL units: mm / scale 100%

Grid: 6 x 14 @ 8.00

Body height: 9.60

Stud: dia 4.80 x 1.80 high

Tip lead-in: 0.25 high / radial

Female radial c: +0.04

Outer wall: 1.46

Tube bore: 3.20 (not accessory fit)

Roof ribs: 1.20; bridge gap <=6.80

Front row reserved (no stud/socket)

NP3 dovetail side allowance: 0.20

See front-interface.svg for sections

# BASE3-06x14-T-afd244

Three orthographic views + underside from the actual solid. Exterior heights include studs / text.

## FRONT

47.80

11.40

## SIDE

111.80

TOP / PRINT ORIENTATION | BOTTOM / REAL CAVITIES

Kind: front_base

STL: BASE3-06x14-T-afd244.stl

STL units: mm / scale 100%

Grid: 6 x 14 @ 8.00

Body height: 9.60

Stud: dia 4.80 x 1.80 high

Tip lead-in: 0.25 high / radial

Female radial c: +0.04

Outer wall: 1.46

Tube bore: 3.20 (not accessory fit)

Roof ribs: 1.20; bridge gap <=6.80

Front row reserved (no stud/socket)

NP3 dovetail side allowance: 0.20

See front-interface.svg for sections

# BASE3-06x14-T-f6d8b7

Three orthographic views + underside from the actual solid. Exterior heights include studs / text.

## FRONT

47.80

11.40

## SIDE

108.40

TOP / PRINT ORIENTATION | BOTTOM / REAL CAVITIES

Kind: front_base

STL: BASE3-06x14-T-f6d8b7.stl

STL units: mm / scale 100%

Grid: 6 x 14 @ 8.00

Body height: 9.60

Stud: dia 4.80 x 1.80 high

Tip lead-in: 0.25 high / radial

Female radial c: +0.04

Outer wall: 1.46

Tube bore: 3.20 (not accessory fit)

Roof ribs: 1.20; bridge gap <=6.80

Front row reserved (no stud/socket)

NP3 dovetail side allowance: 0.20

See front-interface.svg for sections
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

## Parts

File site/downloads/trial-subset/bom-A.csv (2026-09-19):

part | quantity | color | stage | stl | sha256 | width_mm | depth_mm | height_mm | orientation
BR-02x02-H096 | 2 | black | real-blocks | parts/BR-02x02-H096.stl | 16726dd1b4b1e1a44bc8c0871ab681cf12c200643be356c5f1903c0017395d30 | 15.8 | 15.8 | 11.4 | underside_on_bed_studs_up
BR-02x04-H096 | 2 | black | real-blocks | parts/BR-02x04-H096.stl | 31b61fbf103450546cda92dfe50bfc24393e776bbe62a45d24d6084cb0c7a269 | 15.8 | 31.8 | 11.4 | underside_on_bed_studs_up
NP3-KEEPER | 1 | black | keeper-base | parts/NP3-KEEPER.stl | b523f99637728aa9e51b4025ec778016f0c9d78f9959aa7823abb71ce691978f | 15.8 | 15.8 | 3.2 | flat_front_pad_and_socket_down
BASE3-03x08-T-48de52 | 2 | black | keeper-base | parts/BASE3-03x08-T-48de52.stl | 0196383cb2b4a181c563b625920c00703dcc6d2a900c0ac1e437584201eca493 | 23.8 | 63.8 | 11.4 | underside_on_bed_studs_up

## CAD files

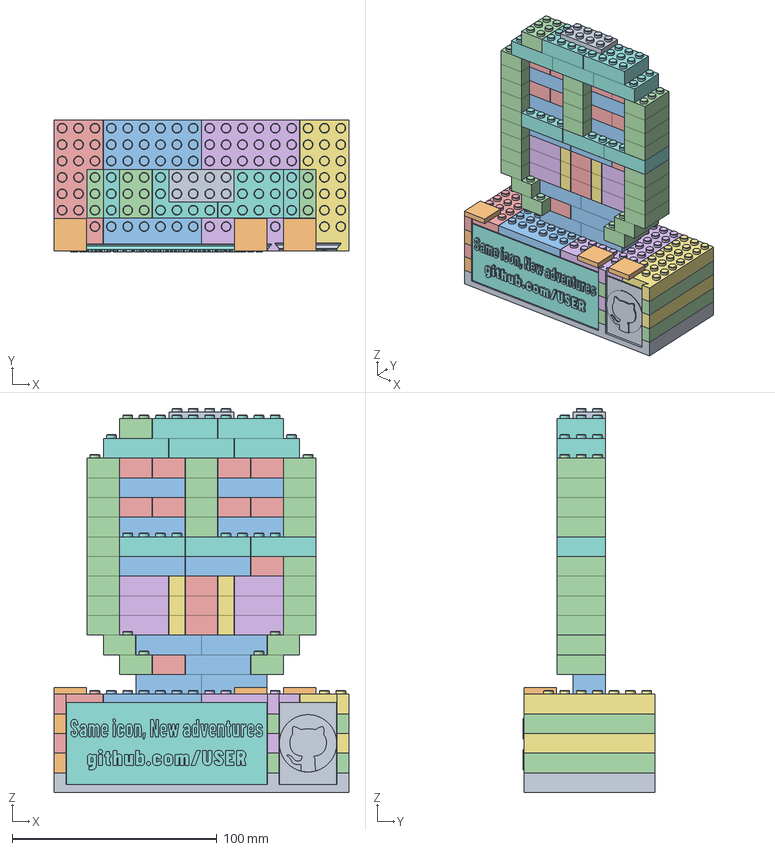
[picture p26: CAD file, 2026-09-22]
site/downloads/A/A.step
143.8 x 64.2 x 187.4 mm
A-001 | BASE3-18x08-B-a4853c | black
A-002 | BASE3-06x08-T-b8aa05 | black x 2
A-003 | BASE3-06x08-T-9cb610 | black x 4
A-004 | BASE3-06x08-T-7f51dc | black x 2
A-005 | BASE3-03x08-T-48de52 | black x 2
A-007 | BASE3-06x08-T-7532db | black x 2
A-008 | BASE3-03x08-T-80e081 | black x 2
A-016 | NP3-TEXT-A | black
A-017 | NP3-LOGO-A | black
A-018 | NP3-KEEPER | black x 3
A-021 | BR-04x02-H096 | magenta x 11
A-023 | BR-02x03-H096 | magenta x 26
A-024 | BR-02x02-H096 | black x 13
A-032 | BR-03x02-H096 | black x 6
A-033 | BR-01x02-H096 | green x 6
A-058 | BR-04x03-H096 | cyan x 8
A-091 | BR-04x02-H032 | magenta

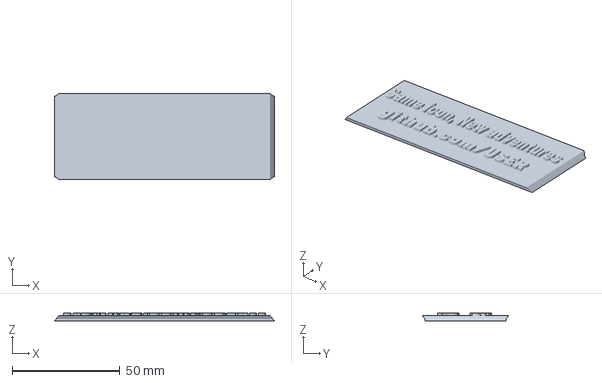
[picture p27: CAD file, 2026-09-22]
site/downloads/A/plates/A-black-to-white-z2p4-01.3mf
102.0 x 40.0 x 3.60 mm

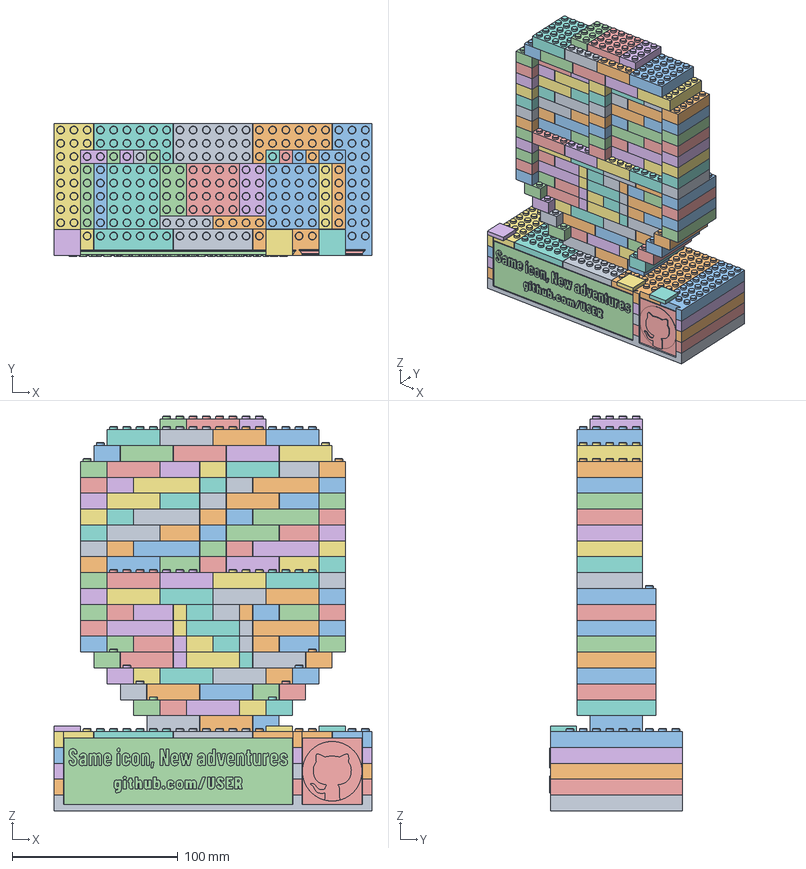
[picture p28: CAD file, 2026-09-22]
site/downloads/B/B.FCStd
191.8 x 80.2 x 238.6 mm
B-001 | BASE3-24x10-B-562406 | black
B-002 | BASE3-06x10-T-e1945a | black
B-003 | BASE3-06x10-T-838259 | black
B-004 | BASE3-06x10-T-3f87ac | black
B-005 | BASE3-06x10-T-6e100f | black
B-006 | BASE3-03x10-T-aa77a9 | black
B-007 | BASE3-06x10-T-838259 | black
B-008 | BASE3-06x10-T-838259 | black
B-009 | BASE3-06x10-T-6159e6 | black
B-010 | BASE3-03x10-T-d79875 | black
B-011 | BASE3-06x10-T-e1945a | black
B-012 | BASE3-06x10-T-838259 | black
B-013 | BASE3-06x10-T-3f87ac | black
B-014 | BASE3-06x10-T-6e100f | black
B-015 | BASE3-03x10-T-aa77a9 | black
B-016 | BASE3-06x10-T-838259 | black
B-017 | BASE3-06x10-T-838259 | black
B-018 | BASE3-06x10-T-6159e6 | black
B-019 | BASE3-03x10-T-d79875 | black
B-020 | NP3-TEXT-B | black
B-021 | NP3-LOGO-B | black
B-022 | NP3-KEEPER | black
B-023 | NP3-KEEPER | black
B-024 | NP3-KEEPER | black
B-025 | BR-04x04-H096 | magenta
B-026 | BR-04x04-H096 | magenta
B-027 | BR-02x04-H096 | magenta
B-028 | BR-02x06-H096 | magenta
B-029 | BR-02x04-H096 | black
B-030 | BR-04x04-H096 | black
B-031 | BR-02x04-H096 | black
B-032 | BR-02x06-H096 | magenta
B-033 | BR-02x06-H096 | magenta
B-034 | BR-04x04-H096 | black
B-035 | BR-04x04-H096 | black
B-036 | BR-02x04-H096 | black
B-037 | BR-02x06-H096 | magenta
B-038 | BR-02x06-H096 | magenta
B-039 | BR-02x04-H096 | black
B-040 | BR-04x04-H096 | black
B-041 | BR-04x04-H096 | black
B-042 | BR-02x04-H096 | black
B-043 | BR-02x06-H096 | magenta
B-044 | BR-02x06-H096 | magenta
B-045 | BR-04x04-H096 | black
B-046 | BR-01x04-H096 | green
B-047 | BR-04x04-H096 | black
B-048 | BR-01x04-H096 | green
B-049 | BR-04x04-H096 | black
B-050 | BR-02x06-H096 | magenta
B-051 | BR-02x06-H096 | magenta
B-052 | BR-02x04-H096 | black
B-053 | BR-03x04-H096 | black
B-054 | BR-01x04-H096 | green
B-055 | BR-02x04-H096 | black
B-056 | BR-02x04-H096 | black
B-057 | BR-01x04-H096 | green
B-058 | BR-02x04-H096 | black
B-059 | BR-03x04-H096 | black
B-060 | BR-02x06-H096 | magenta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

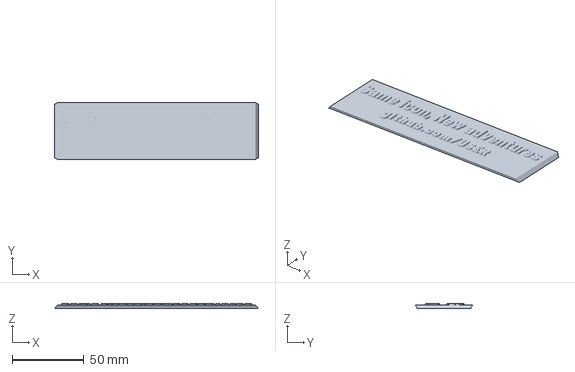
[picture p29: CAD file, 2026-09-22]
site/downloads/B/plates/B-black-to-white-z2p4-01.3mf
142.0 x 40.0 x 3.60 mm

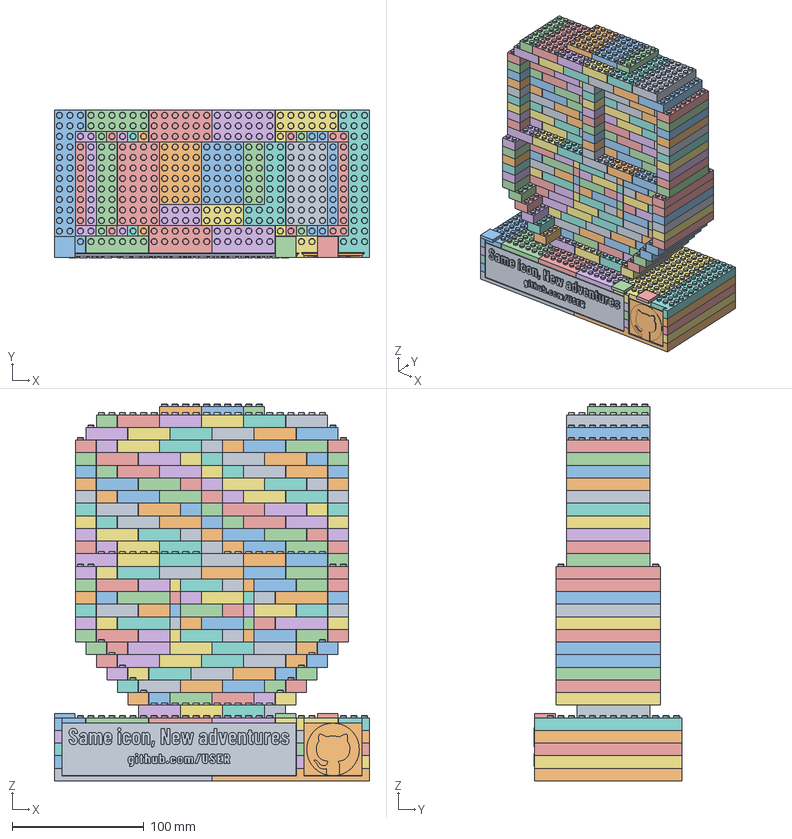
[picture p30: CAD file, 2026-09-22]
site/downloads/C/C.FCStd
239.8 x 112.2 x 286.6 mm
C-001 | BASE3-15x14-B-2f9fc1 | black
C-002 | BASE3-15x14-B-65597c | black
C-003 | BASE3-06x14-T-72d551 | black
C-004 | BASE3-06x14-T-f6d8b7 | black
C-005 | BASE3-06x14-T-f6d8b7 | black
C-006 | BASE3-06x14-T-afd244 | black
C-007 | BASE3-06x14-T-26e6b0 | black
C-008 | BASE3-03x14-T-08700f | black
C-009 | BASE3-06x14-T-f6d8b7 | black
C-010 | BASE3-06x14-T-f6d8b7 | black
C-011 | BASE3-06x14-T-f6d8b7 | black
C-012 | BASE3-06x14-T-5258a8 | black
C-013 | BASE3-03x14-T-d96cba | black
C-014 | BASE3-06x14-T-72d551 | black
C-015 | BASE3-06x14-T-f6d8b7 | black
C-016 | BASE3-06x14-T-f6d8b7 | black
C-017 | BASE3-06x14-T-afd244 | black
C-018 | BASE3-06x14-T-26e6b0 | black
C-019 | BASE3-03x14-T-08700f | black
C-020 | BASE3-06x14-T-f6d8b7 | black
C-021 | BASE3-06x14-T-f6d8b7 | black
C-022 | BASE3-06x14-T-f6d8b7 | black
C-023 | BASE3-06x14-T-5258a8 | black
C-024 | BASE3-03x14-T-d96cba | black
C-025 | NP3-TEXT-C | black
C-026 | NP3-LOGO-C | black
C-027 | NP3-KEEPER | black
C-028 | NP3-KEEPER | black
C-029 | NP3-KEEPER | black
C-030 | BR-04x07-H096 | magenta
C-031 | BR-04x07-H096 | magenta
C-032 | BR-04x07-H096 | magenta
C-033 | BR-02x07-H096 | magenta
C-034 | BR-02x10-H096 | magenta
C-035 | BR-02x06-H096 | black
C-036 | BR-04x06-H096 | black
C-037 | BR-04x06-H096 | black
C-038 | BR-02x06-H096 | black
C-039 | BR-02x10-H096 | magenta
C-040 | BR-02x10-H096 | magenta
C-041 | BR-04x06-H096 | black
C-042 | BR-04x06-H096 | black
C-043 | BR-04x06-H096 | black
C-044 | BR-02x06-H096 | black
C-045 | BR-02x10-H096 | magenta
C-046 | BR-02x10-H096 | magenta
C-047 | BR-02x06-H096 | black
C-048 | BR-04x06-H096 | black
C-049 | BR-04x06-H096 | black
C-050 | BR-04x06-H096 | black
C-051 | BR-02x06-H096 | black
C-052 | BR-02x10-H096 | magenta
C-053 | BR-02x10-H096 | magenta
C-054 | BR-04x06-H096 | black
C-055 | BR-04x06-H096 | black
C-056 | BR-04x06-H096 | black
C-057 | BR-04x06-H096 | black
C-058 | BR-02x06-H096 | black
C-059 | BR-02x10-H096 | magenta
C-060 | BR-02x10-H096 | magenta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

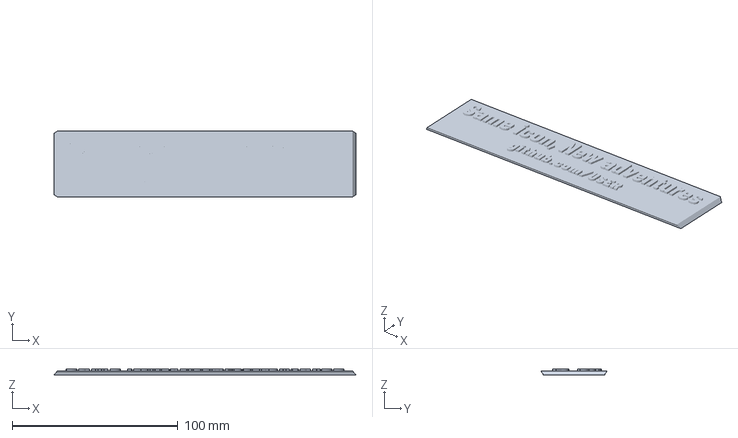
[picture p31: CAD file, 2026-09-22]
site/downloads/C/plates/C-black-to-white-z2p4-01.3mf
182.0 x 40.0 x 3.60 mm

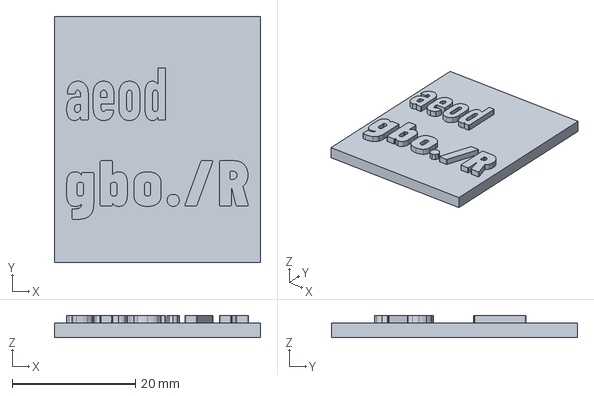
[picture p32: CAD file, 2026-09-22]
site/downloads/lettering-coupons/GLYPH-A.FCStd
33.5 x 40.0 x 3.60 mm

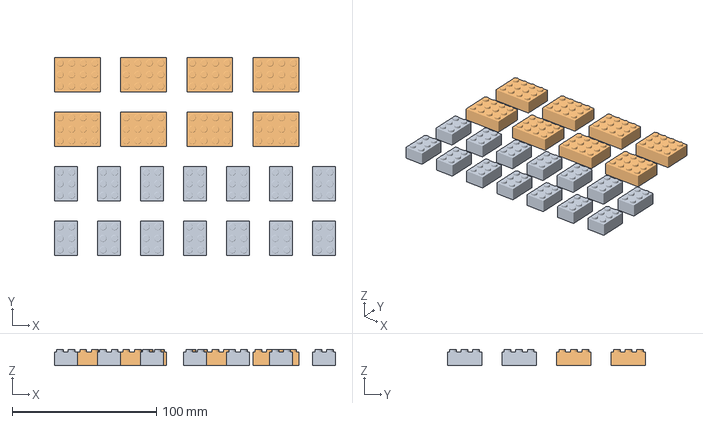
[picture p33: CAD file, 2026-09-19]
site/downloads/A/plates/A-cyan-01.3mf
194.6 x 137.2 x 11.4 mm
BR-02x03-H096 x 14
BR-04x03-H096 x 8

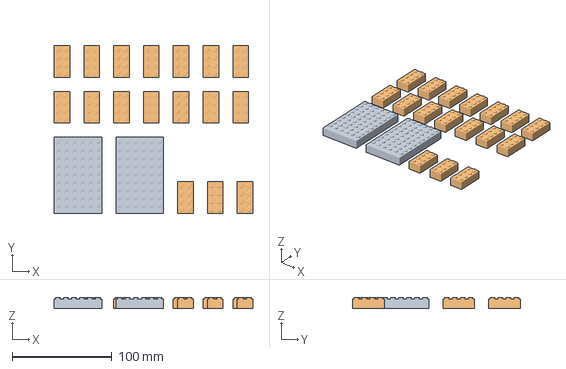
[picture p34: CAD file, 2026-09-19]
site/downloads/B/plates/B-black-04.3mf
199.0 x 168.0 x 11.4 mm
BASE3-06x10-T-838259 x 2
BR-02x04-H096 x 17

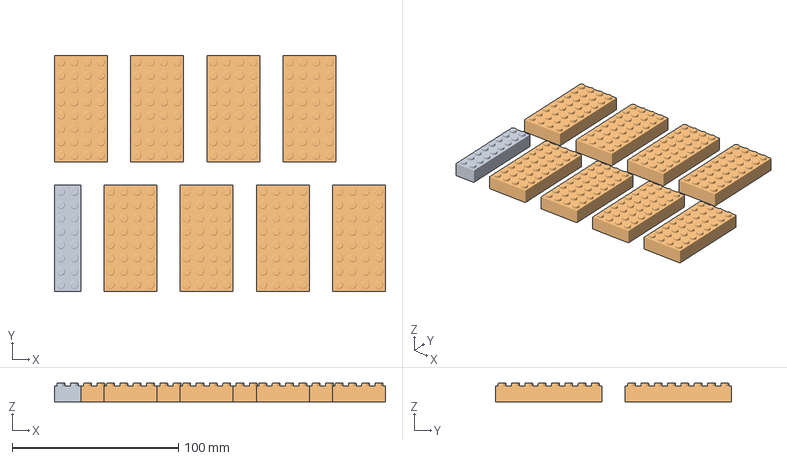
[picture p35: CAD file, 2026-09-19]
site/downloads/C/plates/C-cyan-03.3mf
199.0 x 141.6 x 11.4 mm
BR-02x08-H096
BR-04x08-H096 x 8

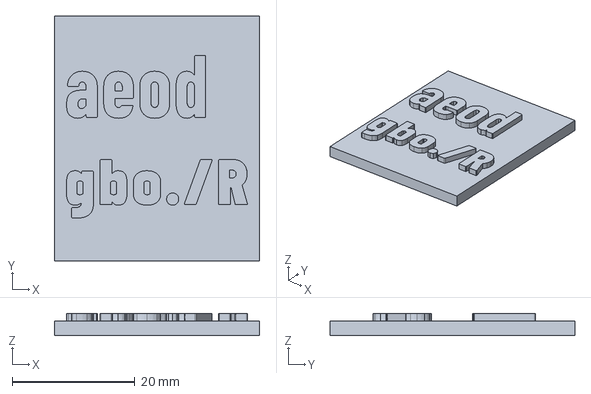
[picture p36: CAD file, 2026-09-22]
site/downloads/lettering-coupons/GLYPH-B.FCStd
33.5 x 40.0 x 3.60 mm

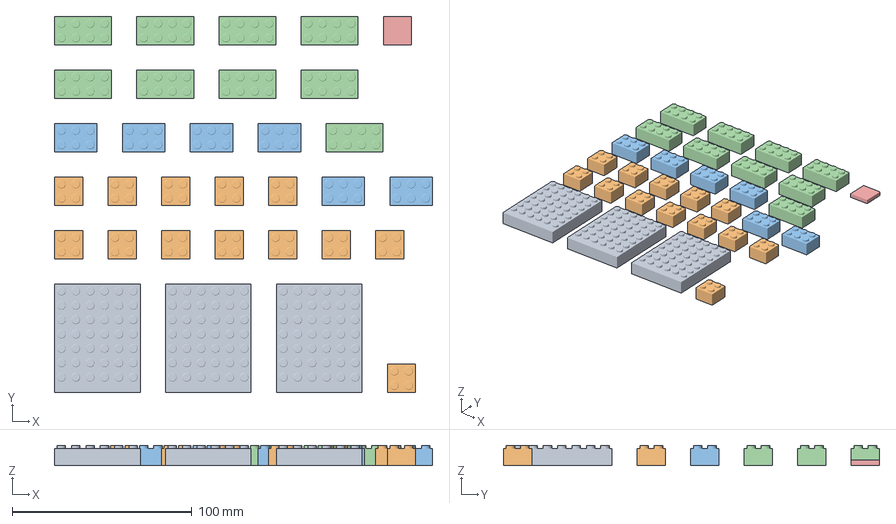
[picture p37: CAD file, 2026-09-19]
site/downloads/A/plates/A-black-03.3mf
210.6 x 209.4 x 11.4 mm
BASE3-06x08-T-9cb610 x 3
BR-02x02-H096 x 13
BR-03x02-H096 x 6
BR-04x02-H096 x 9
NP3-KEEPER

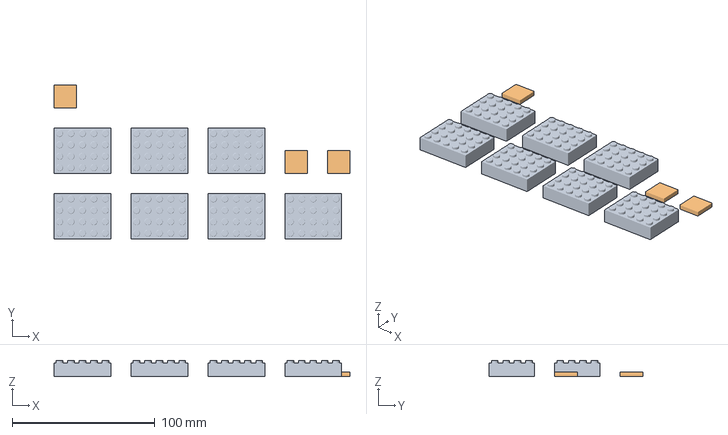
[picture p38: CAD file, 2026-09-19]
site/downloads/B/plates/B-black-07.3mf
207.0 x 107.4 x 11.4 mm
BR-05x04-H096 x 7
NP3-KEEPER x 3

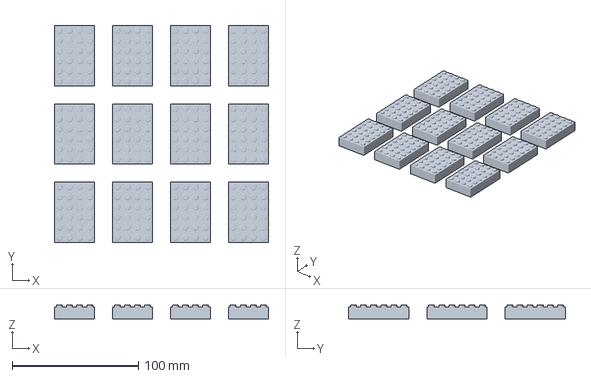
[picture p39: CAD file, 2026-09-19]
site/downloads/C/plates/C-black-11.3mf
169.2 x 171.4 x 11.4 mm
BR-04x06-H096 x 12

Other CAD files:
site/downloads/parts/NP3-TEXT-A.stl
site/downloads/parts/NP3-TEXT-C.stl
site/downloads/lettering-coupons/GLYPH-C.FCStd
site/downloads/parts/NP3-TEXT-B.stl
site/downloads/A/A.FCStd
site/downloads/A/A.blend
site/downloads/A/plates/A-black-01.3mf
site/downloads/A/plates/A-black-02.3mf
site/downloads/A/plates/A-black-04.3mf
site/downloads/A/plates/A-black-to-white-z2p8-01.3mf
site/downloads/A/plates/A-green-01.3mf
site/downloads/A/plates/A-magenta-01.3mf
site/downloads/B/plates/B-black-01.3mf
site/downloads/B/plates/B-black-02.3mf
site/downloads/B/plates/B-black-03.3mf
site/downloads/B/plates/B-black-05.3mf
site/downloads/B/plates/B-black-06.3mf
site/downloads/B/plates/B-black-to-white-z2p8-01.3mf
site/downloads/B/plates/B-cyan-01.3mf
site/downloads/B/plates/B-cyan-02.3mf
site/downloads/B/plates/B-green-01.3mf
site/downloads/B/plates/B-magenta-01.3mf
site/downloads/B/plates/B-magenta-02.3mf
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

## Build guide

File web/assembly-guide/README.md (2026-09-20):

# Shared print-to-place guide

This UI renders actual STL geometry. It does not generate or change mechanical parts.
`scripts/build_assembly_guide.py` is a root-independent input adapter; the separate
`scripts/build_public_assembly_guides.py` wrapper enforces this repository's generic public policy.
Do not use the public wrapper for private data.

## Inputs and output

```bash
npm ci
npm run build:assembly-guide
.venv/bin/python scripts/build_assembly_guide.py \
  --catalog design/catalog.json \
  --assembly site/downloads/B/assembly.json \
  --plates site/downloads/B/plates/manifest.json \
  --mesh-root site/downloads \
  --plates-root site/downloads/B/plates \
  --runtime build/assembly-guide/runtime.js \
  --template-dir web/assembly-guide \
  --output build/assembly-guide/index.html \
  --standalone
```

Requires Python + NumPy. Bundling requires the locked Three.js 0.180.0 and esbuild 0.25.10.
For reuse elsewhere, copy `viewer.js`, `model.js`, `template.html`, `style.css`, both generic builder/bundler
scripts and the build-tool manifest/lockfile or the already-built runtime. The
`index.html` under this source folder is only the public A/B/C landing page, not the viewer template.
Retain the Three.js MIT license, also embedded verbatim in the runtime banner.

The adapter reads:

- Catalog: `units: "mm"`, `revision`, `parts` keyed by ID, `colors` keyed by color, `models`.
  Each used part has `id`, `kind`, relative `stl`, `sha256`, measured `bounds`, `orientation`;
  relief parts also have `optional_color_change_z` and `letter_color`.
- Assembly: `model`, `units`, `bounds`, `placements`, `steps`, `bom`.
  Placements have `id`, `part`, `color`, `position` in mm, XYZ `rotation` in degrees,
  `step`, `role`, and optional `course`/`module`. These and the steps must exactly match the catalog model.
- Plate manifest: `units`, `sliced: false`, `printer_settings_validated: false`, `bed_nominal`,
  `plates` with `file`, `color`, and ordered `items: [{part, position, brim_box}]`.
  Optional finish data is `finish_color`, `manual_change_after_z_mm`.
- The actual binary STL files and generic 3MF files. The builder checks hashes/bounds,
  canonical six-decimal triangles, 3MF object names, occurrence order, print transforms and
  all part+color quantities. A changed input must be reconciled explicitly; there is no mismatch-ignore flag.
- The catalog model's NP3 `presentation` includes the module release/lift dimensions.

`--title` accepts escaped plain text, not HTML. No other string is interpreted as markup.
The output is the requested HTML plus a sibling `<stem>.mapping.json`.
The standalone HTML embeds CSS, the classic IIFE runtime and gzip/base64 actual STL bytes.
It needs no server or other files when opened using `file://`. There is no fetch, CDN,
telemetry or API. CSP explicitly forbids `connect-src`; do not weaken it to make tests use `eval`.
The non-standalone mode writes a shared `runtime.js` and `style.css` beside the HTML and
works under both HTTP and file URLs.

No source paths or display strings are copied from the input catalog into output metadata.
Private glyphs are nevertheless present **as geometry** when private STLs are supplied.
Such output must stay in the explicitly authorized private destination.

## Stable mapping schema, version 1

`script#assembly-guide-data` contains `{mapping, meshes}`.
The JSON sidecar contains only `mapping`, with:

- `model`, `guide_revision`, `geometry_revision`, `units`, `part_count`, `bounds`, `colors`.
- `parts[id]`: `id`, `kind`, `bounds`, `dimensions`, `sha256`, `orientation`, optional finish data.
- `plates[]`: `file`, `color`, actual `sha256`, `slots`.
- `slots[]`: stable `id` (`filename.3mf#1`), one-based `number`, `part`, `group`,
  `print_position`, `print_rotation`, `brim_box`, `suggested_placement`, `candidate_placements`.
- `groups["part|color"]`: `part`, `color`, `quantity`, all `placements`, all
  `sources: [{plate, slot, slot_id, suggested_placement}]`.
- `placements[]`: original pose/step/role fields plus zero-based `index`, `group`, `suggested_source`.
- `steps[]`: original `number/title/instances`, plus zero-based `first_index`, exclusive
  `end_index`, and `available_source_files`.
- `first_source`, `base_source_files`, and the display-only `motion` distances.
- `sliced: false`, `physical_fit_tested: false`, `slot_numbers_are_physical_markings: false`.

The suggested source is a deterministic bookkeeping example, not an identity printed on a
physical copy. Always present all same-part/same-color sources and destinations.
For B, black-02 slot 3 is uniquely B-001. All five base courses need selected parts from
black-01 through black-04, including two copies of `BASE3-06x10-T-838259` from black-04.

## Browser contract

`#guide-app[data-ready="true"]` signals readiness; `"error"` and `#guide-error` signal a failure.
Controls are:

- `#plate-select`, `#slot-list [data-slot="filename.3mf#1"]`, `#plate-isolate`.
- `.view-tools[data-scene="plate"|"assembly"] button[data-view="iso"|"front"|"side"|"top"|"back"|"bottom"]`.
- `#step-select`, `#assembly-cursor`, `#motion-progress`, `#start-first`, `#restart`.
- `#previous`, `#next`, `#play`, `#replay-step`, `#speed`, `#ghost`.
- `#source-list`, `#target-list .target-row`, `#selected-part`, `#capture-caption`.
- `#plate-viewport`, `#assembly-viewport`, and `#capture-card` are screenshot regions.

Use the controls for acceptance. `window.BrickAssemblyGuide.state()` is a read-only snapshot
with `cursor`, `empty`, `progress`, `playing`, `mode`, `step`, `activeId`, `selectedSlot`,
`selectedPlate`, `selectedSlotNumber`, `selectedPlacement`, `completedIds`, `candidateIds`,
`sourceSlots`, `assemblyPoses` and `renderError`. `mapping()` exposes the correspondence data.
`completedIds` and `cursor` are the confirmed prefix. `seatedCount`, `seatedIds` and
`activeSeated` also include the current piece when motion reaches 100%, so the visible
count and caption match its seated pose without silently advancing to the next piece.

An empty desk is distinct from a preview of the first hovering piece:
initial load, `restart()` and `setStep(0)` render no assembly meshes, return `step: 0`,
`activeId: null` and zero completed pieces. `setCursor(0)` previews the first piece.
`setStep(n)` starts immediately before that step; it never marks real-world work as complete.
The remaining capture/control API calls the same UI functions:
`setCursor(n)`, `setProgress(0..1)`, `selectSlot(id)`, `selectPlacement(id)`,
`setView(scene, direction)`, `play()`, `pause()`. A progress of 1 shows the final pose;
advancing to the next piece is a separate action.
Animation uses elapsed foreground time rather than assuming a minimum frame rate.
Cached STL bounds frame the view; only the active mesh pose changes during a frame.
Moving the document into the background pauses playback instead of silently skipping pieces.

For automation under the CSP, use locator assertions and protocol `page.evaluate`.
Playwright's string `wait_for_function` internally uses page `eval`, which the CSP forbids.
Do not add `unsafe-eval` merely for a test.

```bash
.venv/bin/python -m unittest discover -s tests -p test_assembly_guide.py -v
node tests/assembly_guide_model.mjs
.venv/bin/python tests/assembly_guide_browser.py \
  --entry build/assembly-guide/index.html --output build/guide-check
```

The last test defaults to the generic B contract. A separate private integration must
assert its own supplied input hashes without sending those files to this repository.
`--capture-media` records the same actual-mesh viewer's first seven B steps and encodes
GIF/H.264 MP4 with ffmpeg. It is not a Blender render or a physical fit test.

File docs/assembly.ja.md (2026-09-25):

# 印刷した部品を、どこから・どう組む？

**[A / B / C の対話3Dガイドを開く](../site/assembly-guide/index.html)**

**個人向けB（本人公開許可済み）：**
[説明・作り方](https://ktanino10.github.io/copilot-brick-gift-b/) ／
[3D工程](https://ktanino10.github.io/copilot-brick-gift-b/guide/index.html) ／
[写真記録](https://ktanino10.github.io/copilot-brick-gift-b/docs/BUILD-LOG.html)。
別サイトへの案内です。この汎用版の `USER` 表記・匿名化写真・印刷データはそのままです。

**[実物写真の制作記録：個人向けBの完成報告（09/25）](build-log.ja.md#build-2026-09-25)**。
台座から顔下部、ゴーグルの上枠と紫の頭頂まで揃う過程を記録しました。
実写真と以下の説明用3DCGを区別し、このガイドのmagenta／green配色や印刷データは変更していません。

印刷するファイルの順番と、組み立てる順番は違います。
色別プレートは効率よく並べた**印刷用の配置**で、ファイル末尾の `01` は台座の1段目という意味ではありません。
このガイドは、実際に配布しているSTL・3MF配置・組立番号を結び、1個ずつ取り出して載せるためのものです。

| 印刷した案 | 3Dで仕分け・組立 | オフライン版 | 最初に取り出す部品 |
| --- | --- | --- | --- |
| A | [Aの3Dガイド](../site/assembly-guide/A.html) | [A ZIP](../site/assembly-guide/A-offline.zip) | `A-black-02.3mf` のslot 3 → `A-001` |
| B | [Bの3Dガイド](../site/assembly-guide/B.html) | [B ZIP](../site/assembly-guide/B-offline.zip) | `B-black-02.3mf` のslot 3 → `B-001` |
| C | [Cの3Dガイド](../site/assembly-guide/C.html) | [C ZIP](../site/assembly-guide/C-offline.zip) | `C-black-04.3mf` のslot 2 → `C-001` |

オフラインZIPを展開して `index.html` をダブルクリックします。ローカルサーバー、CDN、ログイン、ネット接続は不要です。
Chrome / Edge / Firefox / Safariの現行版を使ってください。
オフラインZIPは閲覧用です。印刷STL・3MFは[別PCでの印刷手順](build.ja.md#print-another-pc)から保存します。
別の案を混ぜないでください。公開の文字は実形状でも `USER` の汎用表示です。

## Bを印刷した方へ：最初の1段

`B-black-02.3mf` には3個あります。大きな1枚、**slot 3 / `BASE3-24x10-B-562406`** が
唯一の `B-001` です。スタッドを上、前面の取付け溝を手前へ置きます。
下図の左が元の印刷配置、右が組立側です。番号は案内用で、実物に刻印されていません。

B-black-02のslot 3がB-001。実STLの印刷配置と組立位置

**`B-black-01` を刷り終えただけでは、1段目はありません。**
その中には2〜5段目に使う溝・端の部品が入っています。違う形なのに、無理に1段目のように並べないでください。

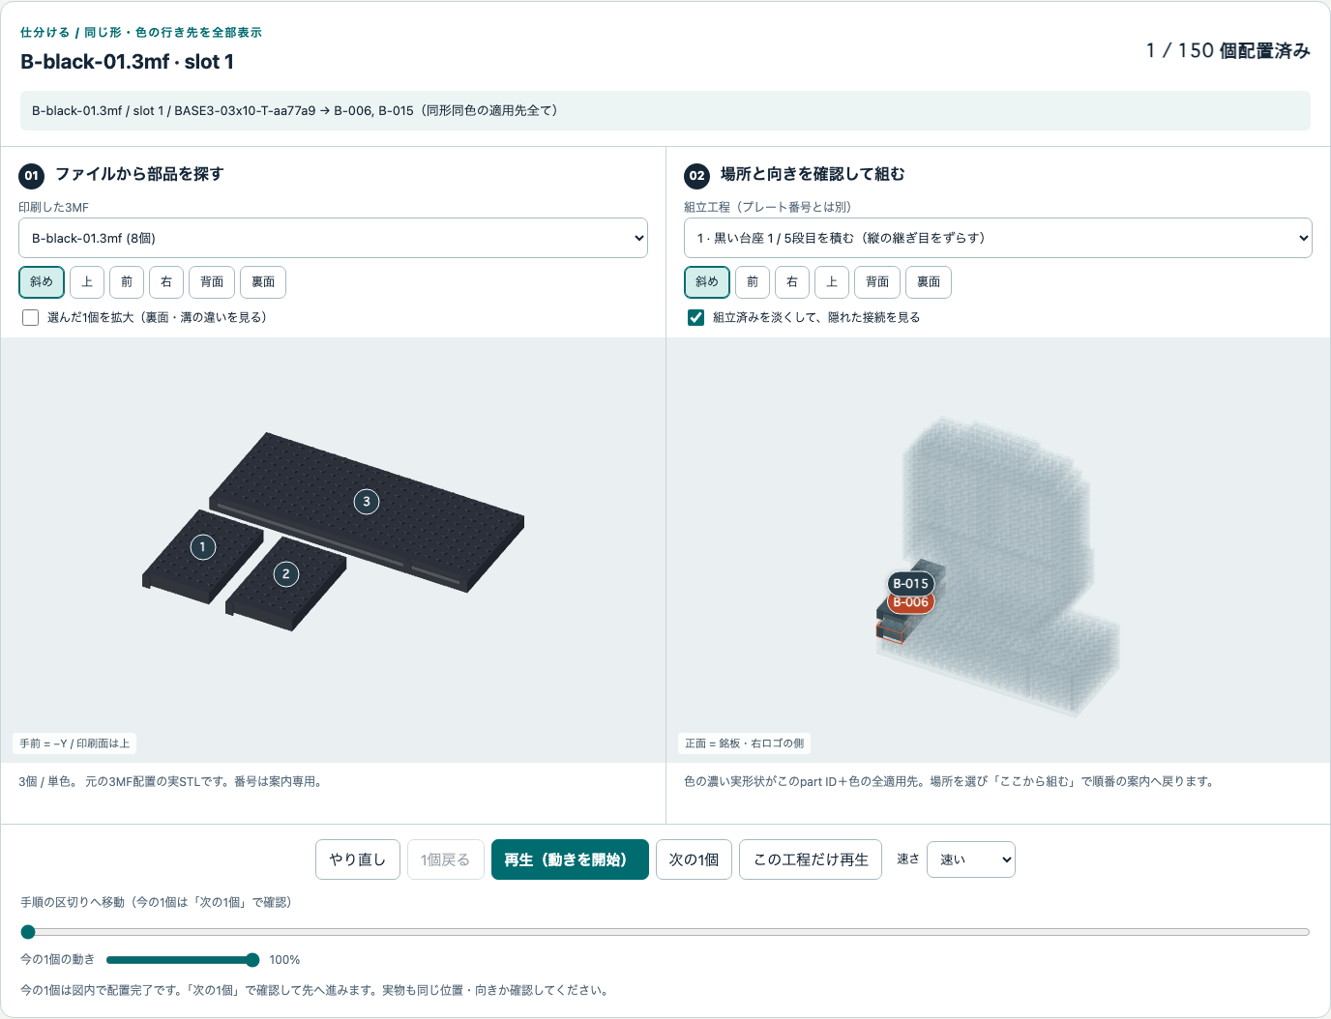
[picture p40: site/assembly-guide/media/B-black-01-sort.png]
B-black-01の実部品をslot番号と組立候補へ結ぶ3D仕分け見本


台座の全5段を揃えるには、Bの黒 **01・02・03・04** の対象部品が必要です。
同形同色の `BASE3-06x10-T-838259` は6個あり、黒03に4個、黒04に2個入っています。
黒04の2個を忘れないでください。便宜上は5段目の `B-016` / `B-017` に割り当てていますが、
同じID・同じ色の6個の間では交換できます。

## 3Dガイドの使い方

1. **刷ったファイルを選ぶ。** 左の「印刷した3MF」で、保存したファイル名と一致するものを選びます。
   実プレートの形・位置とslot番号が出ます。Bambu Studioで再配置した場合、この番号はその新しい表示順ではありません。
2. **実物を見比べる。** 図内の番号か、下のslotボタンで選びます。part ID・寸法・必要個数を確認します。
   「選んだ1個を拡大」→「裏面」「背面」を使い、下面空洞・溝・端の形を確認します。
   同じ外形寸法でも溝の異なる台座部品があります。寸法だけで同一品と判断しません。
3. **使える場所を全部見る。** 右側では同じpart ID＋同じ色の全候補が濃く表示されます。
   「使える組立場所」から番号を選ぶと位置が分かり、「ここから組む」でその直前まで組み上がった状態へ移れます。
   別の場所から開始する場合は、前の工程が実物でも揃っていることを確認してください。
4. **空の机から順番に。** 「やり直し」または工程0は空の状態です。「最初の1個」から、
   「次の1個」「1個戻る」、再生／一時停止、「この工程だけ再生」で進みます。
   動いている部品の **3MF名・slot・part ID・組立番号・工程** が、常に図の上に表示されます。
5. **接続を見たい時は淡く。** 「組立済みを淡くする」を入れると隠れた位置が見えます。
   色や完成状態を確認する時は外します。前・右・上のボタン、ドラッグ、ズームでも見られます。

「便宜割当」は仕分けのために安定させた例です。同じ形・同じ色の部品に固有のシリアル番号はありません。
その1個だけの行き先とは断定せず、**全ての取り出し元と全ての適用先**を並べています。
異なるpart ID・異なる色を混ぜたり、必要数を減らしたりしてよいという意味ではありません。

## 台座5段 → 銘板と右ロゴ → keeper

下の短いアニメは、Bの最初の24個（工程1〜7）を実STLから表示しています。
各フレームにファイル名・slot・部品・組立番号を付けています。説明用3DCGで、Blenderの再レンダーや物理試験ではありません。

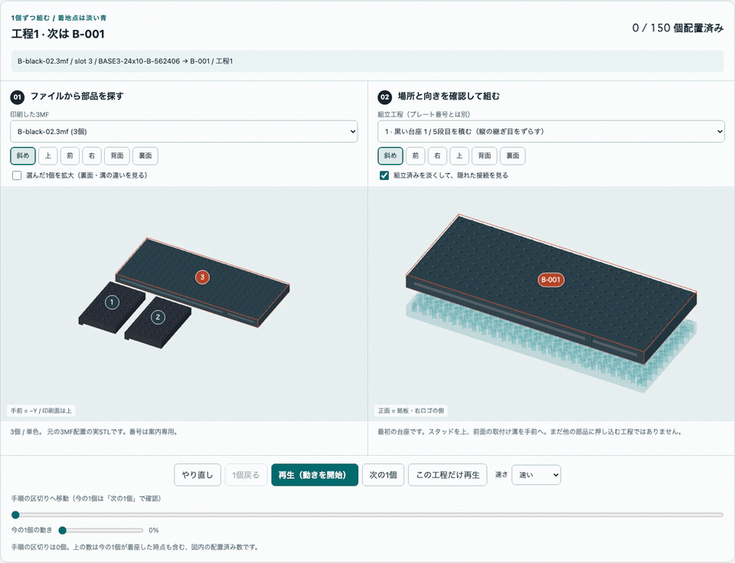
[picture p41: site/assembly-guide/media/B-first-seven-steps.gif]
Bの台座5段、前面2部品、3個のkeeperを順に載せる実STLアニメ


[一時停止できるMP4を保存](../site/assembly-guide/media/B-first-seven-steps.mp4)。
細かい動きは[対話3Dガイド](../site/assembly-guide/B.html)の工程6・7でゆっくり再生してください。

銘板と右ロゴは印刷時には平らです。表面を正面へ90°起こし、**keeperを付ける前に、溝の上から**差し込みます。
前から押し込む組み方ではありません。両方が着座してから、銘板用2個・ロゴ用1個のkeeperを載せます。
その後、顔の1段目から頭頂までを同じガイドで進めます。Bは全150個で、試験片は別です。

取り外しは逆の順です。keeperを上へ6 mm、前へ32 mm以上離して脇へ置き、
対象モジュールを45 mm以上上抜きしてから手前へ。接着剤は不要です。
これらは設計上の案内寸法であり、実物で強く引いてよいという意味ではありません。

## 印刷・実物確認の境界は変わりません

**NOT_SLICED。実物の嵌合、keeper保持、強度、転倒は未試験です。**
先にFIT、NP3-FIT、[7個の少量試作](trial.ja.md)。7個の成功は完成品全体の保持合格ではありません。
穴の閉塞・白化・つかみにくさ・着座不良・強い力が必要なら、全数印刷と組立を止めます。
無理押し、打撃、穴を全て削って合わせることを完成キットの前提にしません。

黒・シアン・マゼンタ・緑は単色。文字と右ロゴは黒地一体レリーフなので、白い独立小片ではありません。
黒支持体の境界は文字2.4 mm、ロゴ2.8 mm。実レイヤープレビューで、最初の白い経路の直前にPauseを入れます。
汎用3MFにPause、実P1Sプロファイル、G-codeは入っていません。

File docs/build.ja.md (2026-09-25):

# 作り方 — まず小さく試してから、本体へ

これは成人向けの屋内用卓上オブジェです。電子部品、モーター、電池、配線、接着剤は使いません。
**デジタル設計は用意されていますが、実物の嵌合・保持力・耐久性・転倒しにくさは未試験です。**
市販LEGOへの互換保証、玩具の安全認証、Bambu Labによる認定を意味しません。

**個人向けB（本人公開許可済み）：**
[説明・作り方](https://ktanino10.github.io/copilot-brick-gift-b/) ／
[3D工程](https://ktanino10.github.io/copilot-brick-gift-b/guide/index.html) ／
[写真記録](https://ktanino10.github.io/copilot-brick-gift-b/docs/BUILD-LOG.html)。
別サイトへの案内です。この汎用版の `USER` 表記・匿名化写真・印刷データはそのままです。

**完成報告：[個人向けBのゴーグル・頭頂まで揃いました（2026-09-25）](build-log.ja.md#build-2026-09-25)**。
本人の「これで完成ですね」と完成写真を追記しました。9/23・9/24の途中記録も残しています。
実制作の紫・黄は設計配色と区別し、測定・版照合の範囲は制作ログにまとめています。

**2026-09-19の試作手順追記：** 別の小型試験で「扱いにくい・穴が塞がる」という失敗が報告されています。
原因や補正値は未確定で、この模型の成功例ではありません。
まず[7個の現行実部品を段階的に試す手順](trial.ja.md)へ進み、入口・屋根のレイヤープレビューと手での着脱を確認してください。
**閉塞・つかみにくさ・着座不良があれば全数印刷を止めます。** 既存形状・8 mmピッチ・承認済み外観は変更していません。

**印刷を始めた方へ：[刷ったファイルから組立位置を探す3Dガイド](assembly.ja.md)**。
印刷順は組立順ではありません。Bの1段目は `B-black-02.3mf` のslot 3 → `B-001` です。
実プレートの番号・溝の拡大・全ての適用先を見て、空の机から1個ずつ再生できます。

## 別PCで、色別に印刷する

**手順更新：`separate-color-2026-09-19`／文字改訂2026-09-22。対象は公開の汎用版 `5.0-legible-plaques` です。**
A/B/Cのどれを印刷するかは、ここで**1案だけ選んでください**。サイトで最初にBが表示されても、Bを選択済みという意味ではありません。
公開の銘板は`USER`という短い仮表示です。実プロフィールへのリンクではありません。個人宛の銘板ファイルをこの公開セットへ混ぜません。
個人ファイルの転送・一時公開は別に判断する事項です。削除後も履歴・cache・第三者コピーに残る可能性があり、
この手順のために個人データを公開し直す必要はありません。

### 1案のファイルを、別PCへダウンロード

別PCのブラウザで[公開サイト](https://ktanino10.github.io/copilot-brick-display/?rev=5.0-legible-plaques)を開き、
選んだ行のファイルを保存します。まず試験片だけでよく、本体の全ファイルを印刷し始める必要はありません。

| 案 | 完成形を確認 | 印刷STLと案内 | 色別の配置データ | 色・個数 | 寸法・組立手順 |
| --- | --- | --- | --- | --- | --- |
| A | [Aを見る](../site/index.html?model=A) | [A/print-kit.zip](../site/downloads/A/print-kit.zip) | [A/plates.zip](../site/downloads/A/plates.zip) | [A/bom.csv](../site/downloads/A/bom.csv) | [A/drawings.pdf](../site/downloads/A/drawings.pdf) |
| B | [Bを見る](../site/index.html?model=B) | [B/print-kit.zip](../site/downloads/B/print-kit.zip) | [B/plates.zip](../site/downloads/B/plates.zip) | [B/bom.csv](../site/downloads/B/bom.csv) | [B/drawings.pdf](../site/downloads/B/drawings.pdf) |
| C | [Cを見る](../site/index.html?model=C) | [C/print-kit.zip](../site/downloads/C/print-kit.zip) | [C/plates.zip](../site/downloads/C/plates.zip) | [C/bom.csv](../site/downloads/C/bom.csv) | [C/drawings.pdf](../site/downloads/C/drawings.pdf) |

共通の最初の試験には[fit-coupons.zip](../site/downloads/fit-coupons.zip)、
次の実部品には[trial-subset.zip](../site/downloads/trial-subset.zip)を使います。
7個の試作は完成品の合格試験ではありません。

ZIPを保存したら、エクスプローラー／Finder等で**展開**し、案名とrevisionが分かるフォルダへ置きます。
GitHubのファイル画面を「ページとして保存」して`.stl`と改名しないでください。
上の直接ダウンロードを使うか、GitHubのファイル画面では **Download raw file** を使い、
実際の拡張子が`.zip`／`.3mf`／`.stl`であることを確認します。HTMLなら印刷データではありません。

`print-kit.zip`にはunique STLの`parts/`、`bom.csv`、`assembly.json`、`drawings.pdf`、
`READ-FIRST-ja.md`と既存の`fit-coupons.zip`が入っています。
**STLが1ファイルあることと必要数が1個であることは別です。** 手配置ならBOMの色別数量を使います。
`plates.zip`には`manifest.json`と複数の汎用3MFが入り、**各3MFが1回分の候補配置**です。
配布の`plates.zip`そのものをスライサーへ読み込むのではなく、展開した3MFを1つずつ使います。

**3MFは形状・配置だけです。NOT_SLICEDで、P1S設定入りBambu StudioプロジェクトでもG-codeでもありません。**
STL方式と3MF方式は代替です。**同じ部品の3MFとSTLを両方読み込むと二重配置**になります。
別案のSTLや、別案・別プレートの3MFを同じプレートへまとめて足さないでください。

### 実機の設定を合わせる

1. Bambu Studioで、実際に使う **Bambu Lab P1S／装着済みノズル径** に合うプリンタプリセットを選びます。
   0.2 mmを装着しているのに0.4 mm設定を使う等の不一致があれば止めます。合う設定がない場合も別機種で代用しません。
2. 実際のPLAの銘柄・色、プレート種類、処理プロファイルを選びます。この配布物から実機の設定を推測しません。
   下記の0.4 mm本体／0.2 mm文字という案内は未検証のbaselineで、今回の実スライス成功値ではありません。
3. 最初は`FIT-M-D470.stl`と`FIT-F-CP12.stl`を**各1個**読み込みます。
   mm・倍率100%、提供された印刷方向、個数、ベッドへの接地を確認します。通常受けは穴側を下、スタッドは上です。
4. 実機設定でスライスし、初層の穴入口、内部ブリム／サポート、屋根のブリッジとリブ、細い突起の経路を
   [段階試作のプレビュー手順](trial.ja.md)に沿って確認します。入口の閉塞や欠落、分からない警告があれば印刷しません。
5. 使った設定を配布物と別名のローカルBambu Studioプロジェクトへ保存します。
   時間・フィラメント量はこの実スライスの表示結果だけを記録します。設定入りの実プロジェクトは、まだこちらでは受領・照合していません。
6. プレビューと実機条件を確認してから、Bambu Studioまたはプリンタの通常の操作で印刷します。
   本プロジェクトはプリンタへ自動送信したり、未確認のG-codeを提供したりしません。

試験がうまくいかなければ先へ進みません。**0.2 mmノズルにするだけで穴詰まりが解消するとは限りません。**
初層・支持材・流量・温度・穴径を原因不明のまま一律変更せず、現物とスライスを照合し、1条件ずつ記録します。

### 色ごとに選ぶファイル

本体の4色はそれぞれ単色で印刷できます。表の範囲は**選んだ案の全プレート数**で、1つの3MFを開くたびに
新しい空のプレート／プロジェクトから始め、前の配置を残して重ねないでください。
スライス時は**層ごと**の印刷を使い、ヘッドの干渉確認なしに「オブジェクトごと」の順次印刷へ変えません。

| 案 | ブラック単色 | シアン単色 | マゼンタ単色 | グリーン単色 | 別扱いの黒→白 | 合計 |
| --- | --- | --- | --- | --- | --- | ---: |
| A | `A-black-01.3mf`〜`A-black-04.3mf`（4枚） | `A-cyan-01.3mf`（1枚） | `A-magenta-01.3mf`（1枚） | `A-green-01.3mf`（1枚） | 銘板1枚＋ロゴ1枚 | 9枚 |
| B | `B-black-01.3mf`〜`B-black-07.3mf`（7枚） | `B-cyan-01.3mf`〜`B-cyan-02.3mf`（2枚） | `B-magenta-01.3mf`〜`B-magenta-02.3mf`（2枚） | `B-green-01.3mf`（1枚） | 銘板1枚＋ロゴ1枚 | 14枚 |
| C | `C-black-01.3mf`〜`C-black-16.3mf`（16枚） | `C-cyan-01.3mf`〜`C-cyan-05.3mf`（5枚） | `C-magenta-01.3mf`〜`C-magenta-03.3mf`（3枚） | `C-green-01.3mf`（1枚） | 銘板1枚＋ロゴ1枚 | 27枚 |

同じ色でもプレートごとに違う部品・数量です。完了したファイル名と数量を記録し、案名・色・部品IDでトレーを分けます。
白い仕上げは通常の黒単色プレートとは混ぜません。
**表を上から印刷しても、その順に組むわけではありません。**
[3D仕分け・組立ガイド](assembly.ja.md)でファイルを選び、slotと実物の形を合わせてから進めます。
Bの全5段台座は黒01〜04の対象部品を使います。黒01だけでは最下段は揃いません。

### 白い文字・白いロゴは「別の白部品」ではない

**文字とロゴは、黒い支持体に白い盛上りがつながった一体のSTLです。白部分だけを別体で刷って組む方式ではありません。**
色別に本体を印刷しても、この2部品には途中の黒→白切替が必要です。AMSなしで行う場合は手動交換を設定します。

| 選択案 | 銘板：黒→白の専用3MF | ロゴ：黒→白の専用3MF |
| --- | --- | --- |
| A | `A-black-to-white-z2p4-01.3mf`（`NP3-TEXT-A`×1） | `A-black-to-white-z2p8-01.3mf`（`NP3-LOGO-A`×1） |
| B | `B-black-to-white-z2p4-01.3mf`（`NP3-TEXT-B`×1） | `B-black-to-white-z2p8-01.3mf`（`NP3-LOGO-B`×1） |
| C | `C-black-to-white-z2p4-01.3mf`（`NP3-TEXT-C`×1） | `C-black-to-white-z2p8-01.3mf`（`NP3-LOGO-C`×1） |

この汎用3MFには**一時停止（Pause）も色替え命令も自動設定されていません**。
ファイル名とmanifestの高さは、設定すべき位置を示す案内です。開くだけで二色にはなりません。

1. 銘板またはロゴの専用3MFを1つ開き、平らな裏面をベッド、文字／図柄を上にしたまま黒PLAで始めます。
   倍率100%、部品Z=0を保ち、他の黒部品を同じプレートへ加えません。
2. Bambu Studioで実ノズル・PLA・プレートを選びスライスします。文字・図柄には0.2 mmを推奨しますが、線の連続性はプレビューで確認します。
3. **銘板はZ=2.4 mmまでの黒い支持体が終わった直後、次の白い文字層を出す前**に止めます。
   **ロゴはZ=2.8 mmまでの黒い支持体＋円形パッドが終わった直後、次の白い図柄層を出す前**に止めます。
   初層高・可変層高によって層番号は変わります。`2.4÷層高`のような固定番号ではなく、
   プレビュー上の黒地の最終層と、最初の盛上り経路の間で決めます。
4. プレビューのレイヤースライダーで、その**次の盛上り開始層の直前**へ一時停止を追加します。
   Bambu Studioのバージョンに応じたメニュー（通常は対象レイヤーの右クリックから「一時停止を追加／Add pause」）を使い、
   一時停止が実際に挿入され、白い経路より前で止まることを再確認します。位置や操作が分からなければ開始しません。
5. 印刷がその位置で停止したら、プリンタの通常のフィラメントunload／load手順に従って黒から白へ交換し、
   残った黒が混ざらないよう排出を確認してから再開します。プレートや造形物を動かさず、高温部へ触れず、
   自動動作前には手や工具を退避します。未確認の手書きG-codeは使いません。
6. 白いレリーフは**文字1.2 mm、右ロゴ0.8 mm**です。最後まで印刷して十分冷めてから外し、欠け・文字欠落・裏面の反りを確認します。

Pause／交換／再開の初回実機確認はまだ行っていません。P1Sの標準操作に従い、
別機種のタッチスクリーン手順や未検証のM600等のカスタムG-codeを流用しません。

**途中の色替えなしで白文字／白ロゴも完全別体にしたい場合は設計変更です。**
現状データを勝手に分割したり、塗装前提へ読み替えたりせず、別途相談してください。

### 印刷する順番と、個人向けファイルの扱い

`FIT-M-D470`×1＋`FIT-F-CP12`×1 → 必要な`NP3-FIT` → 実ブロック4個 →
keeper1個＋選択案の同一台座端部2個 → 選択案の5段台座と前面 → 顔の少量バッチ、の順です。
色ごとの本体プレートを一気に全部刷る前に、各段階で入口・つかみやすさ・着座・保持を確認します。
閉塞、強い力、つかめない、割れや白化があれば止めます。7個試作を全体合格とは扱いません。

ここで配布するのは汎用版だけです。**個人宛のファイルを一時的にpublicへ置く操作は、この手順には含めていません。**
個人用入力・生成物はprivateのまま保管し、転送方法と残存リスクを確認してから別に扱います。
公開Issueの例にも実recipient名を入れません。

**別途、同じ取付け仕様の個人向けB用銘板1枚を受け取った場合だけ**、汎用の`NP3-TEXT-B`をその1枚に置き換えます。
`B-black-to-white-z2p4-01.3mf`と`NP3-TEXT-B.stl`の両方を印刷対象から外し、交換用ファイルのSTLか3MFのどちらか一方を1個だけ使います。
右ロゴ用の`B-black-to-white-z2p8-01.3mf`や、本体の黒7・シアン2・マゼンタ2・緑1のプレートは変更しません。
交換品も黒い支持体＋白い一体文字なら、2.4 mm後の手動色替えが必要です。完成Bの総部品数を増やす追加部品ではありません。
別サイズや取付けが一致しない銘板には、この置換手順を適用しません。個人ファイルの所在・表示内容をこの公開ガイドへ転載しません。

## 1. 用意するもの

- Bambu Lab P1S、選択したノズルに合うBambu Studioのプリンタ設定。
- 普通のPLA：ブラック、シアン、マゼンタ、グリーン、ホワイト。AMSは不要です。
- 0.4 mmノズルを本体の基本に、0.2 mmノズルを文字銘板・ロゴ・嵌合の改善候補に使います。
- ノギス、平らな机、部品を入れる色別トレー、やわらかい布。必要なら細目のやすり。
- 傷めてもよいという意味ではなく、状態がよく、変形していない市販の小さな2×2／2×4ブロック。

PLAは市販ブロックで多く使われるABSと性質が異なり、割れ・白化・熱変形に注意が必要です。
小部品や破片を子ども・ペットの手の届く場所に置かないでください。組立品を口に入れないでください。
**強く押す、こじる、打撃を加える、熱で無理に合わせる作業はしません。**

## 2. A / B / Cを選んでダウンロード

| 案 | CAD外接寸法 W×D×H（mm） | 組立部品数 | 台座 |
| --- | --- | --- | --- |
| A MINI RELIEF | 143.8 × 64.2 × 187.4 | 91 | 5段・計15部品 |
| B DESK CLASSIC | 191.8 × 80.2 × 238.6 | 150 | 5段・計19部品 |
| C DISPLAY SCULPT | 239.8 × 112.2 × 286.6 | 228 | 5段・計24部品。最下段は2分割 |

数には着脱式銘板と右ロゴ、3個のキーパーが含まれます。試験片は別です。
高さは一番上のスタッド込みです。公開テンプレートの現行版は`5.0-legible-plaques`。
文字の白い部分が0.4 mm厚くなったため、完成奥行きだけが0.4 mm増えました。黒台座の印刷寸法・取付位置は変えていません。
初版から黒台座を4段追加したため、顔の形状は同じでも全高が38.4 mm増えています。
完成Cは256 mmを超えますが、組立前の各部品はP1S内に収まります。完成全高を印刷する1部品の高さと混同しません。

[公開サイト](https://ktanino10.github.io/copilot-brick-display/)で案を選び、「印刷セット」を保存します。
各案の`bom.csv`が色・部品ID・数量・STLの対応表です。同じSTLでも色によって必要数が違います。`finish_color`と`color_change_z_mm`がある銘板・ロゴは、
別々の色替えプレートで印刷します。他の黒部品と一緒に刷って途中で白に替えないでください。
`assembly.json`、組立PDF、サイトの工程表示は同じ部品配置から作っています。
STLは単位情報を持たない形式なので、Bambu Studioでは**mm・倍率100%**として読み込みます。
3MFも提供されている場合は汎用の形状配置ファイルで、Bambuの検証済みプロファイルやG-codeではありません。

**大きさを変えるためにSTLを拡大・縮小しないでください。** 8 mmピッチが変わり、市販品と接続できなくなります。
他の大きさが必要なときは、ブロック数・配置を変更して再生成します。

## 3. 本体より先に、オス・メスの小片を印刷

最初から台座や本体を一括印刷しません。`fit-coupons.zip`の部品を1候補ずつ印刷し、
ファイル名が分かる袋やトレーで保管します。取り違えないよう、同時に混ぜないでください。
まずBambu Studioで実装ノズルとプリセット、材料・プレートを一致させ、
[入口から屋根までのレイヤー確認](trial.ja.md)を行います。
0.2 mmノズルへ替えるだけで閉塞が直るとは限りません。

| 系列 | ファイルID | 変更しているもの |
| --- | --- | --- |
| オス | `FIT-M-D470` / `D480` / `D490` | スタッド外径4.70 / 4.80 / 4.90 mm |
| メス | `FIT-F-CP12` / `CP08` / `CP04` / `CP00` / `CM04` | 半径方向の設計クリアランス +0.12 / +0.08 / +0.04 / 0.00 / −0.04 mm |

負の値は意図的な干渉候補です。最初はメス`CP12`、オス`D470`というゆるい候補から始めます。
形状が似ていてもオス寸法の補正とメス側の補正は別物です。
公称4.8 mmをすべての実物の実測値とみなさないでください。

1. 以下の「印刷の初期設定」で1組を印刷します。完全に冷ましてから外します。
2. 底のつぶれ、糸引き、穴をふさぐブリム、屋根の垂れを観察します。異常があるものは接続試験に使いません。
3. スタッドの円筒部をX・Y両方向で測ります。先端の面取り部分を測らないでください。
4. 4×2片の本体は31.8×15.8 mm、中心間隔は8 mmです。4本のスタッドの両外端間隔から平均外径を引き、3で割るとピッチを確認できます。
5. **印刷オス → 市販メス**を軽く合わせます。次に**市販オス → 印刷メス**を別々に確認します。
6. 両方の組合せがよければ、最後に**印刷オス → 印刷メス**を確認します。
7. 有望な設定を3個ずつ印刷し、色・ノズル・PLAが変わっても同じ結果になるか確認します。

測定表を[fit-log.csv](../site/downloads/fit-log.csv)に残します。機器の精度・測定のばらつきが候補の差より大きいときは、
「0.04 mm違うからよくなった」と結論しません。

### 銘板・ロゴのキー溝も別に試す

`NP3-FIT-PLAQUE`と`NP3-FIT-SOCKET-C25`から始め、C20、C15へ段階的に比較します。
これは本番と同じ裏側の広がり・2.4 mm厚・角度・座面を使った短い試験片です。
銘板とロゴは上から入れ、前・横・下へは形状で抜け止めします。試験片が滑っても、
5段の溝の位置合わせと幅の長い部品の反りは別問題なので、採用した設定で本体用銘板・ロゴを1個ずつ試します。
台座の最前列8 mm帯はこの溝のためにスタッドと底面接続を予約・除外しています。
市販品との接続試験は通常ブロックや台座の2列目以降で行い、前面モジュールを市販品へ無理に接続しません。

### 次へ進む目安（未検証のスクリーニング条件）

- 軽い指の力で最後まで座り、見える段間の隙間が約0.10 mm以下。ぐらつかないこと。
- 小さな組合せを布の上で10秒そっと反転しても外れず、10回の穏やかな着脱で白化・ひび・欠けがないこと。
- 市販部品に傷や変形が出ないこと。引き抜く際に工具やこじりが必要なら不合格です。
- Aの3.2 mmプレートやキーパーも1点先行し、実測したスタッド高さと屋根下面の間に0.10 mm以上の余地が残ること。
- 大きな台座の四隅の浮き・がたつきが平面上で約0.30 mm以下であること。

これは荷重定格や安全基準ではありません。**組立全体を反転する試験ではありません。**
ゆるくても、きつくても、本体に進まず設定を調整します。

### couponの次は、実際のブロックを少量だけ

[少量試作ZIP](../site/downloads/trial-subset.zip)には、現行STLそのままの代表2×2・2×4、keeper、
A/B/Cの台座端部を収録しました。**1案の小BOMだけを選び、4個の実ブロック→keeperと同一台座端部2個の計7個**を段階的に試します。
全案のBOMを合算しません。既存の公差couponは同梱し直さず、上の`fit-coupons.zip`を再利用します。
7個はつかみやすさ・下面閉塞・初期着脱の確認で、5段全幅や大銘板の保持合格ではありません。
その後、選択案の実5段台座と銘板／ロゴ／3個のkeeperを、顔の全数より先に試します。

## 4. 合わないときの補正と再生成

まず、実際に使ったスライス設定入りプロジェクトと現物の該当位置を照合します。
原因不明のまま、全穴径・XY補正・流量・温度を一律変更しません。小穴を一つずつ削る作業も完成キットの前提にしません。
初層、支持材、ブリム、ブリッジ、形状を分けて確認し、1条件ずつ記録して試します。
底のつぶれや屋根の垂れが確認できた場合は、まずその造形条件を検討します。0.2 mmノズルも比較候補ですが、解決の保証ではありません。
以下の寸法補正は、形状と印刷原因を切り分けた後の候補です。

- 印刷スタッドが大きすぎる：`interface.stud_diameter_correction`を小さくします。
- 市販スタッドが印刷メスにきつい：`interface.female_radial_clearance`を大きくします。
- 保持が弱い：試験片で一段ずつ逆方向へ試します。負のクリアランスをいきなり本体へ使いません。
- 銘板・ロゴだけきつい：まず5段の整列と反りを確認し、試験片で`message.clearance`を小刻みに増やします。
  これはキー溝の側方遊びです。文字やロゴの大きさ、8 mmピッチは変更しません。

値は[design/parameters.json](../design/parameters.json)だけで変更します。
たとえばメスの半径クリアランスを`0.04`から`0.08`へ変えることは、穴の直径を一律0.04 mm変える操作ではありません。
内壁・チューブ・ポストを同じ拘束式で再計算します。[再生成手順](rebuild.md)でCADから作り直し、
**新しい試験片で再確認してから、同じリビジョンの本体を印刷**します。古いSTLと混ぜないでください。

## 5. P1S / PLAの印刷初期設定

以下は実機で検証していない出発点です。温度・冷却・流量は、実際のPLA銘柄と使用プレートに対応する
Bambu Studioのプリセットを基準に調整します。AMSがなくても色ごとに印刷できます。

| 項目 | 0.4 mmノズル：本体の基本 | 0.2 mmノズル：細部・文字・再試験 |
| --- | --- | --- |
| 層高 / 初層 | 0.20 / 0.20 mm | 0.10 / 0.20 mm |
| 線幅の初期値 | 0.42 mm | 0.22 mm |
| 壁ループの要求値 | 4 | 7 |
| 上面 / 底面ソリッド層 | 4 / 4以上 | 8 / 8以上 |
| 外壁速度の上限候補 | 30 mm/s | 20 mm/s |
| ブリッジ速度の上限候補 | 20 mm/s | 15 mm/s |
| 残る中実領域のインフィル | 15–20% gyroidから | 同左 |
| サポート | 基本なし。嵌合穴内に自動で入れない | 同左 |
| 外側ブリム | 大きな台座で6 mmを候補に。小片は必要時のみ | 同左 |

CADの壁はおよそ1.46 mm、屋根は通常1.6 mm、薄いプレートだけ1.0 mmです。
壁ループ数の指定だけでは材料が入った証明になりません。スライスのプレビューで壁、ポスト、チューブ、
屋根、文字が連続しているか確認します。細い壁は可変線幅の候補も比較します。
インフィル設定でCADにある空洞を埋めることはできません。

通常ブロック・台座部品・キーパーは**穴側をベッド、スタッドや平らな上面を上**に置きます。
内部リブは8 mmごとで、屋根の直交方向の主な無支持区間は最大6.8 mm、チューブの内穴は3.2 mmです。
それでもブリッジの垂れは実機で確認が必要です。最初の屋根層の橋渡しをプレビューで確認し、
失敗したら流量・冷却・速度・方向を調整して試験片へ戻ります。
薄い屋根に後から層を足すだけでは、最初の層の垂れは直りません。

台座の外形＋左右6 mmブリムはA 155.8×75.8、B 203.8×91.8、
Cは**1枚につき131.8×123.8 mm**です。公称256×256 mm内に収まる寸法ですが、
プレートの実際の除外領域・スカート・校正線・ヘッド干渉はBambu Studioで別に確認します。
中央寄せで1枚ずつ試すのが基本です。Cの2枚を無理に1プレートへ詰め込みません。
印刷時間・重量の実測値や検証済みG-codeは提供していません。

### 大きい2行銘板と右ロゴ

`NP3-TEXT-A/B/C`と`NP3-LOGO-A/B/C`は、どちらも**平らな裏面をベッド、文字／図柄を上**にしたSTLです。
0.2 mmノズルを推奨します。黒PLAで始め、銘板は**2.4 mm層を終えた直後**、ロゴは
**2.8 mm層を終えた直後**に一時停止して白PLAへ手動交換します。白レリーフは文字1.2 mm、右ロゴ0.8 mmです。
これは設計境界で、固定の層番号ではありません。初層・可変層高を含む実プレビューで最初の白経路の前にPauseがあることを確認します。
AMS不要・別々の色替えプレートで印刷します。画像だけの文字・テクスチャではなく、本物の立体形状です。
元の図柄画像は公開していません。黒い背板が白い図柄全体を支えるため、小さな白い尾や耳を別部品で貼り付けません。

| 案 | 銘板の裏側幅 × 高さ | 主文 / URLの文字高 | 右ロゴの円径 / キャリア幅 |
| --- | --- | --- | --- |
| A | 102 × 40 mm | 10 / 10 mm | 28 / 32 mm |
| B | 142 × 40 mm | 12 / 10 mm | 36 / 40 mm |
| C | 182 × 40 mm | 14.5 / 10 mm | 40 / 48 mm |

主文はBold、URLはBlackです。孔・eの出口・字間を広げ、平行な正のストロークと材料neckも実CADから別々に測定しています。
小型Aの主文は幅内で材料を保つため異なる目標を使います。[各案の実測と限界](lettering.ja.md)を確認してください。
曲線の先端や数学的な角の全てに同じ幅があるという意味ではないので、スライサーで細部も確認します。
キー溝の裏側は広く、表側は各端2 mm狭い形です。印刷向きと斜面を勝手に反転しないでください。

銘板を全数刷る前に[文字の小試験片ZIP](../site/downloads/lettering-coupons.zip)から、
選んだ案の`GLYPH-A/B/C`を1個だけ使います。上に`aeod`、下に`gbo./R`があり、実銘板の字形を拡大縮小せず移したものです。
STLと3MFは代替なので両方読み込まないでください。平らな黒支持体を下、黒2.4 mm後に白1.2 mm。
孔・eの開口・dot/slash・細線の経路が残るか先にスライスで確認し、冷めた実物で閉塞・文字同士の橋・糸・欠け・荒れを観察します。
閉塞や白化があれば本体銘板を刷らず停止します。試験片は完成BOMに含まず、成功しても全体保持の合格ではありません。
0.2 mmノズルでのフィードバックを受けた形状案であり、0.2 mmにすれば成功する、糸引きや上面荒れが形状だけで直る、とは扱いません。
実設定入りBambu Studioプロジェクトは未受領です。実ノズル・PLA・初層・flow・冷却・速度等は一条件ずつ現物と照合します。

## 6. 色別に本体を印刷し、番号付きトレーへ

採用した設定で色ごとに印刷します。各BOM行は`部品ID × 色 × 数量`です。
一度に全部刷る前に、深いブロック、薄いプレート、キーパー、前面モジュールを1個ずつ実物で確認します。
完全に冷えたらプレートの説明に従って取り外し、外側ブリム・糸引きだけを丁寧に除去します。
スタッドやチューブを削りすぎると候補寸法ではなくなります。ひび・白化があるものは使いません。
ラベルは`A-001`などの**配置番号**と`BR-…`の**形状ID**を区別してください。

## 7. 下から、1段ずつ組み立てる

選んだ案の[サイトの工程表示](https://ktanino10.github.io/copilot-brick-display/#workbench)、
組立PDF、BOMを横に置きます。工程の平面図は**手前が図の下**です。
工程表の各配置番号はFreeCAD、Webの部品選択、Blenderの最終配置と一致します。

1. 黒台座の1段目を机に置きます。Cは最下段を2枚に分け、中央に0.2 mmの隙間ができるよう並べます。
2. 2〜5段目を番号順に積みます。各段は本物の独立部品で、継ぎ目が互い違いになる配置です。
   Cの中央継ぎ目も上の段がまたいで連結します。前側5段のキー溝が一直線になることを確認します。
3. 大きい文字銘板を左、ロゴを右のキー溝へ、それぞれ上から差し込みます。両方ともZ4〜44 mmの台座内に納まります。
4. 銘板の上止め用キーパー2個と、ロゴ用1個を、台座上の2列目のスタッドへ載せます。
5. 顔の本体1段目から指定の色・形状・位置へ上から載せ、緑の縦線、ゴーグル、頭頂まで進みます。
6. 各段の隙間、キーパーの保持、2行と右ロゴの位置、台座のがたつきと転倒しやすさを確認します。

銘板の文字は正確に以下の2行です。

> Same icon, New adventures<br>
> github.com/USER

2行目は仮表示で、実在の相手のプロフィールを示すものではありません。
別の文字へ変える場合は[公開forkとprivate入力を分ける手順](customize.ja.md)を先に読み、
非公開の値を公開Issue・PR・CAD・画像へ入れないでください。

交換時は該当モジュールのキーパーだけを、まず上へ6 mm程度外し、手前へ32 mm以上離して脇に置きます。
その後モジュールをまっすぐ45 mm以上持ち上げ、キー溝から抜いて手前へ取り出します。
文字とロゴは別々に交換できます。本体は後ろにあり抜去経路をふさぎませんが、実物でも軽い力で確認します。
全部分解するときは前面モジュールを外し、顔を上から逆順に、最後に台座を上段から外します。
完成品を持つときは**台座を両手で支えます**。頭、ゴーグル、銘板、ロゴ、キーパーを持ち手にしません。

### サイトの大きい上下分解表示

0%は実CADの完成配置です。初めにキーパーを解除してモジュールを上抜き・前へ分離し、
100%では下段を下へ、上段を上へ広げます。台座5段も対象で、各段の空隙は18.2 mm以上です。
表示中の外接範囲に合わせてカメラを調整し、向きは保ちます。これは説明用の移動で、物理的な分解保証や寸法変更ではありません。
上下の隙間は立体・正面・側面で確認してください。上面は上下の部品が投影上重なります。

## 8. 完成後の確認と困ったとき

平らな机の奥側で、台座の浮き、揺れ、前後左右への倒れやすさを軽く確認します。
落ちても被害のない低い位置で行い、押し倒したり振動を加えたりしません。
ぐらつく、自然に外れる、ひびが出る場合は飾らず、該当部品と設定を見直します。
棚の縁、直射日光、暖房器具の近く、車内には置きません。

| 症状 | 確認するところ |
| --- | --- |
| 最後まで座らない | 異物・ブリム・底のつぶれ・屋根の垂れ・実測スタッド高さ。無理に押さず試験片へ戻る |
| 硬すぎる | オス寸法とメスクリアランスを別々に確認。0.2 mmノズルも候補 |
| ゆるくて落ちる | 片側ずつ試験。保持を確認できる設定になるまで本体を積まない |
| 部品が余る／色が違う | 選択したA/B/C、BOMの色別数量、配置番号、工程を照合 |
| 台座が反る | プレート清掃・冷却・外側ブリム・PLA条件を再確認。Cは2枚のまま印刷 |
| 文字やロゴがつぶれる | 0.2 mmノズルで前面モジュールだけ再印刷。倍率変更ではなく線幅と層を確認 |
| モジュールが上へ抜ける | 対応するキーパーが装着され、スタッドの保持が確認できているか。きつい／ゆるい時は試験片へ戻る |

CAD・動画・自動チェックは、これらの実物確認を代行しません。

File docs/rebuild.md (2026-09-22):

# Rebuild / 再生成

## Inputs and tools

- `design/parameters.json`: edit this for fit candidates, message or layout dimensions.
- `scripts/design.py`: discrete A/B/C layout and ID/step rules.
- `scripts/freecad_geometry.py`: the only source for mechanical solids.
- `scripts/front_nameplate.py`: five-course front receivers, independent plaque/logo and keeper geometry.
- `scripts/nameplate_lettering.py`, `legible_lettering.py`, `legible_metrics.py`: exact glyphs, counter/e edits, added spacing and positive-material checks.
- `resources/github-mark-relief.json`: normalized user-supplied mark contours; no input raster is distributed.
- Real FreeCAD 1.1.3, Blender 5.1.1 and ffmpeg 8.1 were used for the delivered native files.
- Python 3.11 with `requirements.txt`, and Node.js with `package-lock.json`.
- The bundled B612 Mono Bold font is under SIL OFL; its notice is next to the font.

FreeCAD must expose its `FreeCAD`, `Part`, `MeshPart`, `TechDraw` and `FreeCADGui` modules
to the **matching embedded Python**, not an unrelated system Python.
Set `FREECAD_PYTHON` to that executable and `FREECAD_LIB` to its module directory on your installation.
No personal machine path is hardcoded in this repository.
On a desktop, use a separate headless process rather than taking over an already open document.

```bash
python3 -m venv .venv
.venv/bin/python -m pip install -r requirements.txt
npm ci
npm run vendor

METRICS_SITE_PACKAGES=$(.venv/bin/python -c 'import site; print(site.getsitepackages()[0])')
export PYTHONPATH="$FREECAD_LIB:$METRICS_SITE_PACKAGES:scripts"

python3 scripts/design.py
.venv/bin/python -m unittest discover -s tests -v

FREECAD_USER_HOME="$PWD/build/freecad-profile" QT_QPA_PLATFORM=offscreen OMP_NUM_THREADS=2 \
  PYTHONPATH="$FREECAD_LIB:$METRICS_SITE_PACKAGES:scripts" \
  "$FREECAD_PYTHON" scripts/freecad_build.py

PYTHONPATH="$FREECAD_LIB:$METRICS_SITE_PACKAGES:scripts" \
  "$FREECAD_PYTHON" scripts/verify_cad.py
.venv/bin/python scripts/verify_meshes.py
PYTHONPATH="$FREECAD_LIB:$METRICS_SITE_PACKAGES:scripts" \
  "$FREECAD_PYTHON" scripts/verify_front_nameplate.py
node tests/motion.mjs
PYTHONPATH="$FREECAD_LIB:$METRICS_SITE_PACKAGES:scripts" \
  "$FREECAD_PYTHON" scripts/freecad_details.py
.venv/bin/python scripts/build_drawings.py
.venv/bin/python scripts/package_prints.py
```

`freecad_build.py` saves genuine FCStd files with view colors, STEP, per-part binary STL,
and hidden-line CAD projections. It uses Qt's offscreen backend, not the user's interactive CAD
document. On the tested macOS package Qt warns that offscreen OpenGL widgets are unsupported;
solid generation, TechDraw projections, native appearance serialization and subsequent reopen
are verified separately. No screenshot is substituted for a native model.

Intermediate BREP caches and render frames live under ignored `build/`. A cache key includes
the mechanical source and parameter hashes. A changed fit value requires regenerating the full
affected set, not mixing an old STL with new documentation.

## Blender and media

```bash
blender --background --factory-startup --threads 2 \
  --python scripts/blender_scene.py -- --model A
blender --background --factory-startup --threads 2 site/downloads/A/A.blend \
  --python scripts/blender_verify.py -- --model A
python3 scripts/render_movies.py --model A
.venv/bin/python scripts/sanitize_artifacts.py --model A
blender --background --factory-startup --threads 2 site/downloads/A/A.blend \
  --python scripts/blender_verify.py -- --model A
```

Repeat sequentially for B and C; do not launch multiple high-CPU renders.
The scene contains the actual delivered STL meshes, original instance IDs and catalogue transforms.
Geometry is converted from millimetres to metres explicitly; the Blender scene uses metric units.
Blender Workbench is used as an actual studio renderer, not a physics simulation.
Objects arrive in the numbered assembly order, followed by a completed-object turntable.
The still and frames are rendered by Blender. ffmpeg encodes H.264/yuv420p MP4 with faststart.
The native `.blend` and every movie are reopened/decoded independently.

The black text module changes to white after 2.4 mm; the independent logo changes after 2.8 mm.
White relief is real geometry, not a texture. Print the two modules on separate plates; no AMS is required.
Text relief is1.2mm in revision5; logo relief remains0.8mm. The existing rear carrier is unchanged,
but assembly depth grows0.4mm. The generic URL placeholder is now `github.com/USER`.
`METRICS_SITE_PACKAGES` must belong to the same Python ABI/architecture as the FreeCAD embedded interpreter.
If the selected environment cannot import NumPy/SciPy/Shapely and the FreeCAD Qt wrapper together,
stop and select a matching environment; do not skip the lettering checks.

For a typography-only revision, the mechanical reuse check deliberately excludes text-only
parameters/functions but still compares the full carrier/receiver/keeper/logo functions and dimensions.
`--reuse-baseline` takes a locally preserved, verified source/catalog snapshot; it does not import old history.
`package_prints.py --update-parts NP3-TEXT-A NP3-TEXT-B NP3-TEXT-C` rewrites only the three relevant3MF
files after checking every original layout hash and occurrence count. Re-run `verify_3mf.py` afterward.
`update_blender_plaques.py` swaps only that one mesh in each saved scene and removes orphan data.
`render_plaque_revision.py --model B --baseline PATH` preserves the verified movie interval before
the plaque appears, then actually rerenders all affected frames. It never relabels unchanged old footage
as a newly rendered full movie. Use `build_lettering_coupons.py` for same-scale trial glyphs and
`verify_lettering.py --baseline-cache PATH --preview-folder PATH` for actual native measurements.

For a geometry-identical prior cache, `--reuse-baseline` checks unchanged brick-function ASTs,
the interface and delivered mesh hashes. `--reuse-preview` reuses the approved B geometry only
when its recipe and per-part inputs match. Modified metadata does not justify unverified geometry reuse.
The non-text meshes, dimensions and placements are checked against `design/public-template-invariants.json`.
The unselected individual variant is withheld from public distribution and is not rebuilt by this workflow.
Public parameters are checked against `design/publication-policy.json`. For private values, use
the separate ignored-output command in [the customization guide](customize.ja.md), not the public build.

## Static site

### Print-file to assembly guide (no CAD or Blender regeneration)

The common viewer has an [explicit input/mapping/offline contract](../web/assembly-guide/README.md).
Its source data is the already-verified catalog, model assembly, actual print-plate manifests,
STL and 3MF files. It verifies every print occurrence against the assembly by part ID and color.
It does not invent a one-to-one physical identity for interchangeable copies.

```bash
npm ci
npm run build:assembly-guide
.venv/bin/python scripts/build_public_assembly_guides.py
.venv/bin/python -m unittest discover -s tests -p test_assembly_guide.py -v
node tests/assembly_guide_model.mjs
.venv/bin/python tests/assembly_guide_browser.py \
  --entry site/assembly-guide/B.html --all-models --capture-media
```

Only the public wrapper enforces the generic publication policy. For private input, use the
root-independent `build_assembly_guide.py` with explicit paths and `--standalone` in the
private destination; do not regenerate the public catalog with private text.
The offline ZIPs contain a self-contained HTML viewer, correspondence JSON and the Three.js
MIT notice. They contain no printer profile or G-code. Runtime bundling adds no network dependency.
The annotated new guide images/video are captured from this real STL viewer, not claimed to be
new Blender renders. The existing native scenes and movies remain unchanged.

```bash
python3 -m http.server 8000 --directory site
npm test
BASE_URL=http://127.0.0.1:8000/ npm run test:web
```

For a repository-subpath check, serve the parent directory with a `copilot-brick-display`
mapping or use the local prefix server in `scripts/serve.py`.
The Playwright test can use `BROWSER_PATH` to select an installed browser, otherwise install its
matching Chromium using `npx playwright install chromium`.
The runtime Three.js files and MIT notice are vendored: the public viewer does not need a CDN.

GitHub Pages deploys only `site/` using the checked-in workflow. Source, native files, drawings,
media, messages and notices are public; original photos, personal paths and session history are not.
Do not commit `build/`, virtual environments, dependencies, generated frame sequences, or credentials.

## After a design edit

1. Regenerate layout and geometry; run unit, BREP, mesh and assembly checks.
2. Rebuild projections, PDFs, BOM/print bundles, 3MF layouts, Blender scenes and videos.
3. Confirm catalogue/mesh hashes, color/quantity/placement correspondence and reachable assembly.
4. Request independent review of the fixed changed snapshot. A previous review is not blanket approval.
5. Audit the public package and deploy. **Print calibration coupons again before printing the object.**

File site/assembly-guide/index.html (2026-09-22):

BRICK / ASSEMBLY LAB

# 刷ったパーツは、 どこに使うの？

3MFファイル → プレート内の番号 → 組立の場所。
同じ実STLを見比べて、空の机から1個ずつ組めるガイドです。

印刷順と組立順は、違います。

Bの1段目は B-black-02.3mf のslot 3 → B-001。black-01が1段目ではありません。下から案を選んで始めてください。

## 印刷した案を選ぶ

### A / MINI RELIEF

91個 / 9プレート
最初: black-02 · slot 3

Aの対話3Dガイドを開く →

AのオフラインZIP ↓

### B / DESK CLASSIC

150個 / 14プレート
最初: black-02 · slot 3

Bの対話3Dガイドを開く →

BのオフラインZIP ↓

### C / DISPLAY SCULPT

228個 / 27プレート
最初: black-04 · slot 2

Cの対話3Dガイドを開く →

CのオフラインZIP ↓

ZIPは展開して index.html をダブルクリック。サーバー・CDN・ログイン・通信は不要です。オフライン版も同じ操作と実形状です。STLやプリンタ設定の配布ZIPではありません。

仕分け図・最初の台座アニメ・操作の説明 · 印刷の手順 · 完成モデルへ戻る

公開の文字は短い汎用表記USER。案を混ぜないでください。無接着・NOT_SLICED・実物の嵌合と保持は未試験。部品への刻印ではない案内用番号を使います。実STLから作った説明表示で、物理シミュレーションではありません。

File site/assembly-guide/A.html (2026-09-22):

BRICK / ASSEMBLY LAB

# A / 印刷ファイルから組み立てる3Dガイド

印刷したファイルを、実物の部品の形で探す。
見つけたら、1個ずつ組み立てよう。

印刷順 ≠ 組立順。プレート番号は「段数」ではありません。

最初の部品を確認しています。

最初の1個を見せる

5段台座に必要なファイルを確認

下のファイルにある対象部品を先に仕分けます。同じ形・同じ色のコピーは交換可能ですが、必要な個数は減りません。

実STLとプレート対応を読み込み中…

1個ずつ組む

## 最初の1個

### 01 ファイルから部品を探す

印刷した3MF

斜め上 前右 背面裏面

選んだ1個を拡大（裏面・溝の違いを見る）

手前 = −Y / 印刷面は上

### 02 場所と向きを確認して組む

組立工程（プレート番号とは別）

斜め前 右上 背面裏面

組立済みを淡くして、隠れた接続を見る

正面 = 銘板・右ロゴの側

やり直し1個戻る 再生次の1個 この工程だけ再生 速さ

手順の区切りへ移動（今の1個は「次の1個」で確認）

今の1個の動き 0%

## プレート内の番号から選ぶ

番号はこのガイド用のslotです。部品への刻印ではありません。 Bambu Studio側の並べ替え後の番号でもありません。元の配置と形で照合してください。

同じpart ID＋同じ色の部品は交換可能です。「便宜割当」は仕分け例であり、その実物1個だけの行き先を断定しません。寸法が同じでも、IDや溝が違うものは交換しません。

### 使える組立場所

選ぶとその場所を示します。「ここから組む」で、その直前まで組立済みの状態へ移動します。

### 同じ形・色を取り出せる全ファイル

3D内の部品も選択できます。図形が重なる場合は上のslot・場所ボタンを使ってください。回転はドラッグ／左右キー、ズームはホイール／ピンチです。

## 図で分かることと、実物で確認すること

実STL・実配置から作った説明用3DCGです。動きは手順の案内であり、物理シミュレーションや嵌合合格の証拠ではありません。無接着。無理押し・打撃をしないでください。

NOT_SLICED / 実機嵌合・keeper保持・強度・転倒は未試験。 先にFIT・NP3-FIT・少量試作。閉塞・白化・強い力・着座不良があれば全数印刷と組立を止めます。

本体は色別単色。銘板は黒支持体2.4 mmの後に白文字1.2 mm、右ロゴは2.8 mmの後に白レリーフ0.8 mm。実レイヤープレビューで最初の白経路の直前にPauseを設定します。固定層番号ではありません。汎用3MFにPauseやプリンタ設定は入っていません。改訂した文字は先に文字試験片で孔・字間・欠けを確認します。

STLを100%・mmで使用。同じ部品のSTLと3MFは重ねて読み込まないでください。スロット一覧はダウンロード・スライス・プリンタ送信を実行しません。

オフライン・使用ライブラリ

実形状と対応データはこのHTMLに埋め込まれています。通信、CDN、API、解析サービスは使用しません。Chrome・Edge・Firefox・Safariの現行版で開いてください。Three.js / OrbitControls / STLLoader はMITライセンス（Copyright © 2010–2025 three.js authors）。著作権表示とライセンス全文は同梱runtimeにも保持されています。本作品は非公式で、包括ライセンス・互換認証・玩具認証は付与していません。

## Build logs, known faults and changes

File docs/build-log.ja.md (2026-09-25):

# 制作記録 — Bの台座から完成まで

**2026-09-25、個人向けBが完成しました。**
本人から「これで完成ですね」という言葉と、ゴーグルの上枠・紫の頭頂まで揃った全体写真が届きました。
台座から一段ずつ積み上げてきた制作過程と、完成した姿をここに残します。
公開画像は識別情報を伏せています。

**最新報告日：2026-09-25。個人向けB版の制作例です。**
この記録は、ユーザー本人から届いた進捗報告と実物写真をまとめたものです。
CGの完成図ではなく、台座・前面部品、顔下部、ゴーグルを経て完成に至った実物の記録です。

[09/25：ゴーグルを積み上げ、完成へ](#build-2026-09-25) ／
[09/24：顔下部の途中記録](#build-2026-09-24) ／ [09/23：台座と前面部品の記録](#build-2026-09-23)

銘板の個人向け表示と周辺の識別情報は、公開用の画像そのものから除去しています。
公開モデルの仮文字 `USER` を実写真へ合成してはいません。測定や版の照合とは異なる点は、
末尾の[写真観察と検証の境界](#evidence-boundary)にまとめています。

## 今回の制作フロー

**[企画](#flow-planning) → [設計](#flow-design) → [3Dプリント](#printing-video) → [超音波洗浄](#post-print-cleaning) → [アッセンブリー（組み立て）](#build-2026-09-25)**

この5工程は、ユーザーが示した今回の制作フローです。写真の撮影時刻・枚数やCADの工程番号を表すものではありません。

| 工程 | 今回の取り組み | 見る資料 |
| --- | --- | --- |
| 企画 | 卓上に飾る用途、ブロックらしい形、A/B/Cのサイズや奥行きを検討 | [3案の比較](../site/index.html#compare) |
| 設計 | FreeCADの分割部品・取付け・文字を設計し、図面とBlender設計CGで確認 | [設計の根拠](design.md) ／ [文字改善と実CAD比較](lettering.ja.md) ／ [CAD・図面・設計CG](../site/index.html#downloads) |
| 3Dプリント | 設計したブロックを印刷 | [ユーザー提供動画をページ内で再生](#printing-video) ／ [印刷手順](build.ja.md#print-another-pc) |
| 超音波洗浄 | 今回取り入れた印刷後の後処理 | [ユーザー提供動画をページ内で再生](#post-print-cleaning) |
| アッセンブリー（組み立て） | 台座から顔・ゴーグル・頭頂まで組み立てて完成 | [制作写真と完成報告](#build-2026-09-25) ／ [部品別3D組立ガイド](../site/assembly-guide/B.html) |

## 本人の報告と、ここまでの学び

| 報告・設計記録 | 分かったこと | まだ分からないこと |
| --- | --- | --- |
| 09/22：文字が小さく、孔・開口・字間が狭く印刷しにくいという報告。ノズルは本人申告で0.2 mm | 文字形状を見直す具体的な課題が得られた | 糸引き・上面荒れの原因を温度・flow・材料などへ断定できない |
| その後：2行を維持し、孔・字間・下段の文字高・白文字の厚みを改訂 | 公開版5.0のCAD上の変更と実測値は[文字改訂の記録](lettering.ja.md)で確認できる | 写真の現物がどのSTLハッシュ・スライサー設定を使ったかは未照合 |
| 09/23 12:09：「いけているみたい」と銘板2枚の写真を提供 | 本人から改善感の報告があった | 2枚の旧版／新版の対応や、どちらが合格したかを断定しない |
| 09/23 12:18：「土台が組み上がりました」と制作写真7枚を提供 | 個人向けBの台座と前面モジュールの制作が進んだ | 顔・ゴーグルを含む完成全体、保持力・転倒・耐久性は確認できない |
| 09/24 22:27：「こちらは組み立ての途中記録になります」と写真7枚を提供 | 台座・前面部品の上に顔下部を積む途中の進捗報告 | 正確なCAD工程・撮影順、上部ゴーグル・頭頂の完成、周囲の黒い板状物の用途は未確認 |
| 09/25 21:44：「制作過程の写真です」と写真8枚を提供し、続いて「これで完成ですね」と報告 | ゴーグル上枠・紫の頭頂・銘板・右ロゴが揃った、個人向けBの完成報告と完成写真 | 使用STLや実設定との照合、測定による保持力・強度は別途 |

上の時刻は**報告時刻**です。写真ごとの正確な製作・撮影時刻ではありません。
09/23に届いた写真の元ファイル日付は09/22・09/23が混在し、時系列を確定できません。
09/24・09/25の写真も、添付順やファイル名から製作・撮影時刻を推定しません。
以下の番号は**説明する順番**であり、製作順・撮影順・CAD工程番号ではありません。
同じ段階を別角度から写した写真を、別々の工程として数えません。

## 2026-09-25 — ゴーグルを積み上げ、完成へ

「制作過程の写真です」と届いた8枚には、シアンのゴーグルを積み上げる途中と、最後の全体姿が写っています。
続く本人の「これで完成ですね」という報告と合わせ、**個人向けBの完成報告と完成写真**として記録します。
以下は見える変化をまとめた説明順です。8枚をそのまま8つのCAD工程や撮影時刻へ対応付けてはいません。
[完成写真を先に見る](#completed-portrait-2026-09-25)こともできます。

### 09/25・01 — シアンの下縁と端を積む

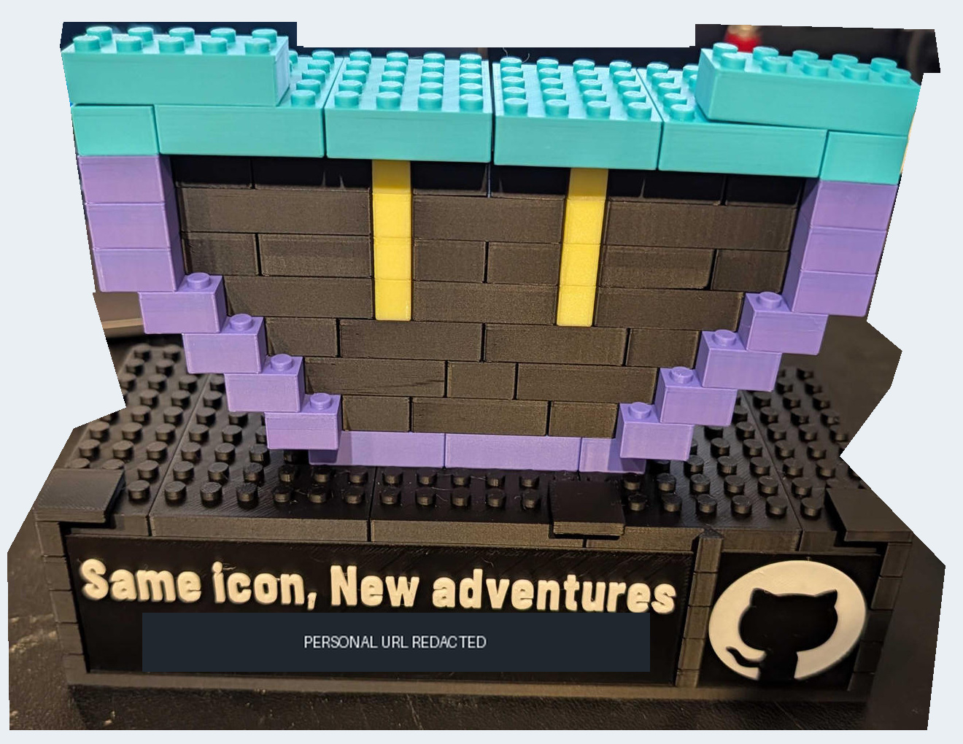
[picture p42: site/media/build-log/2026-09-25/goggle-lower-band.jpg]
09/25の実物写真01：顔下部の上にシアンの横列と左右の端のブロックが加わった姿


**09/25・写真01。** 黄色い縦2列のある顔下部の上へ、シアンの下縁が横に渡っています。
両端にはその上のブロックも載り、大きなゴーグルの輪郭が見え始めました。

### 09/25・02 — 黒い左右の面と中央のシアンが高くなる

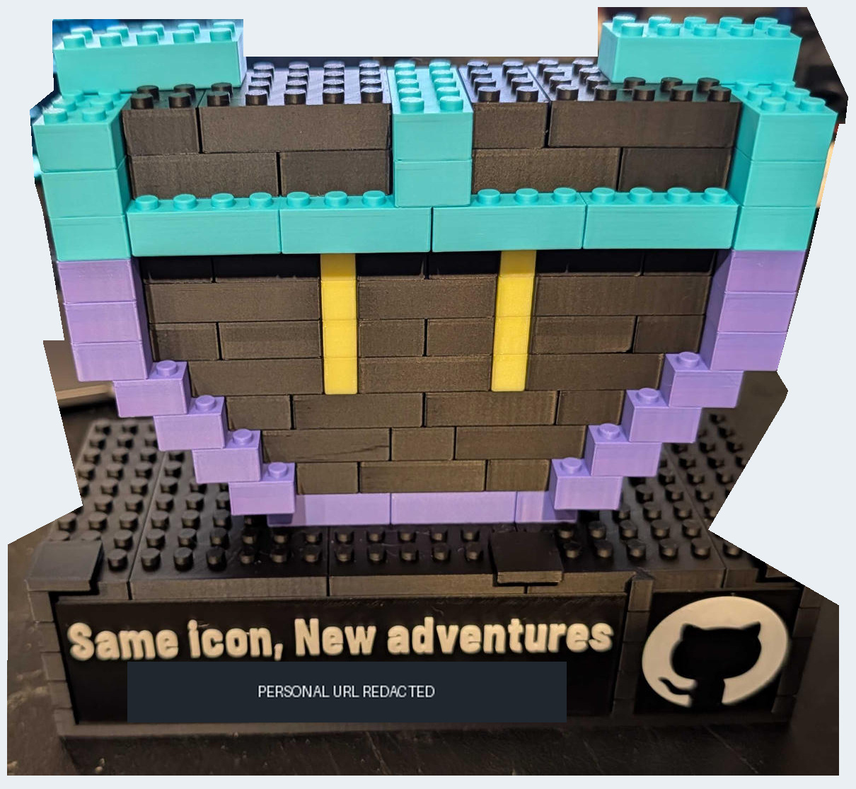
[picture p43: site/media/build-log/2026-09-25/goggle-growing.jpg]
09/25の実物写真02：シアンの側面と中央列、その間の黒い左右の面を積み上げた途中


**09/25・写真02。** 左右の黒い面を、シアンの外周と中央の列が区切っています。
下部の紫の輪郭からゴーグルへつながり、顔全体の印象がはっきりしてきたところです。

### 09/25・03 — 上側が開いたゴーグル枠

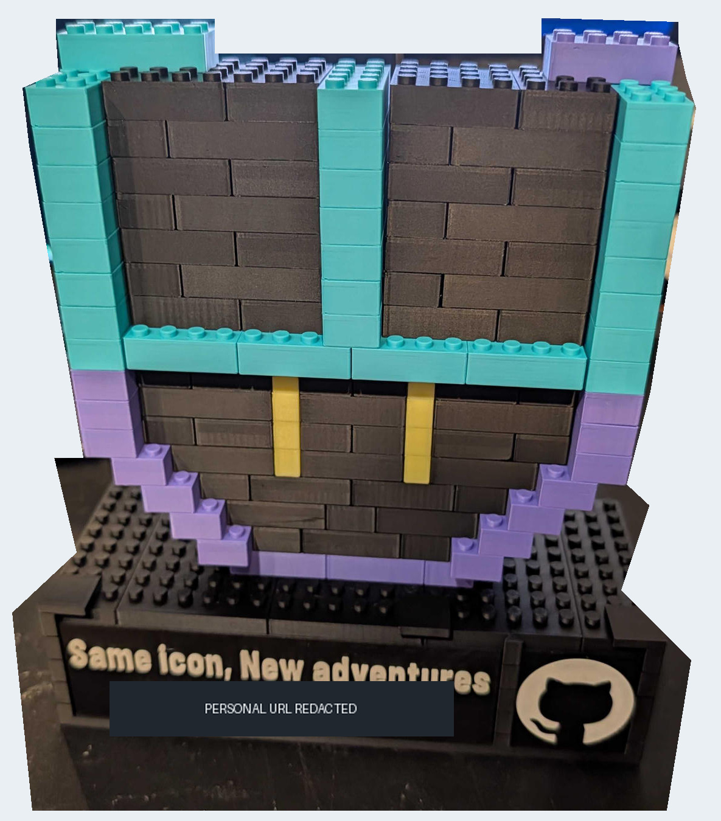
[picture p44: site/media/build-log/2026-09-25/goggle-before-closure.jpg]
09/25の実物写真03：高くなった黒い左右の面とシアンの側面・中央列。上枠を閉じる前の姿


**09/25・写真03。** ゴーグルの高さが増し、上部を仕上げる前の状態です。
上側の開いている部分や、上面のスタッドが見えます。

### 09/25・04 — 上枠と紫の頭頂まで揃い、完成

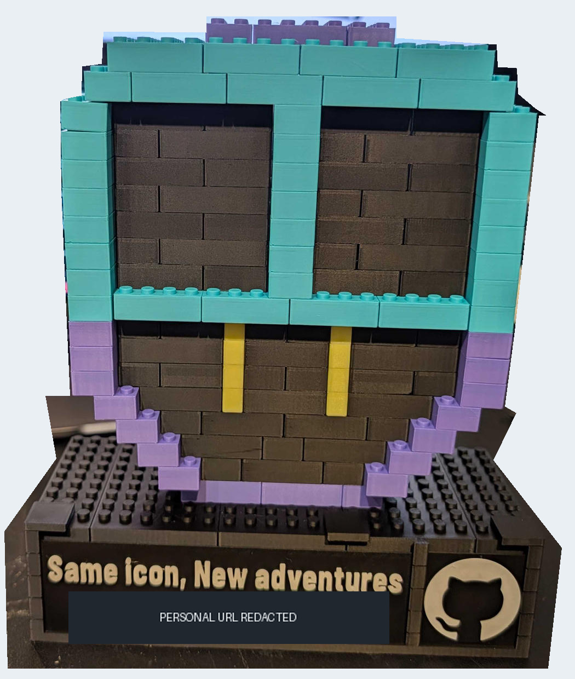
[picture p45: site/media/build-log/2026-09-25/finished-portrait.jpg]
09/25の完成写真04：ゴーグルのシアンの上枠、紫の頭頂、顔、台座・銘板・右ロゴまで揃った個人向けB


**09/25・写真04。完成です。** ゴーグルの上枠が閉じ、紫の頭頂も揃いました。
黒い顔、シアンのゴーグル、紫の輪郭、黄色い縦2列、そして台座の銘板と右ロゴまで、全体の姿が写っています。
本人から届いた言葉は**「これで完成ですね」**。台座から積み上げてきた個人向けBの完成を、この写真とともに記録します。

### 09/25・補足 — 組立途中を別角度から

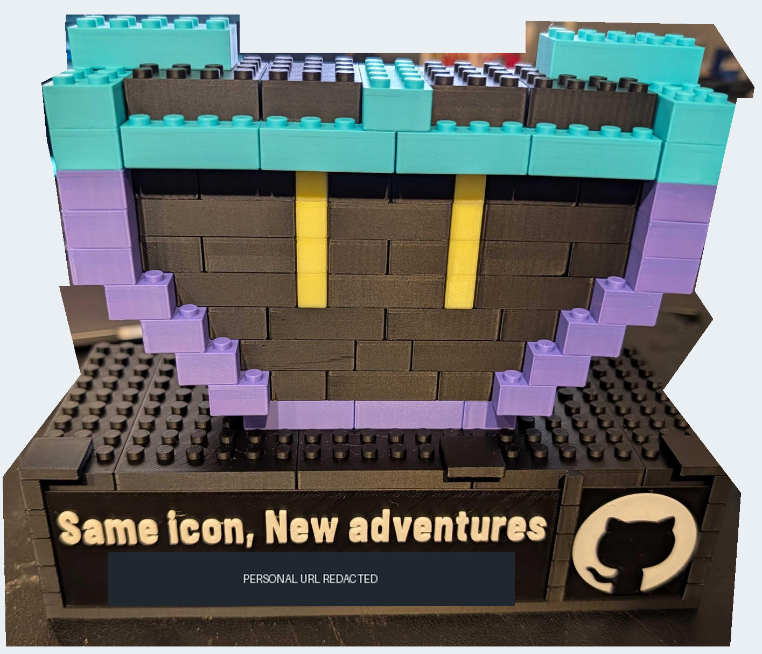
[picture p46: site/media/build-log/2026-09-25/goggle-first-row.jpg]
09/25の補足写真05：シアンの下縁・端・中央列と黒い上部ブロックが見える組立途中


**09/25・写真05。** 下縁と端のシアン、中央列、黒い左右の面を写した途中の見本です。

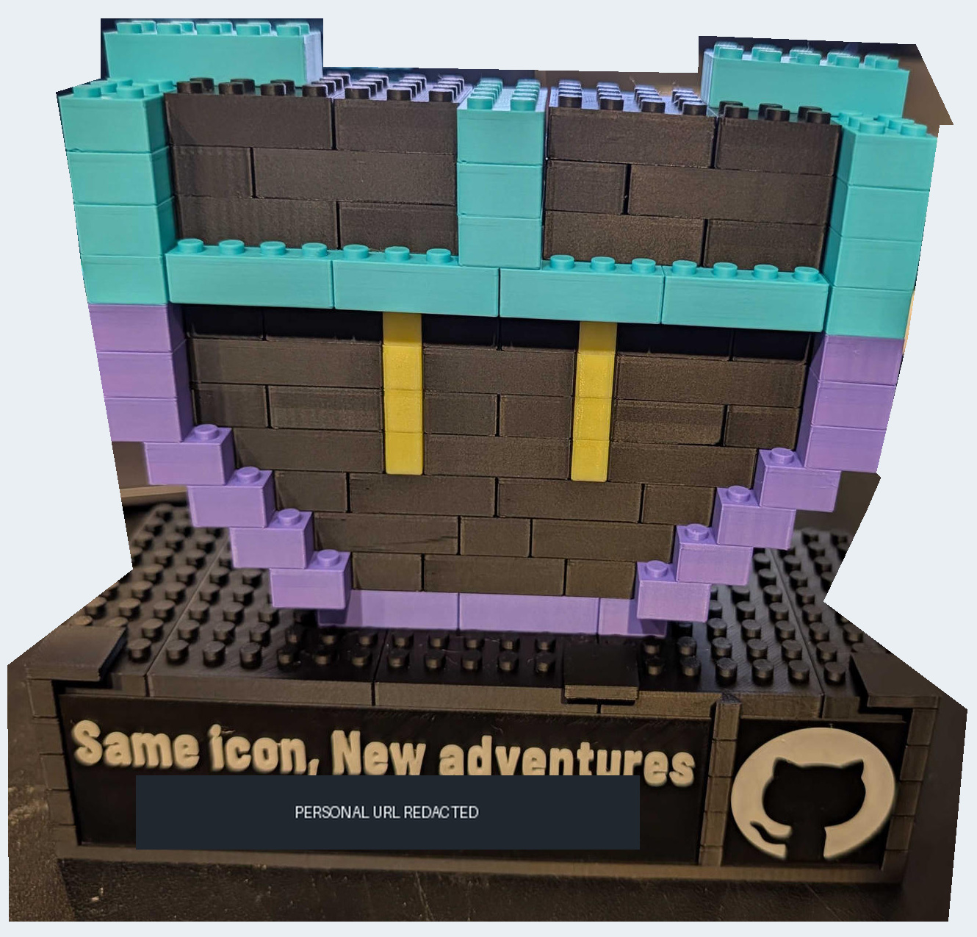
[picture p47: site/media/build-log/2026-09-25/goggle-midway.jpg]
09/25の補足写真06：黒い左右の面とシアンの縁を別角度から見た途中状態


**09/25・写真06。** ゴーグルの縁と黒い面が見える別角度です。近い状態を補足する写真として残しています。

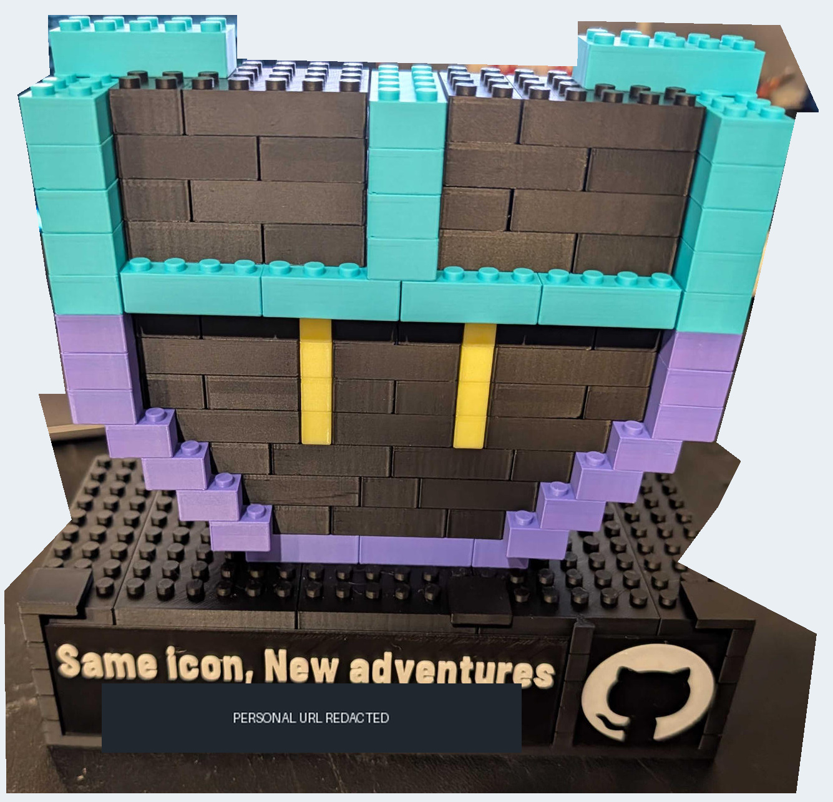
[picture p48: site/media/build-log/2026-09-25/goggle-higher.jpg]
09/25の補足写真07：さらに高くなった黒い左右の面と中央のシアン列。上枠はまだ開いている


**09/25・写真07。** 黒い面と中央列の高さが増し、上枠を閉じる前の輪郭がよく分かります。

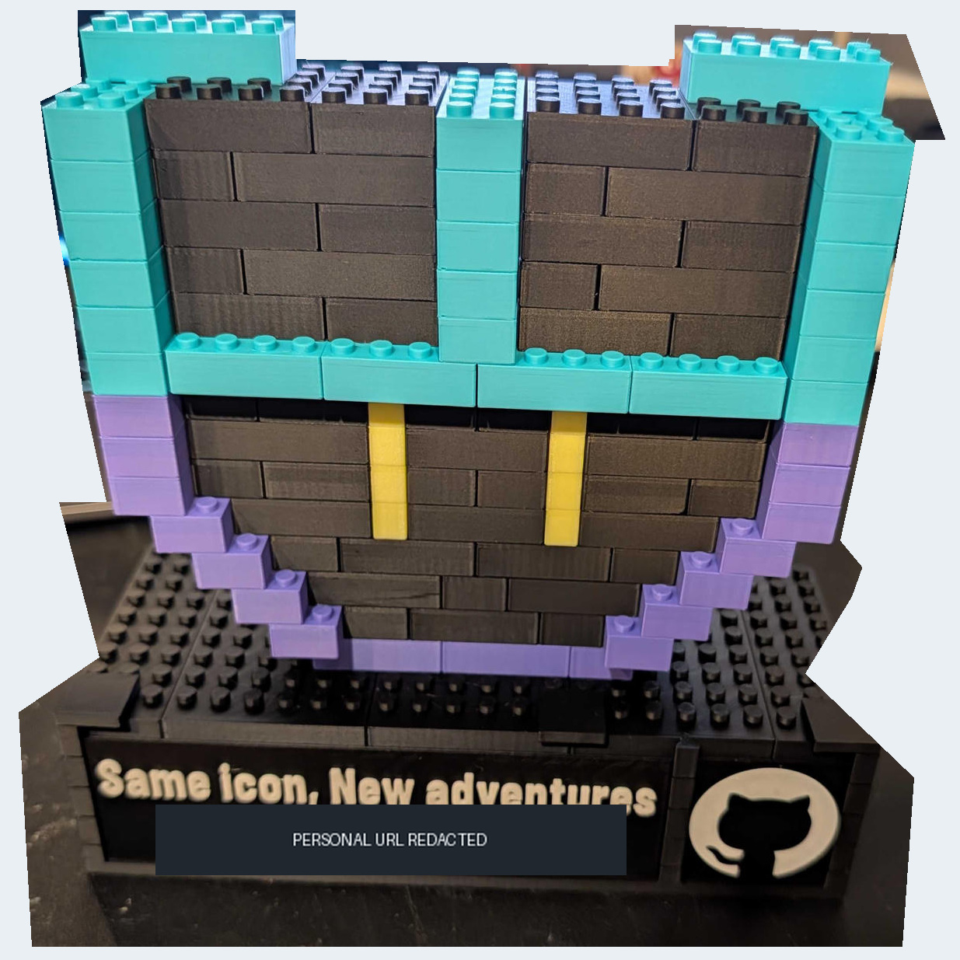
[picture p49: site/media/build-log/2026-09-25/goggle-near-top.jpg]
09/25の補足写真08：頭頂の仕上げ前のゴーグル部分。左右の黒い面とシアンの中央列が見える


**09/25・写真08。** 頭頂を仕上げる前の姿を別に記録したものです。補足写真の並びを撮影順としては扱っていません。

実物の紫・黄は、これまでの制作例と同じ実制作の配色です。公開設計のmagenta／greenを変更せず、
写真を塗り替えたり、写っていない部品をCGで補ったりしていません。
9/23・9/24の「まだ写っていない」という説明は、その報告時点の記録として以下に残しています。

### 3Dプリントの動画（ユーザー提供）

**AIでLEGO風ブロックを設計して3Dプリント｜GitHub Copilot × FreeCAD × Blender**

<div class="postprocess-video" style="width:100%;max-width:100%;aspect-ratio:16/9">
<iframe src="https://www.youtube-nocookie.com/embed/sinN3dKGwRg?playsinline=1" title="AIでLEGO風ブロックを設計して3Dプリント｜GitHub Copilot × FreeCAD × Blender" style="display:block;width:100%;height:100%;border:0" loading="lazy" referrerpolicy="strict-origin-when-cross-origin" allow="encrypted-media; picture-in-picture; fullscreen" allowfullscreen></iframe>
</div>

ユーザーから「3Dプリントの動画」として紹介された制作記録です。▶を押すと、このページ内で再生できます。
再生できない場合の補助リンク：[3Dプリント動画をYouTubeで見る](https://youtu.be/sinN3dKGwRg)。

### 印刷後の後処理：超音波洗浄（ユーザー提供動画）

**3Dプリント後のパーツを超音波洗浄｜Ultrasonic Cleaning of 3D-Printed Parts**

<div class="postprocess-video" style="width:100%;max-width:100%;aspect-ratio:16/9">
<iframe src="https://www.youtube-nocookie.com/embed/Lc_enNE3nng?playsinline=1" title="3Dプリント後のパーツを超音波洗浄｜Ultrasonic Cleaning of 3D-Printed Parts" style="display:block;width:100%;height:100%;border:0" loading="lazy" referrerpolicy="strict-origin-when-cross-origin" allow="encrypted-media; picture-in-picture; fullscreen" allowfullscreen></iframe>
</div>

ユーザーから「3D Print後の超音波洗浄」として紹介された制作の参考動画です。
上の公式YouTubeプレーヤーの▶を押すと、このページ内で再生できます。
再生できない場合の補助リンク：[超音波洗浄動画をYouTubeで見る](https://youtu.be/Lc_enNE3nng)。

**この2本の動画欄はオンライン限定です。** 自動再生はしません。プライバシー強化モードでもYouTubeへの第三者通信は発生します。
動画・音声・サムネイルをこのrepoへ保存・再アップロードしてはいません。
写真・3Dガイドのオフライン配布は従来どおり利用できますが、`file://`では動画の参照元制約により再生できない場合があります。
その場合は[動画小節のWeb版を開いてください](https://ktanino10.github.io/copilot-brick-display/build-log.html#printing-video)。

並びはユーザー申告の制作フロー「3Dプリント → 超音波洗浄」に合わせた説明順です。
タイトルは公開メタデータで確認していますが、本編の機器・プリンタ設定・洗浄液・温度・時間・効果は未確認です。
超音波洗浄を今回取り入れた後処理として記録しており、一般に必須の工程や、安全検証済みのレシピとしては案内していません。

## 2026-09-24 — 顔下部を組み立てる途中

本人の言葉は「こちらは組み立ての途中記録になります」です。
台座と前面部品の上に顔下部が加わった、**組立途中**の記録として掲載します。
主に見える状態を四つに分け、同じ状態の別角度は補足へまとめます。
**以下の四段階は説明上の整理で、CADの工程番号や添付・撮影の時系列ではありません。**

写真で見える**紫・黄は実制作例の配色**です。公開設計のmagenta／greenとは区別し、
この記録を配色の再設計依頼とは扱いません。公開のSTL・BOM・色指定・全配置は変更していません。

### 09/24・01 — 台座の上に低い紫のブロック列

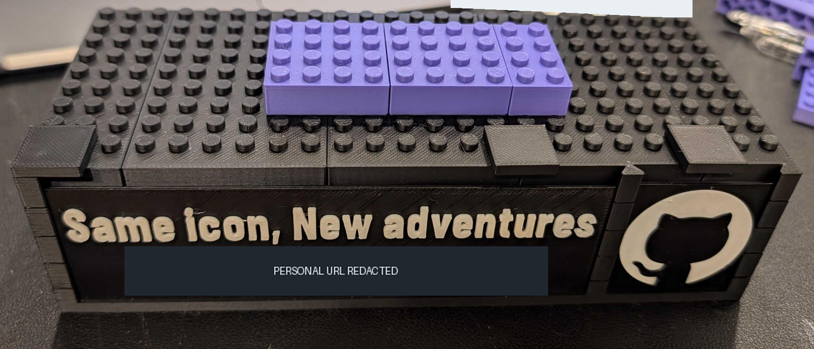
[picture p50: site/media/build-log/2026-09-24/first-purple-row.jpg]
09/24の実物写真01：銘板と右ロゴが付いた黒い台座の上に低い紫色のブロック列。個人行は不透明帯で非表示


**09/24・写真01。** 台座と前面部品の上に、低い紫色のブロックが横に並んでいます。
この写真をCADの特定の工程番号へ対応付けたり、実物の個数・寸法・着座状態を測定したりした記録ではありません。

### 09/24・02 — 黒い層と段付きの左右輪郭

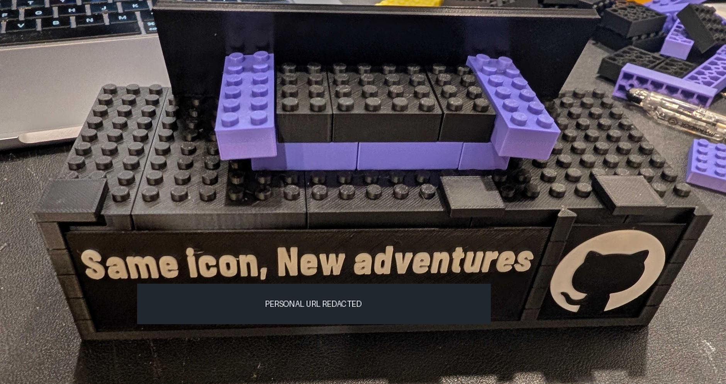
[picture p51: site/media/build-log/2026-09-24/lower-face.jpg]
09/24の実物写真02：黒い顔下部と紫色の左右輪郭を積んだ途中。背面の黒い板状物の用途は未確認


**09/24・写真02。** 黒いブロックの層と、左右に段差を持つ紫色の輪郭が見えます。
背面の黒い板状物は写っているものの、製品の部品・固定具・補強のどれなのかは確認されていません。

### 09/24・03 — 黄色い縦2列が見える顔下部

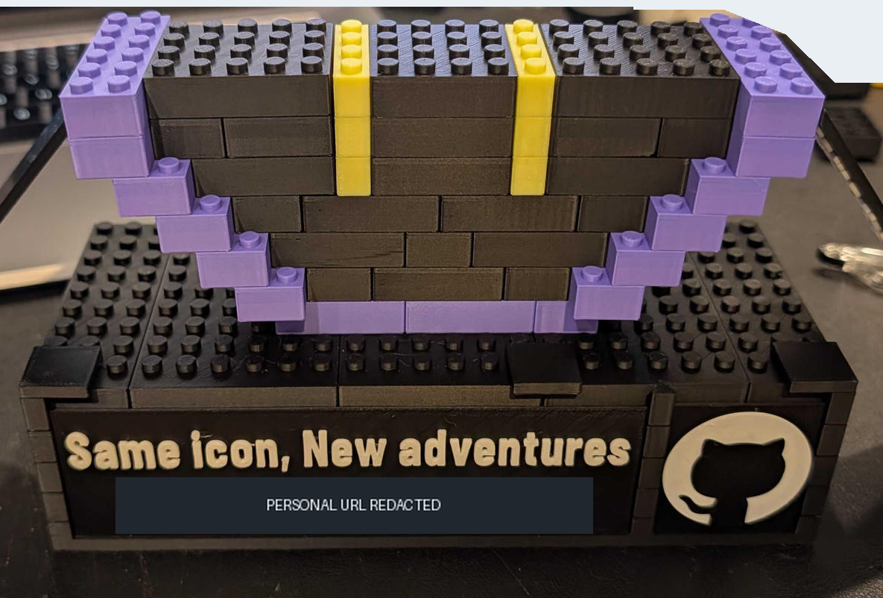
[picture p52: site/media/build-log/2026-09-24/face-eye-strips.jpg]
09/24の実物写真03：黒い顔下部の中に黄色い縦2列、左右と下に紫色の輪郭が見える途中状態


**09/24・写真03。** 黒い面の中に黄色い縦2列が見えます。紫・黄は写真の実制作例の色として記録しています。
公開設計のmagenta／greenを更新したり、写真の色で公開STLやBOMを置き換えたりはしていません。

### 09/24・04 — 上側に黒い列が加わった状態

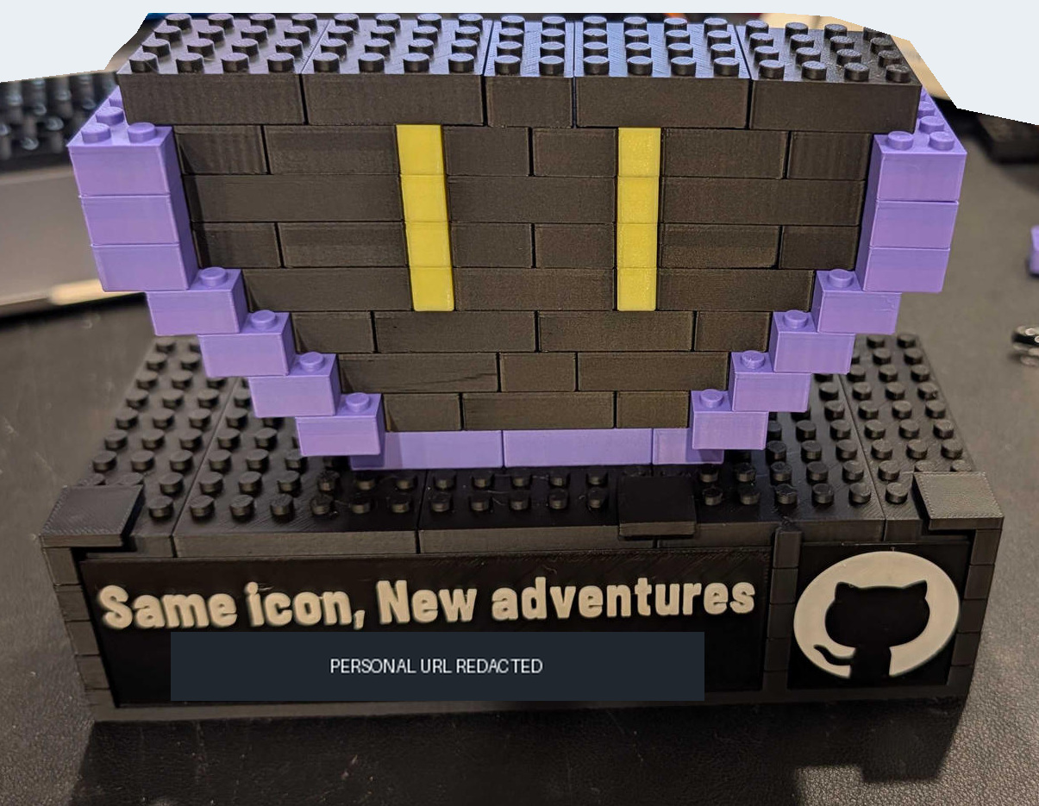
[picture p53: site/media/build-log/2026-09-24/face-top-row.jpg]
09/24の実物写真04：黄色い縦2列の上側に黒い横列がある顔下部。上部ゴーグルや頭頂はまだ付いていない


**09/24・写真04。** 縦2列の上側に黒い横列があり、顔下部の範囲が広がった途中の状態が見えます。
上部ゴーグル・頭頂はまだ付いていない段階として扱い、完成全体や強度の確認写真とは呼びません。

### 09/24・補足 — 別角度で見る同じ途中段階

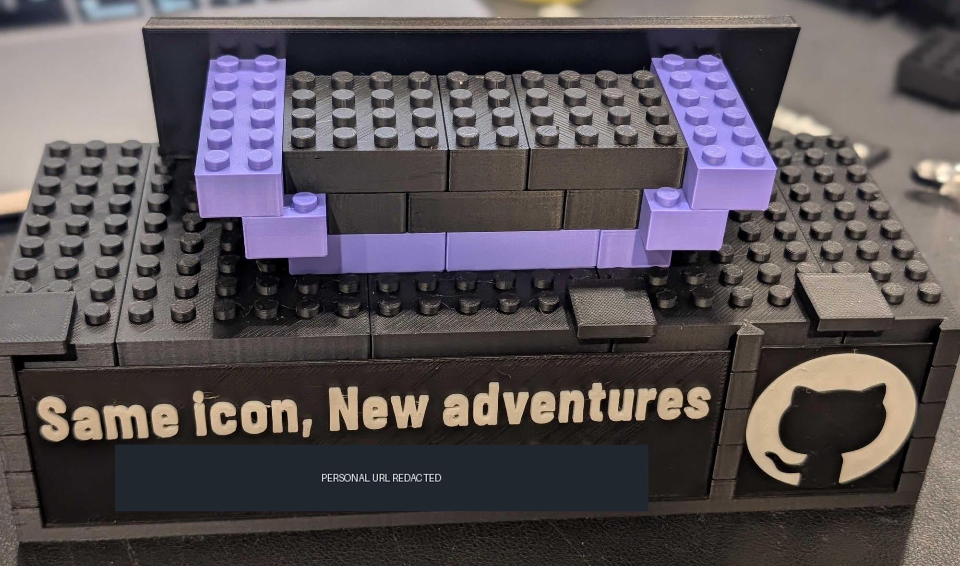
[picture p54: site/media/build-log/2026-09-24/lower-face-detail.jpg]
09/24の補足写真05：顔下部と紫色の段付き輪郭を近くから写した別角度


**09/24・写真05。** 黒い層と紫色の左右輪郭を近くから写した補足です。写真02から新たな工程が増えたとは断定しません。

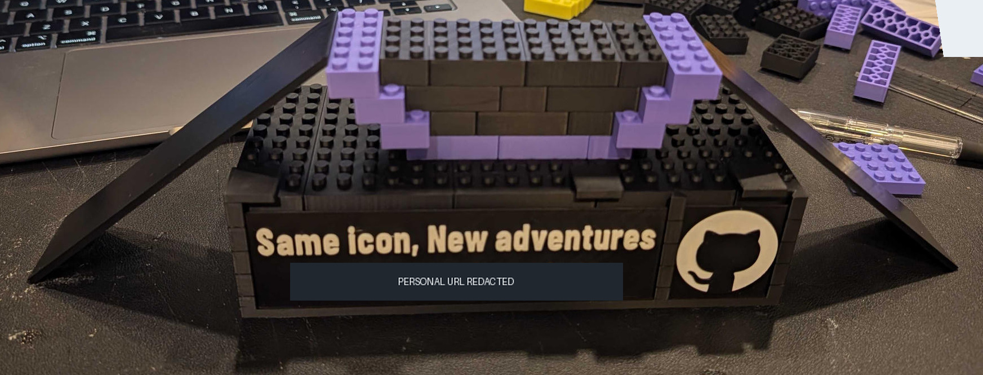
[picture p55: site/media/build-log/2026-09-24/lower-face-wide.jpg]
09/24の補足写真06：顔下部と左右に斜めに置かれた黒い板状物。板状物の用途や固定方法は未確認


**09/24・写真06。** 顔下部と周辺が見える別角度です。左右の板状物が何を支えているか、何のために置かれたかは推測しません。

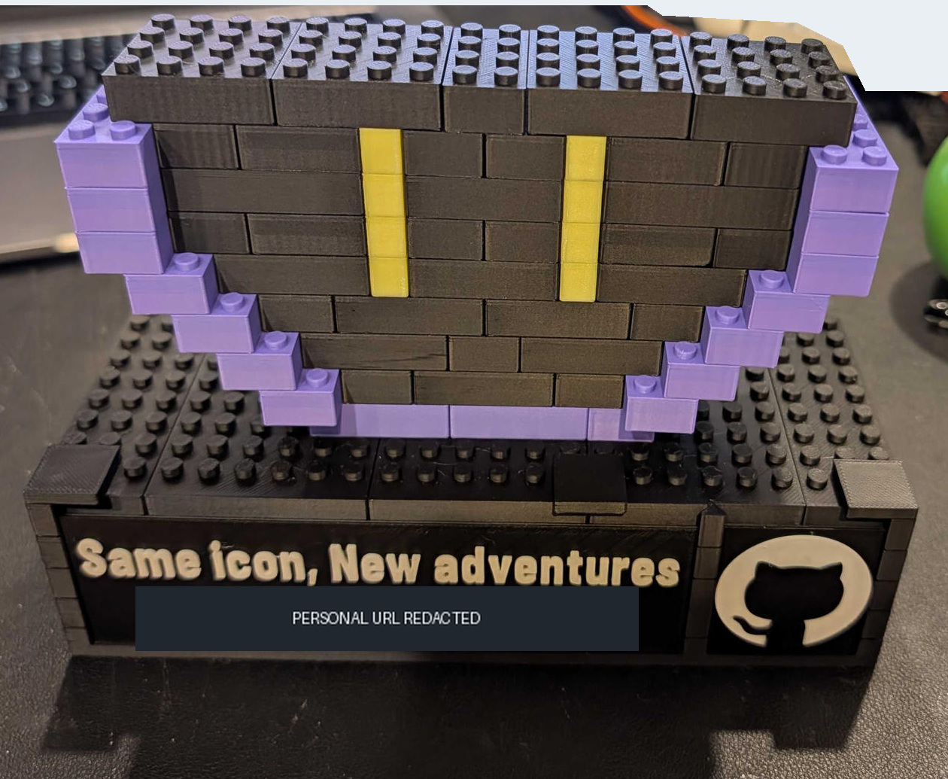
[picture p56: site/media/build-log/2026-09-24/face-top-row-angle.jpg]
09/24の補足写真07：上側の黒い列と黄色い縦2列が見える顔下部を別角度から撮影


**09/24・写真07。** 写真04に近い途中状態を別角度で示しています。番号は説明順で、撮影時刻やCAD工程番号ではありません。

背面や左右に立てたり斜めに置かれたりした**黒い板状物の用途は未確認**です。
保持具・必須部品・補強材・失敗対策とは断定しません。写真から隠れた部品や接続を補っていません。
この段階では顔下部の途中写真があり、上部ゴーグル・頭頂の完成は未確認です。
顔全体や全150部品の完成、強度・荷重・保持力を示す記録ではありません。

## 2026-09-23 — 台座と前面モジュール

以下は前回の9枚です。写真と当時の報告を残し、09/24の進捗と混同しないよう日付を分けています。

### 01 — 文字の隙間・印刷しやすさの相談

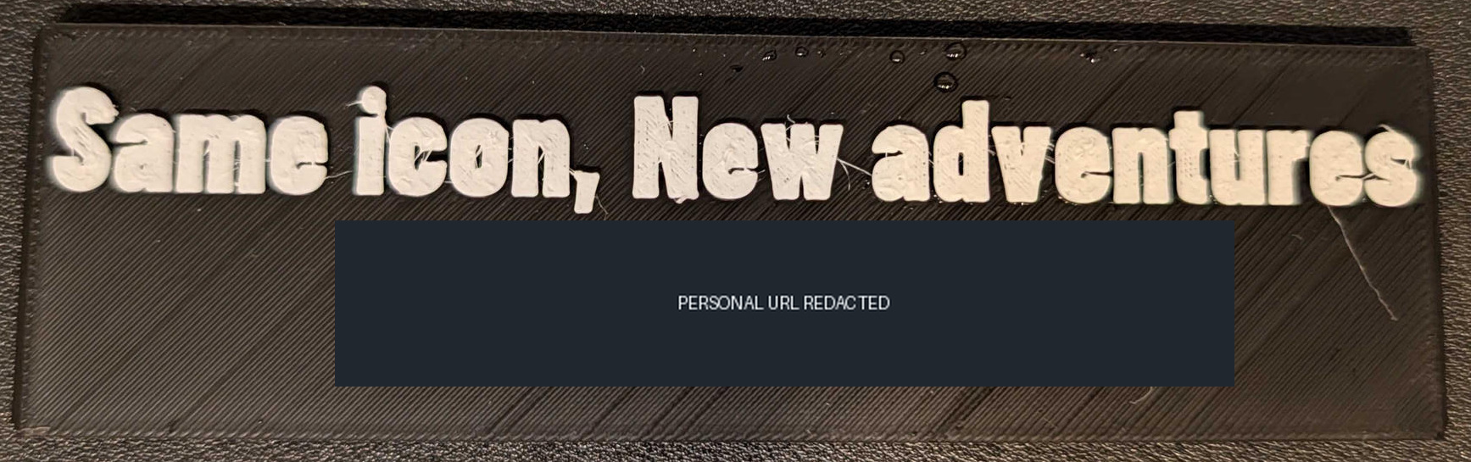
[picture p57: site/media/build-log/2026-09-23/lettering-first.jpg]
実物写真01：相談時の白い主文。個人アカウント行は画像に焼き込んだ不透明帯で伏せた


**写真01／報告日09/22。** 白い主文の字間に糸状のものや、文字表面の荒れが見えます。
本人の「小さい・隙間が狭い」という相談の記録であり、写真から最小孔径や温度・flowを測定・推定したものではありません。
下段の帯は掲載時のプライバシー処理で、造形物の一部ではありません。

### 02 — 調整・再試作についての追加報告

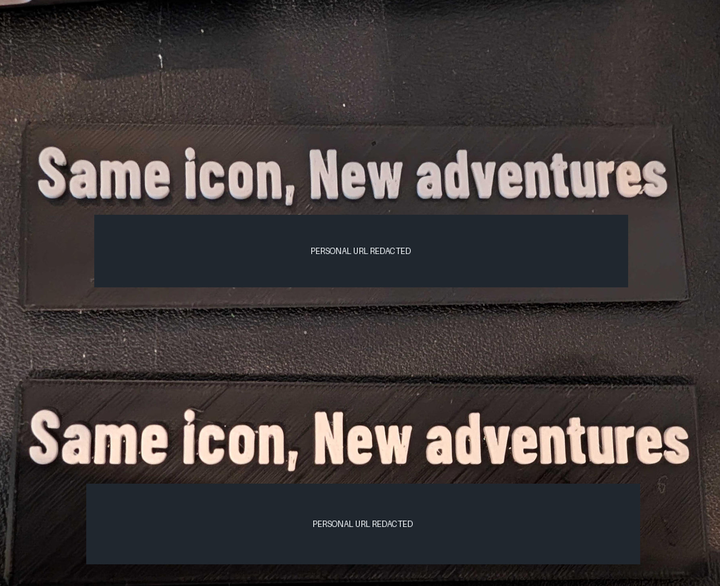
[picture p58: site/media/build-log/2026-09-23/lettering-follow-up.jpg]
実物写真02：主文の見える銘板2枚。各個人行は不透明帯で伏せた


**写真02／報告日09/23。** 銘板2枚を並べた写真と「いけているみたい」という本人の言葉が届きました。
各板がどの印刷ファイル・条件に対応するかは未照合です。**上が旧版・下が新版などとは断定しません。**
孔や字間を改善した設計の数値は、[公開版5.0のCAD記録](lettering.ja.md)へ分けて記載しています。

### 03 — 前面が空の黒い台座

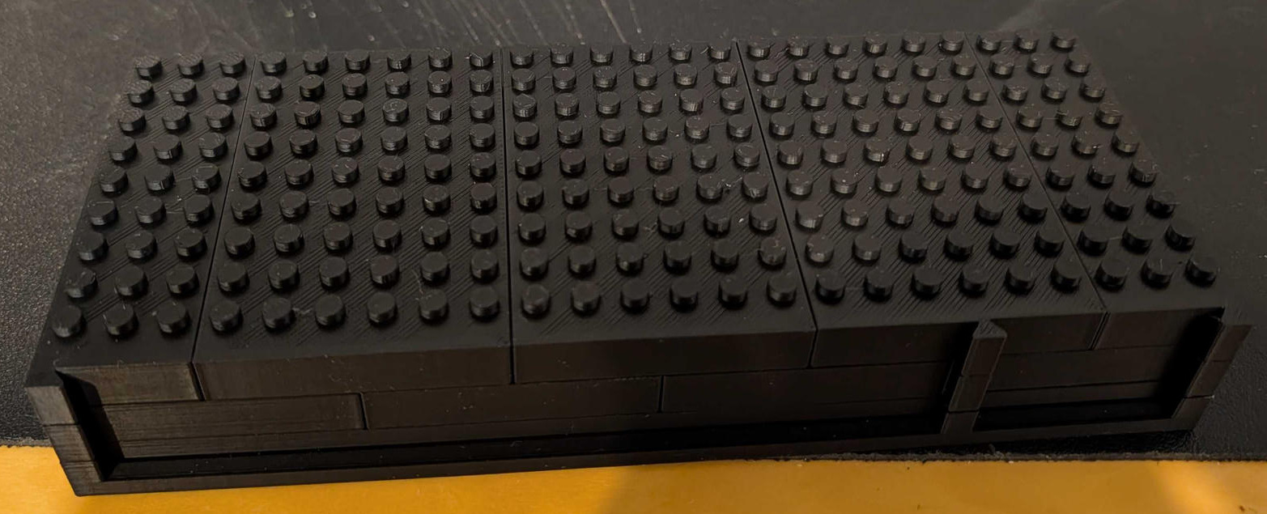
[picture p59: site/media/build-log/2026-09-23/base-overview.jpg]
実物写真03：黒いブロックを積んだ台座。前面の銘板用とロゴ用の領域は空いている


**写真03／報告日09/23。** 台座の上面スタッド、ブロックの継ぎ目、前面の二つの取付け領域が見えます。
全5段を下から順に撮影した連続記録ではなく、部品数・段数・寸法の実測記録でもありません。

### 04 — 右ロゴを取り付けた状態

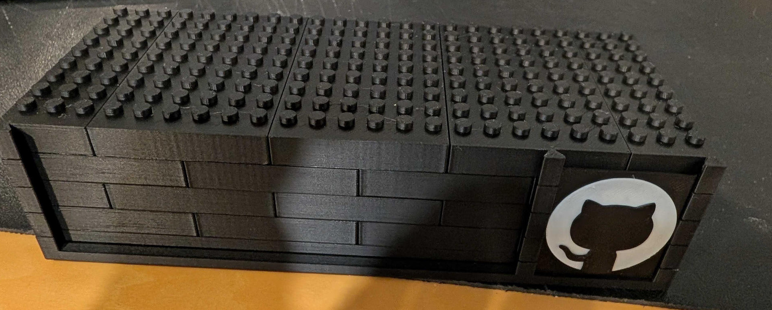
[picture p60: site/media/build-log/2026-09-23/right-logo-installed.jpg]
実物写真04：右のロゴが入った台座。左の銘板領域は空いている


**写真04／報告日09/23。** 右ロゴが装着され、左の銘板を入れる領域が空いています。
写真で見える装着状態を示すもので、保持力、着脱回数、向きや色の設計との完全一致を認定しません。

### 05 — 銘板と右ロゴが付いた土台

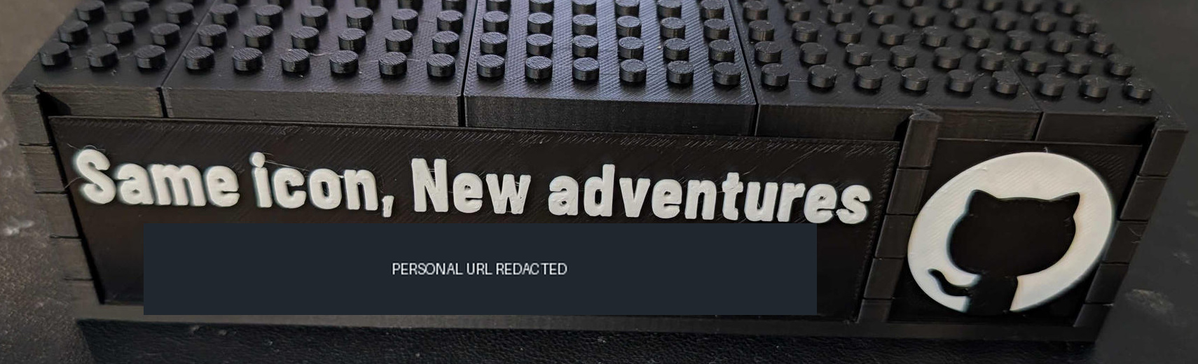
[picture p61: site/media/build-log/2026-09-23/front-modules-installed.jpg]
実物写真05：台座の正面に主文の銘板と右ロゴを装着。個人行は不透明帯で伏せた


**写真05／報告日09/23。** 「土台が組み上がりました」という報告とともに、
台座に銘板・右ロゴが取り付けられた状態が確認できました。顔・ゴーグルの完成全体は、この写真には写っていません。
個人行を覆った帯の下へ公開の仮文字を合成しておらず、公開版 `USER` を印刷済みと示す写真ではありません。

### 補足ギャラリー — 同じ台座を別角度から

以下は積層・継ぎ目・前面領域の見え方を補う写真です。**別々の新しい工程ではありません。**
写真番号は説明順のみで、製作・撮影の順番を保証しません。

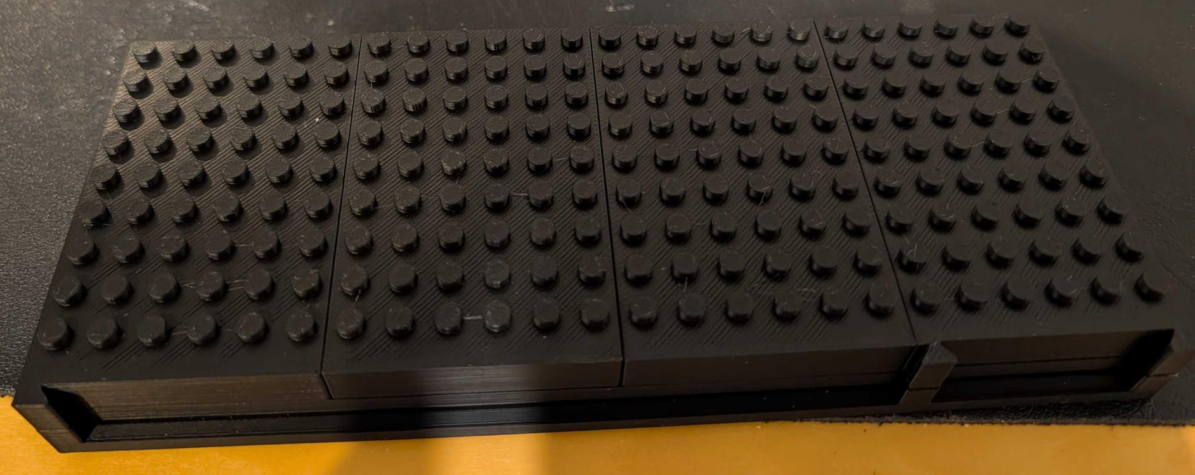
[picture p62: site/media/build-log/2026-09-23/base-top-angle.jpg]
補足写真06：上面のスタッドと継ぎ目を写した台座


**写真06。** 上面のスタッドとブロックの継ぎ目が分かる角度。寸法を画像から割り出してはいません。

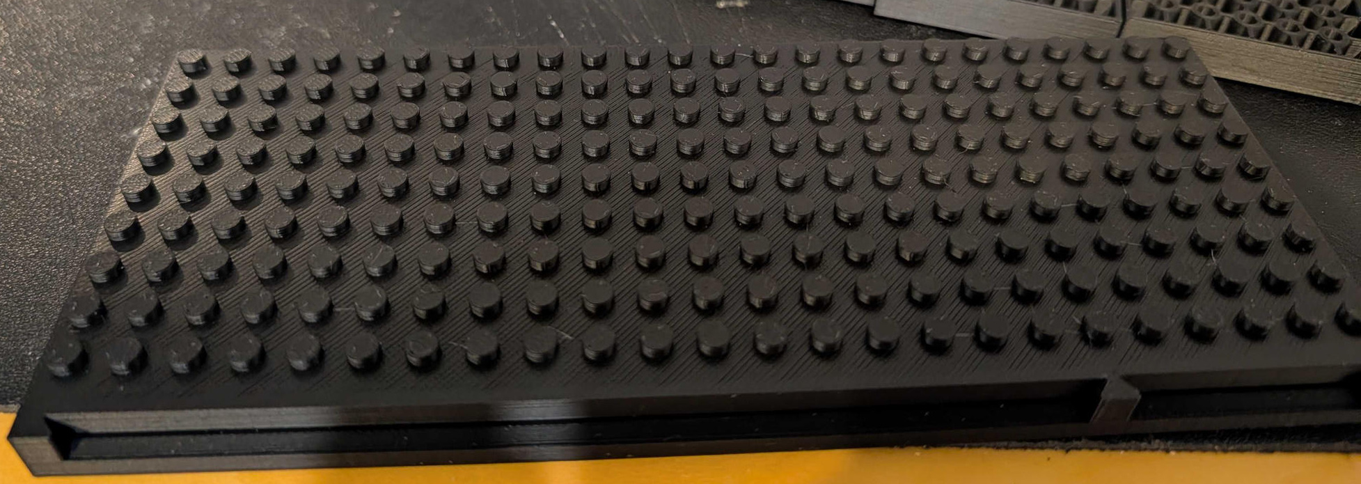
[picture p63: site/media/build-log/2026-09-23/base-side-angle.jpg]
補足写真07：黒い台座を側面寄りから写した別角度


**写真07。** 同じ台座の別角度。未撮影の組立操作を補ったCGではありません。

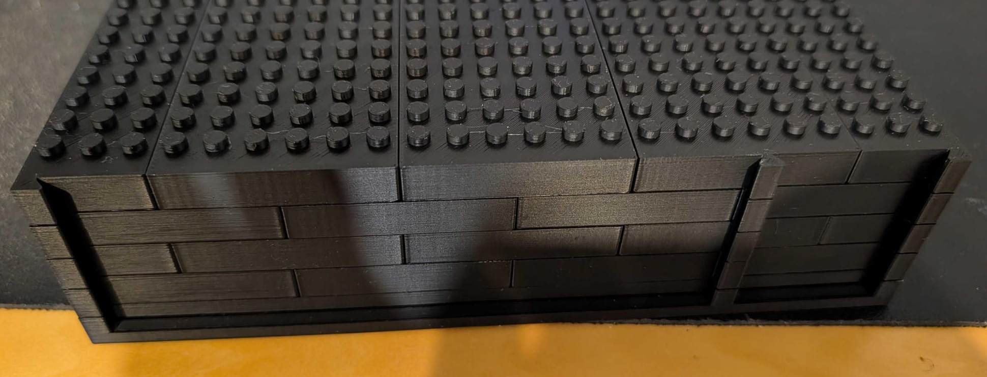
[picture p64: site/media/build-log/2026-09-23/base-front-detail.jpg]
補足写真08：前面の空溝とブロックの継ぎ目


**写真08。** 前面の継ぎ目と取付け領域。写真から実際のクリアランス値は算定しません。

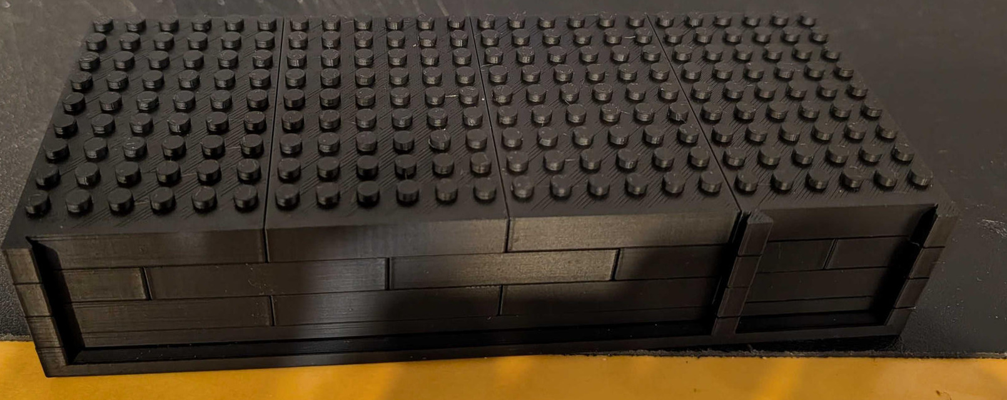
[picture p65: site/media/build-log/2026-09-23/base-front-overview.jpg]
補足写真09：前面部品を入れる前の台座全景


**写真09。** 前面パーツを入れる前の全景です。写真03と同じ段階の補足であり、工程が一つ増えたという意味ではありません。

## 写真観察と検証の境界

本人の完成報告と全体写真により、**個人向けBの完成**を記録しました。
使用STLハッシュと実preset・設定入り`.3mf`は未照合です。写真は全150部品の個別照合や、測定されたkeeper保持力・荷重・強度・転倒・寿命、
量産・玩具認証を示すものではありません。公開の汎用文字版・A/Cの実物成功へも広げません。
公開版5.0のデジタル検証と`NOT_SLICED`の区分はそのままで、写真だけで物理試験を合格に変更していません。
周辺の黒い板状物の用途も未確認のままです。

次に作る方は[印刷手順](build.ja.md#print-another-pc)の少量試作から進め、個人情報を含む実設定や原写真は公開Issueへ置かないでください。

## これから作る方へ

同じ形を組むときに必要な場所・部品は、[Bの対話3D組立ガイド](../site/assembly-guide/B.html)で確認できます。
写真番号ではなく、実際にできているところに対応する**組立工程**を選びます。
この記録のために印刷マスター、STL／3MF、CAD、BOM、既存動画を変更していません。

[別PC・色別印刷の手順](build.ja.md#print-another-pc) ／ [仕分けと1個ずつの組立](assembly.ja.md) ／
[文字の小試験片と測定値](lettering.ja.md)

## 写真の利用範囲

公開画像は、09/23の9枚、09/24の7枚、09/25の8枚、計24枚です。
09/23の9枚とそのハッシュ、寸法、報告日、加工内容は[09/23の公開画像manifest](../site/media/build-log/2026-09-23/manifest.json)に記録しています。
09/24の7枚は[09/24の公開画像manifest](../site/media/build-log/2026-09-24/manifest.json)に分け、撮影日時は未確定のままです。
09/25の8枚も[09/25の公開画像manifest](../site/media/build-log/2026-09-25/manifest.json)にハッシュ・寸法・報告日・加工範囲を記録し、撮影日時は未確定にしています。
前回分は向きの補正・対象物への切り抜き・メタデータ除去を行い、個人行が写る3画像の計4箇所には、
「PERSONAL URL REDACTED」と書いた不透明帯を**画像の画素へ焼き込み**ました。
09/24分も全7枚の個人行を不透明画素で伏せ、背景のPC画面・別の文字板・包装ラベルなどの該当箇所を
切り抜き、または薄いグレーの不透明画素で除去しています。残っているキーボード・机・部品・黒い板状物から、その用途を推定しません。
09/25分は作品周辺の背景を薄いグレーの不透明画素へ置き換え、全8枚の個人行を暗い不透明帯で覆っています。
切り抜きと背景処理の境界は画像に見える状態です。一部の帯が主文下端に少しかかるのは識別情報を確実に伏せる余白であり、造形の欠けではありません。
**背景マスクは識別情報を除くためで、作品の造形補修ではありません。**
CSSの覆いや半透明・ぼかしではなく、配布JPEGとそのまま開けるリンク先も同じ処理済み画像です。
糸引き、表面の荒れ、隙間を隠す造形上のレタッチや、写っていない部品を補う合成はしていません。

写真は、ユーザーが**一般向け・個人向けの両repoでの制作記録への掲載**を承認したものです。
公開するのは識別情報を伏せた派生画像だけで、未加工写真・個人URL・撮影位置・EXIF・元ファイル名は含めません。
モデルやライブラリのライセンスが写真へ自動適用されるわけではなく、**CC0化や第三者への再配布許諾を意味しません**。
写真の権利は権利者に留保されます。再利用は権利者へ確認してください。MakerWorldや別のSNSへの掲載許可でもありません。

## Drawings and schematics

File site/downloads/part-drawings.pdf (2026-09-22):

### BRICK PORTRAIT / PUBLIC TEMPLATE / 5-COURSE BASE / DIGITAL PROTOTYPE

# NP3-KEEPER

Three orthographic views + underside from the actual solid. Exterior heights include studs / text.

## FRONT

15.80

3.20

## SIDE

15.80

TOP / PRINT ORIENTATION | BOTTOM / REAL CAVITIES

Kind: front_keeper

STL: NP3-KEEPER.stl

STL units: mm / scale 100%

Grid: 2 x 1 @ 8.00

Body height: 3.20

Female radial c: +0.04

Outer wall: 1.46

Tube bore: 3.20 (not accessory fit)

Roof ribs: 1.20; bridge gap <=6.80

Socket row at local Y=12.00

Flat front stop covers module top

Lift 6mm, then forward >=32mm and aside

UNITS mm | Fixed 8 mm pitch | Physical fit / strength / stability NOT tested | Do not scale STL. Calibrate male + female coupons first.

# BASE3-18x08-B-a4853c

Three orthographic views + underside from the actual solid. Exterior heights include studs / text.

## FRONT

143.80

11.40

## SIDE

63.80

TOP / PRINT ORIENTATION | BOTTOM / REAL CAVITIES

Kind: front_base

STL: BASE3-18x08-B-a4853c.stl

STL units: mm / scale 100%

Grid: 18 x 8 @ 8.00

Body height: 9.60

Stud: dia 4.80 x 1.80 high

Tip lead-in: 0.25 high / radial

Female radial c: +0.04

Outer wall: 1.46

Tube bore: 3.20 (not accessory fit)

Roof ribs: 1.20; bridge gap <=6.80

Front row reserved (no stud/socket)

NP3 dovetail side allowance: 0.20

See front-interface.svg for sections

# BASE3-06x08-T-b8aa05

Three orthographic views + underside from the actual solid. Exterior heights include studs / text.

## FRONT

47.80

11.40

## SIDE

63.80

TOP / PRINT ORIENTATION | BOTTOM / REAL CAVITIES

Kind: front_base

STL: BASE3-06x08-T-b8aa05.stl

STL units: mm / scale 100%

Grid: 6 x 8 @ 8.00

Body height: 9.60

Stud: dia 4.80 x 1.80 high

Tip lead-in: 0.25 high / radial

Female radial c: +0.04

Outer wall: 1.46

Tube bore: 3.20 (not accessory fit)

Roof ribs: 1.20; bridge gap <=6.80

Front row reserved (no stud/socket)

NP3 dovetail side allowance: 0.20

See front-interface.svg for sections

# BASE3-06x08-T-9cb610

Three orthographic views + underside from the actual solid. Exterior heights include studs / text.

## FRONT

47.80

11.40

## SIDE

60.40

TOP / PRINT ORIENTATION | BOTTOM / REAL CAVITIES

Kind: front_base

STL: BASE3-06x08-T-9cb610.stl

STL units: mm / scale 100%

Grid: 6 x 8 @ 8.00

Body height: 9.60

Stud: dia 4.80 x 1.80 high

Tip lead-in: 0.25 high / radial

Female radial c: +0.04

Outer wall: 1.46

Tube bore: 3.20 (not accessory fit)

Roof ribs: 1.20; bridge gap <=6.80

Front row reserved (no stud/socket)

NP3 dovetail side allowance: 0.20

See front-interface.svg for sections

# BASE3-06x08-T-7f51dc

Three orthographic views + underside from the actual solid. Exterior heights include studs / text.

## FRONT

47.80

11.40

## SIDE

63.80

TOP / PRINT ORIENTATION | BOTTOM / REAL CAVITIES

Kind: front_base

STL: BASE3-06x08-T-7f51dc.stl

STL units: mm / scale 100%

Grid: 6 x 8 @ 8.00

Body height: 9.60

Stud: dia 4.80 x 1.80 high

Tip lead-in: 0.25 high / radial

Female radial c: +0.04

Outer wall: 1.46

Tube bore: 3.20 (not accessory fit)

Roof ribs: 1.20; bridge gap <=6.80

Front row reserved (no stud/socket)

NP3 dovetail side allowance: 0.20

See front-interface.svg for sections

# BASE3-03x08-T-48de52

Three orthographic views + underside from the actual solid. Exterior heights include studs / text.

## FRONT

23.80

11.40

## SIDE

63.80

TOP / PRINT ORIENTATION | BOTTOM / REAL CAVITIES

Kind: front_base

STL: BASE3-03x08-T-48de52.stl

STL units: mm / scale 100%

Grid: 3 x 8 @ 8.00

Body height: 9.60

Stud: dia 4.80 x 1.80 high

Tip lead-in: 0.25 high / radial

Female radial c: +0.04

Outer wall: 1.46

Tube bore: 3.20 (not accessory fit)

Roof ribs: 1.20; bridge gap <=6.80

Front row reserved (no stud/socket)

NP3 dovetail side allowance: 0.20

See front-interface.svg for sections

# BASE3-06x08-T-7532db

Three orthographic views + underside from the actual solid. Exterior heights include studs / text.

## FRONT

47.80

11.40

## SIDE

63.80

TOP / PRINT ORIENTATION | BOTTOM / REAL CAVITIES

Kind: front_base

STL: BASE3-06x08-T-7532db.stl

STL units: mm / scale 100%

Grid: 6 x 8 @ 8.00

Body height: 9.60

Stud: dia 4.80 x 1.80 high

Tip lead-in: 0.25 high / radial

Female radial c: +0.04

Outer wall: 1.46

Tube bore: 3.20 (not accessory fit)

Roof ribs: 1.20; bridge gap <=6.80

Front row reserved (no stud/socket)

NP3 dovetail side allowance: 0.20

See front-interface.svg for sections
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

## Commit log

2026-09-19 Define fixed-grid portrait layouts and tested message connector
    Keep A/B/C as distinct layouts; add independent fit candidates, roof bracing, and a removable exact-text card. Digital prototype only; physical fit remains unverified.
2026-09-19 Generate three real CAD assemblies and manifold print meshes
    Freeze fixed-grid geometry, exact BOM/placements, native colors and message module. Physical fit remains untested; independent assembly checks and review follow.
    [BR-01x02-H096.stl, BR-01x04-H096.stl, BR-01x06-H096.stl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]
2026-09-19 Integrate the bounded YOUR-USERNAME tribute mechanical snapshot
    Import final tree c84423b without intermediate CAD backup history. Keep the addition separate from the three brick portraits; adhesive approval and final media/documentation follow.
    [FIT-F-CM04.step, FIT-F-CM04.stl, FIT-F-CP00.step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]
2026-09-19 Deliver CAD drawings, print packages, Blender assemblies and the interactive workshop
    Include actual rendered and decoded A/B/C movies, 32/40/47-page construction PDFs, real generic 3MF layouts, beginner instructions, local WebGL controls, privacy checks and Pages deployment. Physical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
    [A-black-01.3mf, A-black-02.3mf, A-green-01.3mf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]
2026-09-19 Publish YOUR-USERNAME drawings, assembly film and Japanese build guide
    Add six CAD-derived sheets, a verified native Blender animation and H.264 movie with Japanese subtitles, static GLB, color BOM, print pack, responsive standalone site and relative-URL manifest. Prese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
    [bom.csv]
2026-09-19 Make pending adhesive approval prominent on tribute pages
    Place the manufacturing hold before the hero, repeat it in the hero label and guide opening, and explicitly prohibit assembling the adhesive-dependent relief as a glueless version. Regenerate public 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
2026-09-19 Expose the separate tribute design candidate with an explicit release hold
    Mirror only hash-verified public assets and linked rebuild sources. Keep adhesive authorization pending and separate from the no-glue A/B/C print packages.
    [FIT-F-CM04.step, FIT-F-CM04.stl, FIT-F-CP00.step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]
2026-09-19 Lift the message card clear before exploded-view lateral motion
    Reproduce the independent review's 89.76 cubic-mm overlap and eliminate it across all 303 native CAD slider samples. Keep the saved CAD and real assembly movies unchanged.
2026-09-19 Withdraw rejected adhesive downloads and gate Pages on clean browser validation
    Apply the user's confirmed requirement that every tribute part is removable without adhesive. Publish only its redesign status while the original A/B/C remain complete and separate. Preserve saved CAD/media and use an isolated CI browser after local browser startup failures.
    [FIT-F-CM04.step, FIT-F-CM04.stl, FIT-F-CP00.step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]
2026-09-19 Replace adhesive relief with reversible flange-capture mechanics
    T2 uses rear-loaded flanged inserts, nested removable eyes and M, a supported back cover and four replaceable printed coarse screws. Preserve shared message and 8 mm interface. Verify 78-instance native/STEP, 59 manifold print masters, 3003 disjoint BRep pairs, all 69 insert cages and removal/tool paths, screw pull-blocking and helical release. Presentation is regenerated in the next snapshot.
    [ASSEMBLY-REST.step, ASSEMBLY-REST.stl, BADGE-M.step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]
2026-09-19 Resolve T2 frame print orientation and bounded ejector access
    Print T02 and CAPTURE-FRAME front-face down and persist inverse assembly transforms. Verify real bed footprints and 78 unchanged assembled placements. Test the complete ejector through 3.5 mm, reproduce the unsafe 9.5 mm collision, and require flange withdrawal afterward. Add actual assembly-rest and print-pose evidence for the same reviewer.
    [ASSEMBLY-REST.step, BADGE-M.step, BADGE-W.step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]
2026-09-19 Deliver synchronized T2-R1 removable tribute fabrication package
    Replace active adhesive-era instructions and media with flange capture, replaceable coarse screws, bounded 3.5 mm tool ejection and inverse print placements. Include assembly/disassembly Blender scenes and fully decoded films, static GLB, ten CAD sheets, librsvg preview provenance, 59-master print pack, dynamic BOM/site and 29 publication regressions. Preserve physical-test and independent final-acceptance gates; record the reproduced Mac Chrome block without claiming a browser pass.
    [bom.csv]
2026-09-19 Resolve final transfer-motion and publication review findings
    Reproduce the263.892mm3 animated collision, keep stand translation on the table, and use rigid vertical plaque insertion after alignment. Verify128 actual native poses and continuous separation/sweep conditions. Rerender only58 frames per movie with boundaries, preserve518 decoded frames each, and decode both final films. Synchronize BADGE-W to90 degrees and eliminate coupon quantities from the BOM tool column and ZIP. Prove122 completed mechanical/display masters unchanged from46c7661.
    [bom.csv]
2026-09-19 Accept and integrate the fully removable T2-R1 tribute package
    Close MR-T2-01 through 05 with the same independent reviewer. Publish only the corrected 192-asset no-adhesive package after a Linux full-Chrome gate for 59 part rows, 10 drawing sheets, two real videos and responsive guides. Physical fit, retention, printed-thread durability and stability remain untested.
    [ASSEMBLY-REST.step, ASSEMBLY-REST.stl, BADGE-M.step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]
2026-09-19 Implement the approved five-course base with independent front text and logo
    Keep the face meshes unchanged except for +38.4mm translation. Add staggered independent base courses, enlarged exact two-line lettering, supported user-mark relief and keyed removable modules. Preserve the complete unselected tribute byte-for-byte. Digital prototype; physical fit and stability remain untested.
    [BASE3-03x08-T-48de52.stl, BASE3-03x08-T-80e081.stl, BASE3-03x10-T-aa77a9.stl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]
2026-09-19 Clear parked keepers before front modules spread in the exploded view
    Derive at least32mm forward escape from the16mm keeper depth,14mm module travel and2mm gap. Reproduce the rejected20mm route and verify corrected native intersections remain zero for A/B/C. Printable geometry is unchanged.
2026-09-19 Complete the approved revision3 documents, media and centered exploded viewer
    Synchronize 45/54/62-page CAD packs,71 print masters,50 separately finished plate layouts, native Blender scenes and real movies with the five-course front design. Preserve all442 tribute hashes. Add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
    [A-black-01.3mf, A-black-02.3mf, A-black-03.3mf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]
2026-09-19 Keep revision navigation fresh and scope model controls to buttons
    Fix the review-run mobile selector collision between model buttons and viewer diagnostics. Preserve the already-passing desktop0/50/100 geometry and all printable/media bytes.
2026-09-19 Verify the exact requested 375-pixel phone viewport
    Replace the inherited390px phone fixture with375px and record/assert actual innerWidth in every exploded-view acceptance result. Printable models and media are unchanged.
2026-09-19 Withdraw personalized distribution during public-template privacy migration
    Preserve the original gift and pending trial guidance privately. Publish a maintenance-only page, neutralize current source labels and withhold generated individual data until genuine generic CAD/med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
    [A-black-01.3mf, A-black-02.3mf, A-black-03.3mf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]
2026-09-19 Publish a generic public template with private personalization and staged trials
    Regenerate the three actual message meshes and their native/rendered/download outputs using explicit placeholders; keep68non-text masters and the mechanical layout unchanged. Withhold the unselected individual variant, provide a tested ignored private-input route and a public-fork Issue/AI/PR guide. Preserve the seven-piece unchanged-part trial and disclose unresolved server retention without republishing private identifiers.
    [A-black-01.3mf, A-black-02.3mf, A-black-03.3mf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]
2026-09-19 Record verified generic publication and bounded privacy-cleanup limits [skip ci]
    Evidence only: current generic native/media/docs/trial downloads match public bytes; full reachable history is clean of identified prior content. Preserve the explicit server-retention limitation and privately held Support draft without publishing withdrawn values or references.
2026-09-19 Explain cross-PC color printing and required manual white-relief changes
    Keep all generic CAD, meshes, color layouts, drawings and media unchanged. Add one-model download guidance, true manifest filenames/counts, NOT_SLICED and duplicate-import warnings, coupon-first stop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
2026-09-19 Clarify B replacement selection and preview-based manual pause timing
    Keep the public kit generic. Explain replacing rather than duplicating one B message plate, layer-height-dependent pause placement, and unverified P1S manual exchange boundaries without adding personal values or G-code.
2026-09-19 Record generic color-print guide delivery evidence [skip ci]
2026-09-20 Guide print files to exact assembly locations with offline 3D steps
    Keep all manufacturing meshes, print placements, CAD and existing Blender media unchanged. Add verified slot-to-placement mapping, interchangeable part sources, stepwise insertion and real-mesh begin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
2026-09-20 Keep guided assembly responsive on low-frame-rate software rendering
    Use elapsed foreground time and cached mesh bounds, update only the moving part, and pause hidden pages. Keep at most one placement advance per frame and retain exact final poses and seated-count sem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
2026-09-20 Record live assembly-guide deployment and offline acceptance [skip ci]
2026-09-22 Improve plaque lettering openings, spacing and supported relief
    Use the explicitly approved short generic placeholder, enlarge URL lettering to10mm and white text to1.2mm, while preserving68 non-text masters and every assembly placement. Add same-scale generic glyph trials, native measurements and consistent CAD/print/media/viewer outputs. Record the natural0.4mm depth increase and keep all physical/slicer qualification limits explicit.
    [A-black-to-white-z2p4-01.3mf, A.FCStd, A.blend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]
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2026-09-22 Derive assembly-document revision from the stamped module URL
    Remove the stale fixed revision from the step selector and show an explicit error rather than leaving a misleading B diagram when catalog loading fails.
2026-09-22 Record verified revision-5 Pages and printable asset delivery [skip ci]
2026-09-23 Document observed B base progress with approved redacted photographs
    Separate user reports, visible photo stages, digital checks and unmeasured physical qualification. Publish only the nine exact sanitized JPEG derivatives, retain photo rights and privacy boundaries, 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
2026-09-23 Record deployed photo journal and unchanged print downloads [skip ci]
2026-09-23 Link the authorized personal B site from generic guides
    Add only the confirmed public landing, 3D assembly and photo-log URLs. Preserve the generic USER display, redacted photographs and all printable/native assets.
2026-09-24 Record September24 lower-face assembly progress with sanitized photos
    Keep the previous nine photos and all manufacturing/native/color/placement assets unchanged. Add seven exact approved public derivatives in four explanatory stages plus alternate views, without claim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
2026-09-24 Record verified September24 journal deployment and immutable print assets [skip ci]
2026-09-25 Celebrate the personalized B completion with approved September25 photos
    Append eight exact sanitized photographs from the goggles build through the completed portrait, preserve the prior sixteen photographs, and keep design/print/native/media assets unchanged. Separate t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
2026-09-25 Link the user-provided ultrasonic-cleaning reference video
    Use the exact public title and external YouTube URL without fetching or embedding video, audio or thumbnails. Keep completion photographs, manufacturing data and the ongoing photo publication run unc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
2026-09-25 Record completed journal deployment and real inline video playback [skip ci]
    Wait for the official iframe overlay to settle before the normal test click. Persist actual desktop/mobile time-advance results, the24-photo Linux/live checks and unchanged print asset hashes; no deployed page or manufacturing file changes.
